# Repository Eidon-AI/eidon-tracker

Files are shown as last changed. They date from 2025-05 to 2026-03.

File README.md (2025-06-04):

# Eidon Tracker

A complete Bluetooth IMU tracking system featuring custom hardware, 3D printed enclosure, and web-based applications. The Eidon Tracker transmits real-time quaternion orientation data over Bluetooth HID, making it perfect for motion capture, gaming, and interactive applications.

<div align="center">
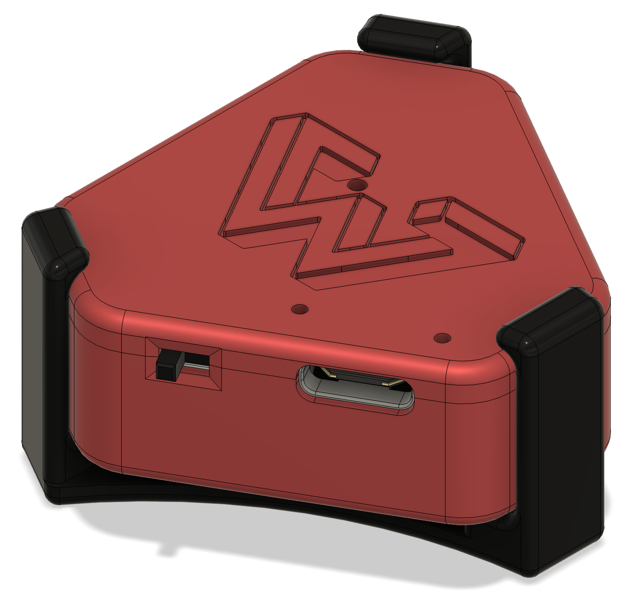
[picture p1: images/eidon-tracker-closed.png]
Eidon Tracker - Closed
  
</div>

## Features

- **High-precision IMU tracking** with BNO085 9-DOF sensor
- **Bluetooth HID device** - appears as standard input device
- **Real-time quaternion data** streaming at 1000Hz
- **Custom 3D printed enclosure** with integrated switches
- **Web-based applications** for visualization and interaction
- **Battery monitoring** with charging status
- **Device color customization** via HID feature reports

## Bill of Materials (BOM)

<div align="center">
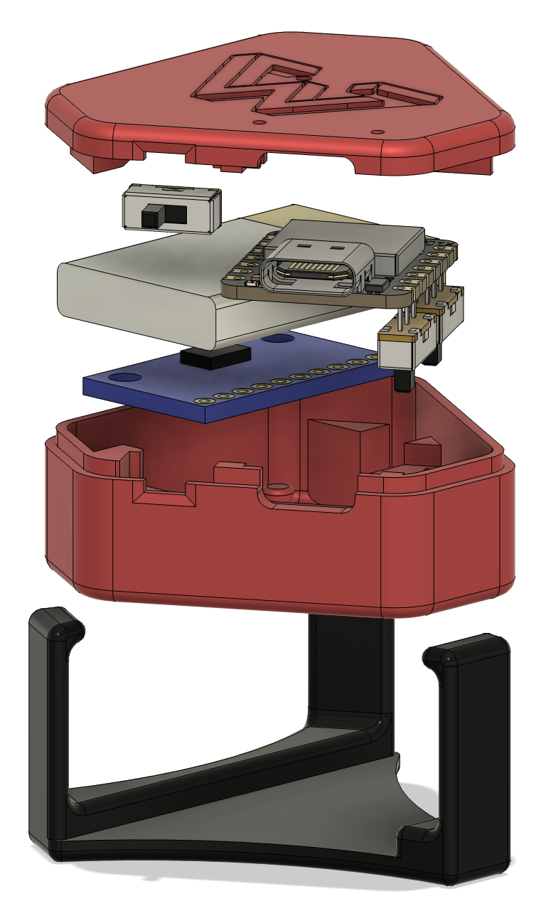
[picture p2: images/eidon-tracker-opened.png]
Eidon Tracker - Open
  
</div>

### Required Components

| Component | Quantity | Description | Purchase Link |
|---|---|---|---|
| [Seeed XIAO nRF52840 Sense](https://www.seeedstudio.com/XIAO-nRF52840-Sense-p-5256.html) | 1 | Main microcontroller with built-in BLE | [Amazon](https://amzn.to/4kR0hSP) |
| BNO085 IMU Breakout | 1 | 9-DOF Absolute Orientation Sensor | [Amazon](https://amzn.to/4mKZSTC) |
| LiPo Battery (3.7V) | 1 | 250mAh recommended | [Amazon](https://amzn.to/4kpmNSK) |
| Toggle Switches (6mm) | 2 | For power and position config | [Amazon](https://amzn.to/3ZfAECM) |
| 30 AWG Wires | 4x ~5cm | Female-to-female, ~20cm | [Amazon](https://amzn.to/4kB8Z7V) |

### 3D Printing Materials

| Material | Quantity | Description |
|---|---|---|
| PLA Filament | ~50g | For enclosure parts |
| Support Material | As needed | If printing with overhangs |

### Tools Required

- 3D Printer
- Soldering iron and solder
- Small screwdriver
- Wire strippers

**Estimated Total Cost**: $80-120 USD

## Hardware Setup

### Wiring Diagram

Connect the BNO085 to the XIAO nRF52840 Sense:

| BNO085 Pin | XIAO Pin | Function |
|---|---|---|
| VIN | 3V3 | Power (3.3V) |
| GND | GND | Ground |
| SDA | D9 | IMU I2C Data |
| SCL | D10 | IMU I2C Clock |
| INT | D8 | IMU Interrupt (optional) |

### Switch Connections

| Switch | Output Pin | Input Pin | Function |
|---|---|---|---|
| Left/Right | D5 | D6 | Horizontal orientation |
| Upper/Lower | D0 | D1 | Vertical orientation |

### 3D Printing

Print the following files from the `cad/` directory:

1. `eidon-tracker-base.stl` - Main enclosure base
2. `eidon-tracker-top.stl` - Enclosure lid  
3. `eidon-tracker-mount.stl` - Optional mounting bracket

**Print Settings:**
- Layer Height: 0.2mm
- Infill: 20%
- Support: Yes (for overhangs)
- Material: PLA

## Software Setup

### PlatformIO Installation

1. Install [Visual Studio Code](https://code.visualstudio.com/)
2. Install the [PlatformIO IDE extension](https://platformio.org/install/ide?install=vscode)

### Building and Uploading Firmware

1. Clone this repository:
   ```bash
   git clone https://github.com/yourusername/eidon-tracker.git
   cd eidon-tracker
   ```

2. Open the project in VSCode with PlatformIO

3. Connect your XIAO nRF52840 Sense via USB

4. Build and upload:
   ```bash
   pio run --target upload
   ```

### Dependencies

The following libraries are automatically managed by PlatformIO:

- **Adafruit BNO08x** (v1.2.3+) - IMU sensor driver
- **Adafruit BluefruitLE nRF52** - Bluetooth functionality  
- **Arduino Framework** - Core functionality

## Web Applications

The `web/` directory contains the main interactive application:

### 3D Orientation Visualizer (`index.html`)

- **Real-time 3D visualization** of tracker orientation and movement
- **Multiple camera angles** and viewing modes
- **Bluetooth HID integration** for seamless device connectivity
- **Calibration status monitoring** and quaternion data display

### Running Web Applications

Simply open `web/index.html` directly in your web browser:

1. Navigate to the `web/` directory in your file explorer
2. Double-click `index.html` to open it in your default browser
3. Or right-click and "Open with" your preferred browser (Chrome/Edge recommended for Web Bluetooth support)
4. Connect to your Eidon Tracker via Bluetooth

## HID Reports

The Eidon Tracker implements a custom HID device with multiple report types for data exchange:

### Input Report (Report ID: 1)
**Size**: 9 bytes total
- **Quaternion Data** (8 bytes): Four 16-bit values representing orientation
  - `w` component (bytes 0-1): Scalar part of quaternion
  - `x` component (bytes 2-3): X-axis rotation
  - `y` component (bytes 4-5): Y-axis rotation  
  - `z` component (bytes 6-7): Z-axis rotation
- **Switch States** (1 byte): Two button states plus padding
  - Bit 0: Left/Right switch state
  - Bit 1: Upper/Lower switch state
  - Bits 2-7: Reserved (padding)

### Output Report (Report ID: 1)
**Size**: 1 byte
- **Vendor Command**: Custom command byte for device control
  - Used for device configuration and special commands
  - Values defined in firmware for various operations

### Feature Report (Report ID: 1)  
**Size**: 3 bytes
- **RGB Color Settings**: Device LED color configuration
  - Byte 0: Red component (0-255)
  - Byte 1: Green component (0-255)
  - Byte 2: Blue component (0-255)
  - Colors are stored in device flash memory
  - Allows customization of device LED color

### HID Usage Pages
- **Primary**: Sensor Page (0x20) - Orientation Usage (0x80)
- **Secondary**: Button Page (0x09) - Button 1-2
- **Vendor**: Custom Page (0xFF00) - Vendor-specific features

## Usage

### Initial Setup

1. **Power on** the device - LED will indicate status
2. **Pair via Bluetooth** - Device appears as "Eidon Tracker XXXX"
3. **Calibrate IMU** - Wave device in figure-8 pattern until calibrated
4. **Open web application** of choice
5. **Connect** to device in web browser

### Calibration Process

The BNO085 sensor requires calibration for optimal performance:

1. **Gyroscope**: Keep device stationary for 2-3 seconds
2. **Accelerometer**: Slowly rotate through all orientations  
3. **Magnetometer**: Move device in figure-8 pattern away from magnetic interference
4. Monitor calibration status in web application or serial output

### LED Status Indicators

| LED State | Meaning |
|---|---|
| Solid Blue | Connected and ready |
| Blinking Blue | Advertising/pairing mode |
| Red | Low battery or error |
| Green | Charging |

## Development

### Project Structure

```
eidon-tracker/
├── firmware/               # PlatformIO firmware project
│   ├── src/main.cpp       # Main firmware source
│   ├── platformio.ini     # PlatformIO configuration
│   └── lib/               # Custom libraries
├── web/                   # Web applications
│   ├── index.html         # 3D orientation visualizer
│   └── script.js          # Shared JavaScript libraries
├── cad/                   # 3D printing files
│   ├── eidon-tracker.f3d  # Fusion 360 source
│   ├── *.stl              # STL files for printing
│   └── *.gcode            # Pre-sliced files
├── images/                # Product photos
└── README.md              # This file
```

### Firmware Development

The firmware is built on the Arduino framework with PlatformIO. Key components:

- **HID Report Descriptor**: Custom HID device with quaternion data
- **Bluetooth Stack**: Adafruit Bluefruit nRF52 library
- **IMU Driver**: Adafruit BNO08x library
- **Battery Management**: Built-in XIAO charging and monitoring

### Adding New Web Applications

1. Create new HTML file in `web/` directory
2. Include `script.js` for Bluetooth connectivity
3. Implement HID report parsing for quaternion data
4. Add visualization or interaction logic

## Troubleshooting

### Connection Issues

- **Device not found**: Ensure Bluetooth is enabled and device is in pairing mode
- **Connection drops**: Check battery level and distance from host device
- **Web Bluetooth not supported**: Use Chrome/Edge on desktop or Android

### Calibration Problems

- **Poor tracking accuracy**: Ensure proper IMU calibration
- **Drift over time**: Recalibrate magnetometer away from metal objects
- **Erratic behavior**: Check wiring connections and power supply

### Build Issues

- **Platform not found**: Ensure Seeed nRF52 platform is properly installed
- **Library conflicts**: Clean build environment with `pio run --target clean`
- **Upload fails**: Double-tap reset button to enter DFU mode

## Contributing

1. Fork the repository
2. Create a feature branch
3. Make your changes
4. Test thoroughly
5. Submit a pull request

## License

This project is open source and available under the MIT License. See LICENSE file for details.

## Acknowledgments

- [Seeed Studio](https://www.seeedstudio.com/) for the excellent XIAO nRF52840 Sense board
- [Adafruit](https://www.adafruit.com/) for comprehensive sensor libraries and breakout boards
- [PlatformIO](https://platformio.org/) for the excellent development environment

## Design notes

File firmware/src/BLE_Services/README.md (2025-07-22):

# BLE Services

This folder contains all BLE-related service definitions, callbacks, and polling systems for the Eidon Tracker.

## Files

### BLE Callbacks
- **BLE_Callbacks.h/cpp** - Callback classes for BLE events
  - `ServerCallbacks` - Connection/disconnection events
  - `QuaternionCharCallbacks` - Quaternion characteristic events
  - `CalibrationCallbacks` - IMU calibration commands (legacy - being replaced by polling)
  - `HubClientCallbacks` - Child device connection events

### BLE Polling Service
- **BLE_Polling_Service.h/cpp** - Centralized polling system for BLE characteristics
  - `BLEPollingManager` - Main polling manager class
  - Handles Role changes, Calibration requests, and Color changes
  - Provides statistics, error handling, and dynamic configuration
  - Supports battery and performance modes

### Role Configuration Service
- **RoleConfig_Service.h/cpp** - Device role configuration service
  - `RoleConfigData` struct for role information
  - Handles device role assignment and management
  - Integrated with polling system for reliable role changes

## Polling System

The BLE Polling Service replaces unreliable callbacks with a robust polling system for critical device functions:

### Supported Polling Targets
1. **Role Changes** - 200ms interval (5Hz)
   - Detects single-byte role values (0x00-0x06)
   - Updates device configuration and LED feedback
   
2. **Calibration Requests** - 100ms interval (10Hz)
   - Detects calibration commands
   - Triggers IMU reset and LED feedback
   
3. **Color Changes** - 150ms interval (~7Hz)
   - Detects 3-byte RGB color values
   - Updates color manager and LED feedback

### Features
- **Dynamic Configuration**: Adjust polling intervals at runtime
- **Battery Mode**: Slower polling to conserve power
- **Performance Mode**: Faster polling for responsiveness
- **Error Handling**: Automatic failure detection and recovery
- **Statistics**: Comprehensive performance monitoring
- **Debug Mode**: Detailed logging for troubleshooting

### Usage
```cpp
#include "BLE_Services/BLE_Polling_Service.h"

// Initialize polling system
pollingManager.begin();

// Add polling targets
pollingManager.addTarget(roleConfigChar, 200, handleRoleChange, "Role");
pollingManager.addTarget(calibrationChar, 100, handleCalibration, "Calibration");
pollingManager.addTarget(colorChar, 150, handleColorChange, "Color");

// In main loop
pollingManager.update();

// Configuration
pollingManager.setDebugMode(true);
pollingManager.setBatteryMode(lowBattery);
pollingManager.printStats();
```

## Usage

All BLE components are included in `main.cpp`:
```cpp
#include "BLE_Services/BLE_Callbacks.h"
#include "BLE_Services/BLE_Polling_Service.h"
#include "BLE_Services/RoleConfig_Service.h"
```

The services provide quaternion data transmission via custom GATT service:
- **GATT**: Custom service for direct quaternion access and device control
- **Role Configuration**: Device role assignment and management
- **Hub Functionality**: Child device connection and data aggregation

The polling system handles critical device interactions reliably, while callbacks handle connection events and quaternion subscriptions.

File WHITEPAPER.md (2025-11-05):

# EIDON TRACKER SYSTEM
## A High-Precision Wearable IMU Platform for Embodied AI Training Data Collection

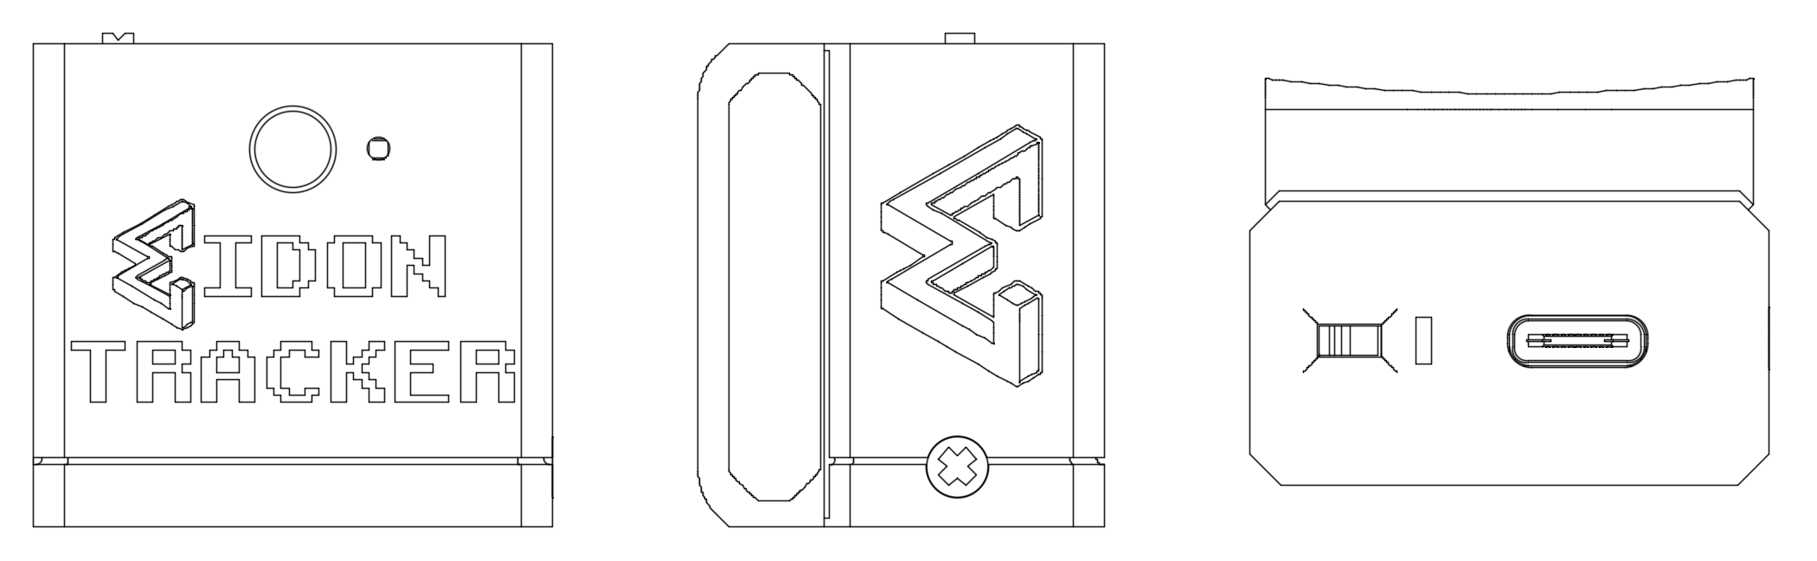
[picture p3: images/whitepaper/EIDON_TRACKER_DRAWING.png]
Eidon Tracker - Technical illustration


**Version 1.0**
**Date: November 2025**

---

## Table of Contents

1. [Executive Summary](#1-executive-summary)
2. [System Overview](#2-system-overview)
3. [Hardware Platform](#3-hardware-platform)
4. [Firmware & Embedded Software](#4-firmware--embedded-software)
5. [Data Collection & Processing Pipeline](#5-data-collection--processing-pipeline)
6. [Mathematical Framework](#6-mathematical-framework)
7. [Integration Ecosystem](#7-integration-ecosystem)
8. [Applications & Use Cases](#8-applications--use-cases)
9. [Technical Specifications](#9-technical-specifications)
10. [Conclusion](#10-conclusion)

---

## 1. Executive Summary

### The Embodied AI Data Challenge

The field of humanoid robotics stands at a critical inflection point. While Large Language Models (LLMs) have revolutionized AI through massive-scale training on web-scraped text data, embodied AI systems lack equivalent datasets. Current approaches to humanoid robot training rely on:

- **Laboratory teleoperation**: Expensive, controlled environments with fixed capture systems
- **Limited mobility**: Robots cannot learn tasks outside specialized facilities
- **Scale limitations**: Data collection is slow, costly, and geographically constrained
- **Missing human context**: Training data lacks the natural variability of real-world human movement

### The Eidon Solution

The **Eidon Tracker System** bridges this data gap by enabling **field-deployable, full-body motion capture** for creating Vision-Language-Action (VLA) training datasets. Our platform allows researchers to collect embodied AI training data anywhere humans perform tasks—from kitchens to construction sites to healthcare facilities.

**Key Value Propositions:**

- **Wearable precision tracking**: 7-device system captures full upper body kinematics with ±1-2° accuracy
- **High-speed data acquisition**: 48Hz IMU sampling with real-time quaternion streaming via BLE
- **Field-deployable design**: Battery-powered, wireless, robust 3D-printed enclosures with integrated mounting
- **Synchronized multimodal capture**: IMU orientation data timestamped with head-mounted camera video
- **Complete vertical integration**: Custom PCB, firmware, enclosure, and data processing pipeline
- **Open architecture**: Integration-ready for third-party VLA training pipelines and robotic platforms

### The "LLM Moment" for Humanoid Robotics

Just as LLMs achieved breakthrough performance through massive-scale diverse training data, humanoid robots require rich datasets of human manipulation tasks paired with visual context. Eidon Tracker makes this data economically feasible to collect at scale, enabling:

- **Diverse task libraries**: Collect thousands of task demonstrations across varied environments
- **Natural variability**: Capture how different humans approach the same task
- **Context-rich training**: Pair skeletal kinematics with egocentric video for multimodal learning
- **Rapid iteration**: Quickly create bespoke datasets for new domains (healthcare, manufacturing, domestic, etc.)

**Target Applications:**
- VLA model training for humanoid manipulation
- Teleoperation interfaces for remote robotics
- Biomechanics research and ergonomic analysis
- Motion capture for animation and VR/AR
- Physical therapy and rehabilitation monitoring

---

## 2. System Overview

### Architecture

The Eidon ecosystem consists of three integrated subsystems:

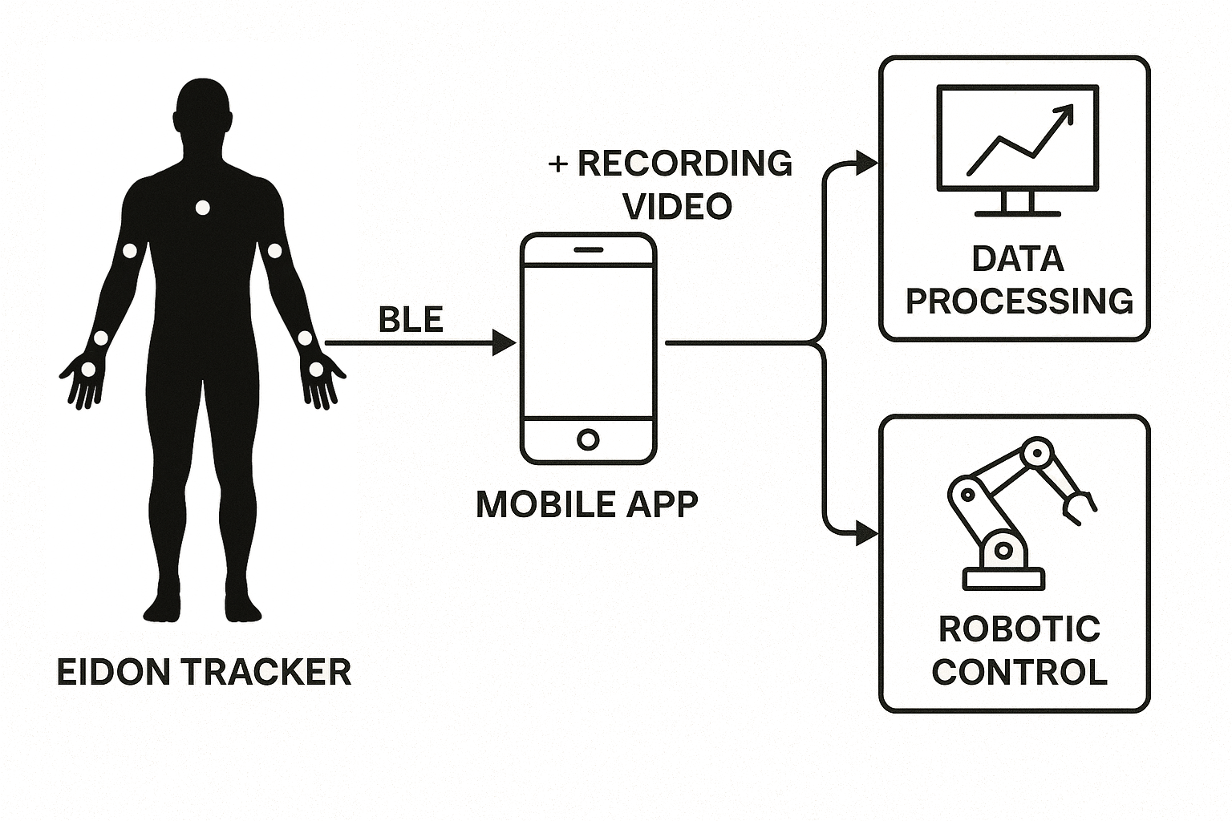
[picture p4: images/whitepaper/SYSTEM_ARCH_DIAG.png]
System Architecture Diagram - Complete ecosystem from capture to training


#### 2.1 Eidon Tracker Hardware

Seven wearable IMU devices providing real-time orientation tracking:

- **3 × Upper extremity pairs**: Left/right hand, forearm, upper arm
- **1 × Torso tracker**: Chest-mounted reference frame

Each device contains:
- Custom 2-layer PCB with ESP32-C6 microcontroller
- BNO085 9-DOF IMU with hardware sensor fusion
- LiPo battery with voltage monitoring
- Status LED indicators
- Injection-moldable 3D-printed enclosure with integrated mounting
- Multi-protocol wireless (BLE + ESP-NOW)

#### 2.2 Mobile Application Hub

Smartphone app serving as central data aggregator:

- **BLE connectivity**: Receives 48Hz quaternion streams from all 7 trackers
- **Video capture**: Records timestamped head-mounted POV video
- **Data synchronization**: Aligns IMU and video timestamps
- **Storage & export**: Packages datasets for offline processing

#### 2.3 Data Processing Pipeline (eidon-sim)

Real-time and post-processing kinematics engine:

- **Quaternion-to-Euler conversion**: Extract anatomical joint angles
- **Forward kinematics**: Build 3D skeletal representation from orientation data
- **Inverse kinematics**: Derive joint angles from chained vectors
- **Filtering & smoothing**: Temporal consistency and noise reduction
- **3D visualization**: Real-time debugging and validation interface

### Data Flow

```
┌─────────────────────────────────────────────────────────────────────┐
│  CAPTURE PHASE (In-Field)                                           │
├─────────────────────────────────────────────────────────────────────┤
│  Human performs task wearing 7 Eidon Trackers + head-mounted phone │
│                                                                      │
│  IMU (48Hz) ──┬──► BLE ──┬──► Mobile App ──► Raw Dataset           │
│               │          │                                          │
│               └─ Quat ──┘                                          │
│                                                                      │
│  Phone Camera ───────────► Timestamped Video ──► Synchronized      │
└─────────────────────────────────────────────────────────────────────┘

┌─────────────────────────────────────────────────────────────────────┐
│  PROCESSING PHASE (Post-Collection)                                 │
├─────────────────────────────────────────────────────────────────────┤
│  Raw Dataset ──► eidon-sim ──┬──► 7-DOF Joint Angles               │
│                               │                                      │
│                               ├──► 3D Skeletal Trajectory           │
│                               │                                      │
│                               └──► Aligned Video Frames             │
└─────────────────────────────────────────────────────────────────────┘

┌─────────────────────────────────────────────────────────────────────┐
│  TRAINING PHASE (VLA Pipeline)                                      │
├─────────────────────────────────────────────────────────────────────┤
│  Processed Dataset ──► VLA Training ──► Humanoid Control Policy    │
└─────────────────────────────────────────────────────────────────────┘
```

### Wearing Configuration

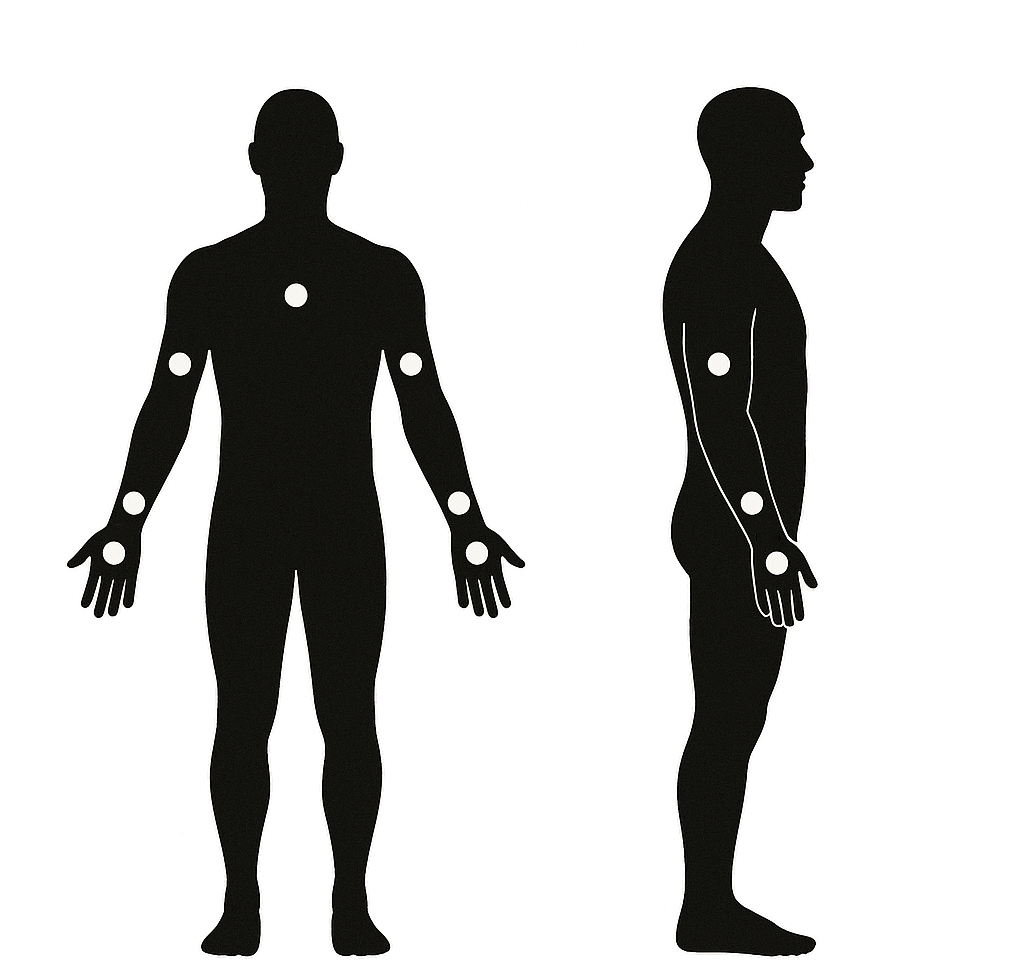
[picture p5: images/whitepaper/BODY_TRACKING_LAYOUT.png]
Body Tracking Layout - Front and side view showing 7 tracker placement positions


**Tracker Placement:**
- **Chest**: Center of sternum (reference frame)
- **Left/Right Upper Arm**: Lateral humerus (upper arm)
- **Left/Right Forearm**: Posterior radius (back of forearm)
- **Left/Right Hand**: Dorsal metacarpals (back of hand)

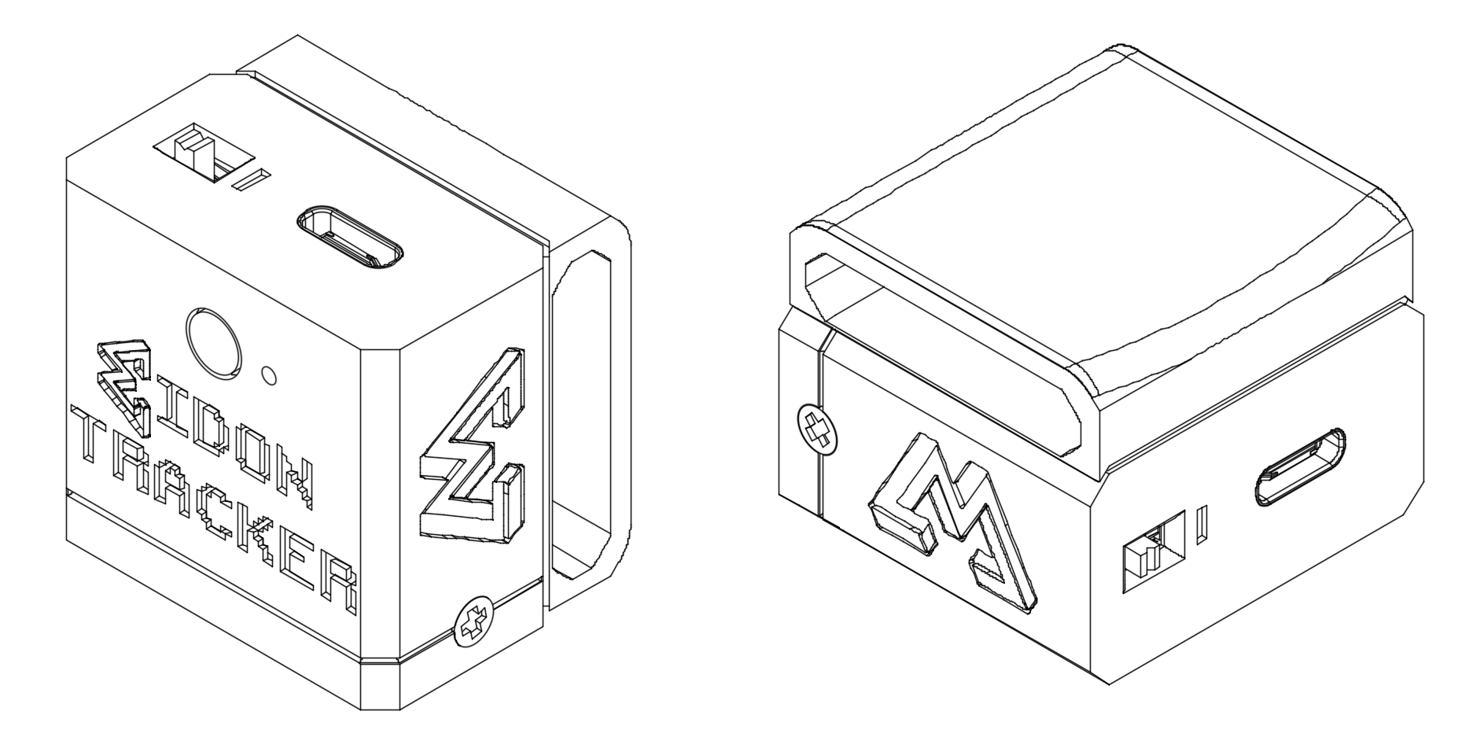
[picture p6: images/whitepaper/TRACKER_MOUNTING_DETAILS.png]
Tracker Mounting Details - Close-up showing strap mounting and attachment mechanism


### Key System Specifications (Summary)

| Specification | Value |
|---|---|
| **Number of tracking points** | 7 (chest, 2× upper arm, 2× forearm, 2× hand) |
| **IMU sampling rate** | 48 Hz |
| **Orientation accuracy** | ±1-2° RMS |
| **Wireless protocol** | BLE 5.0 (to mobile) + ESP-NOW (device-to-device) |
| **Battery life** | 8-12 hours continuous operation |
| **Latency** | <50ms end-to-end (IMU → mobile app) |
| **Form factor** | 45×30×15mm per tracker |
| **Weight** | ~25g per tracker with battery |
| **Cost per device** | $30.84 (current production) |
| **Complete 7-device system** | $278.87 (including harness and charging hub) |

---

## 3. Hardware Platform

The Eidon Tracker hardware represents a complete custom solution optimized for wearable motion capture. Each of the seven devices is identical, with role assignment configured via software.

### 3.1 Custom PCB Design

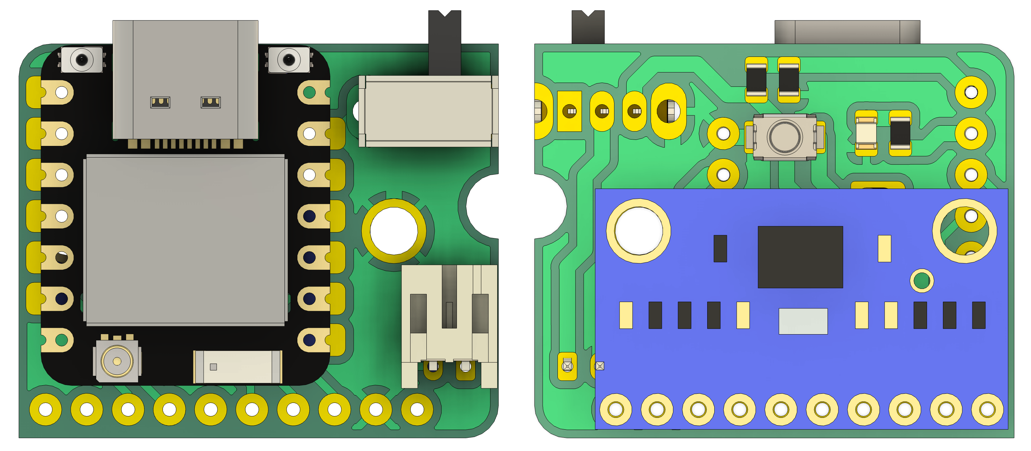
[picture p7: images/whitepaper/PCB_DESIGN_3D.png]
PCB Design - Custom circuit board layout and schematic


#### PCB Specifications

- **Board dimensions**: 25×20mm
- **Layer count**: 2-layer FR4
- **Thickness**: 1.6mm
- **Copper weight**: 1 oz (35µm)
- **Finish**: ENIG (Electroless Nickel Immersion Gold) for reliable soldering
- **Assembly**: PCBA-ready with pick-and-place files

#### Key Components

| Component | Part Number | Function | Key Specs |
|---|---|---|---|
| **Microcontroller** | Seeed XIAO ESP32-C6 | Dual-mode wireless + processing | RISC-V 160MHz, 512KB SRAM, BLE 5.0, WiFi 6 |
| **IMU** | Bosch BNO085 | 9-DOF sensor fusion | ±2000°/s gyro, ±16g accel, hardware quaternion |
| **LED** | Kingbright APT2012YC | Status indicator | Yellow 0805 SMD, 20mcd @ 20mA |
| **Resistors** | Yageo RC0805 | Voltage divider + LED limiting | 220kΩ (×2), 1kΩ (×1), ±1% tolerance |
| **Button** | Alps SKRKAEE020 | User input | Tactile, 50mA rating, 160gf actuation |

#### Power Subsystem

**Battery Monitoring Circuit:**
- **Voltage divider**: 2× 220kΩ resistors create 2:1 ratio
- **ADC input**: ESP32-C6 GPIO0 (12-bit resolution)
- **Measurement range**: 0-8.4V (accommodates 2S LiPo configurations)
- **Accuracy**: ±50mV across battery discharge curve
- **Update rate**: 5-second intervals to conserve power

**Battery specification:**
- **Chemistry**: LiPo (Lithium Polymer)
- **Nominal voltage**: 3.7V
- **Capacity**: 150-300mAh (depending on size constraints)
- **Protection**: Built-in overcharge/discharge/short circuit protection
- **Connector**: JST PH 2.0mm

#### Communication Interfaces

**I2C Bus (IMU Interface):**
- **Speed**: 400 kHz (Fast Mode)
- **Pins**: GPIO19 (SCL), GPIO20 (SDA)
- **Pull-ups**: Internal ESP32 pull-ups enabled
- **Address**: 0x4B (configurable via GPIO18)

**Status Outputs:**
- **Main LED**: GPIO15 (connection state)
- **Aux LED**: GPIO1/A1 (activity indicator)
- **Drive current**: ~2mA per LED (optimized for visibility + battery life)

### 3.2 Mechanical Design

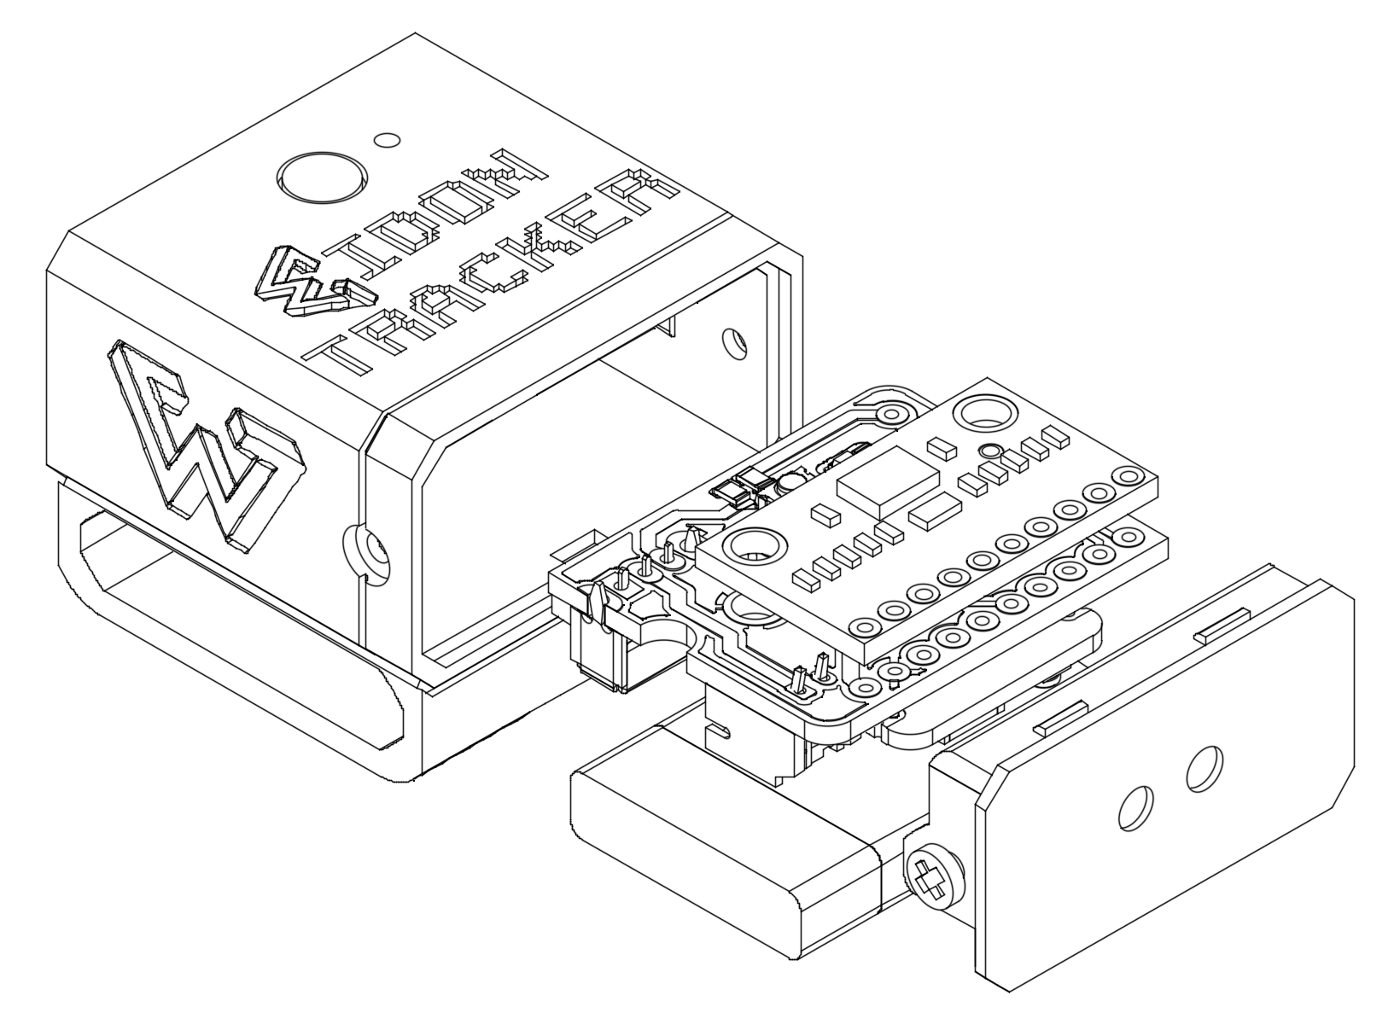
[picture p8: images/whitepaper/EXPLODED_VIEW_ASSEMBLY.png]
Exploded View Assembly - CAD rendering showing all components separated


**Component Stack (top to bottom):**
- Top lid with button access hole
- Main enclosure body with PCB mounting posts
- PCB with battery underneath
- Integrated mounting strap channels
- Bottom face with logo/ventilation

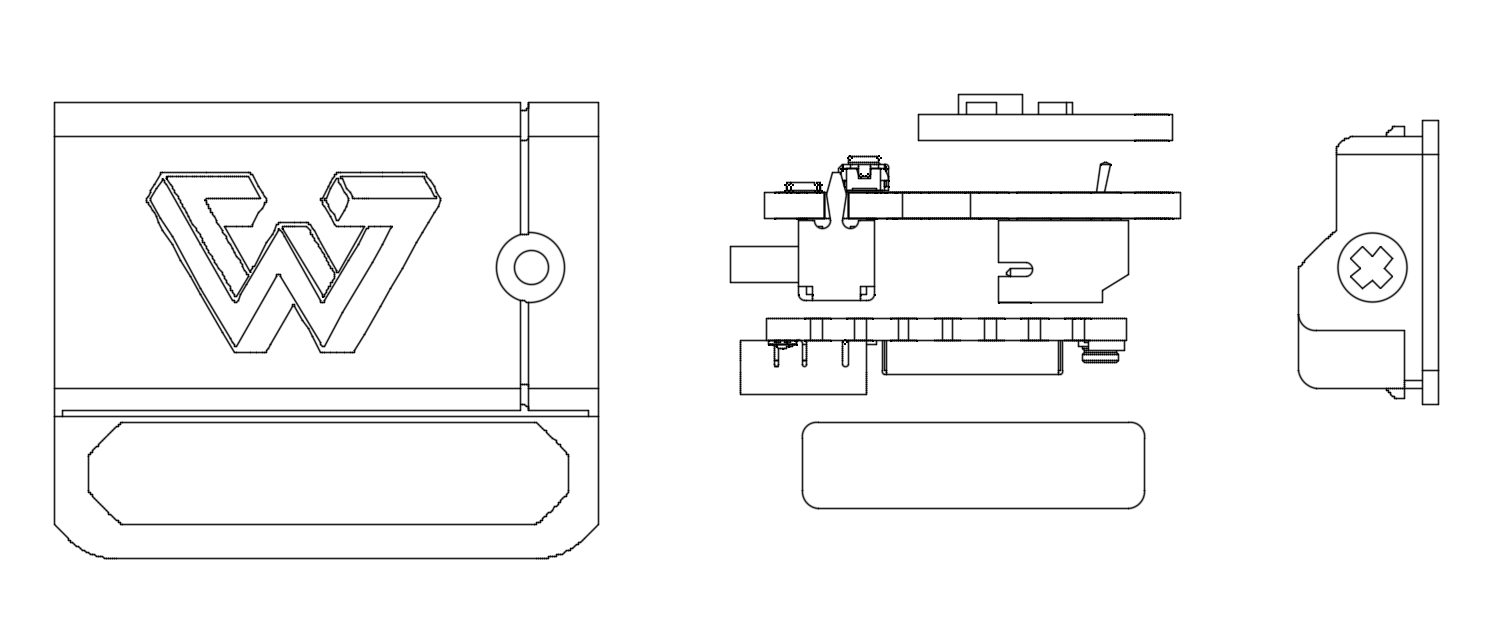
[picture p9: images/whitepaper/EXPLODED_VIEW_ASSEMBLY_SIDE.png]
Exploded View Assembly - Side perspective showing internal layout


#### Enclosure Specifications

**Current Design**: Version 3b (eidon-tracker-v3b)

- **Overall dimensions**: 45mm (L) × 30mm (W) × 15mm (H)
- **Volume**: ~20 cm³
- **Material**: PLA or ABS (3D printed), injection-mold-ready geometry
- **Wall thickness**: 2.0mm (structural sections), 1.5mm (flexible clips)
- **Mounting**: Integrated strap channels for 20mm elastic bands
- **Sealing**: Friction-fit lid with overlapping lip (IP42 equivalent)

**Design Features:**
- **PCB mounting posts**: Four 2mm diameter posts with press-fit or screw retention
- **Battery cavity**: Optimized for 40×20×10mm LiPo cells
- **LED light pipes**: Translucent channels guide status LED to external face
- **Button actuator**: Sliding plunger transfers force to PCB-mounted switch
- **Cable routing**: Strain relief channel for charging cable (if applicable)
- **Labeling surfaces**: Recessed areas for role identification stickers

#### Mounting System

<div class="side-by-side">
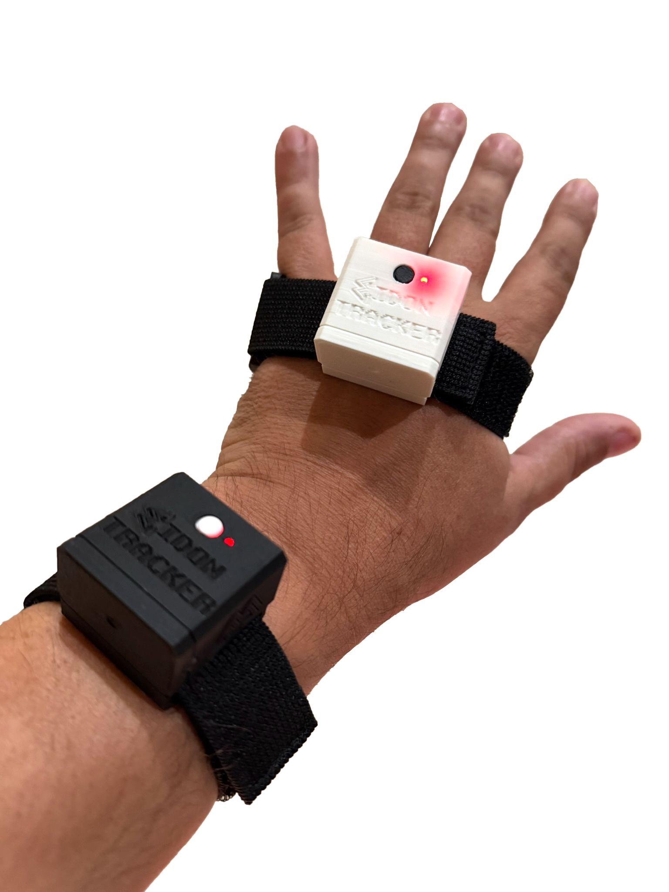
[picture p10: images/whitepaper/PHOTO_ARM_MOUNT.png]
Arm Mount - Elastic strap mounting on forearm

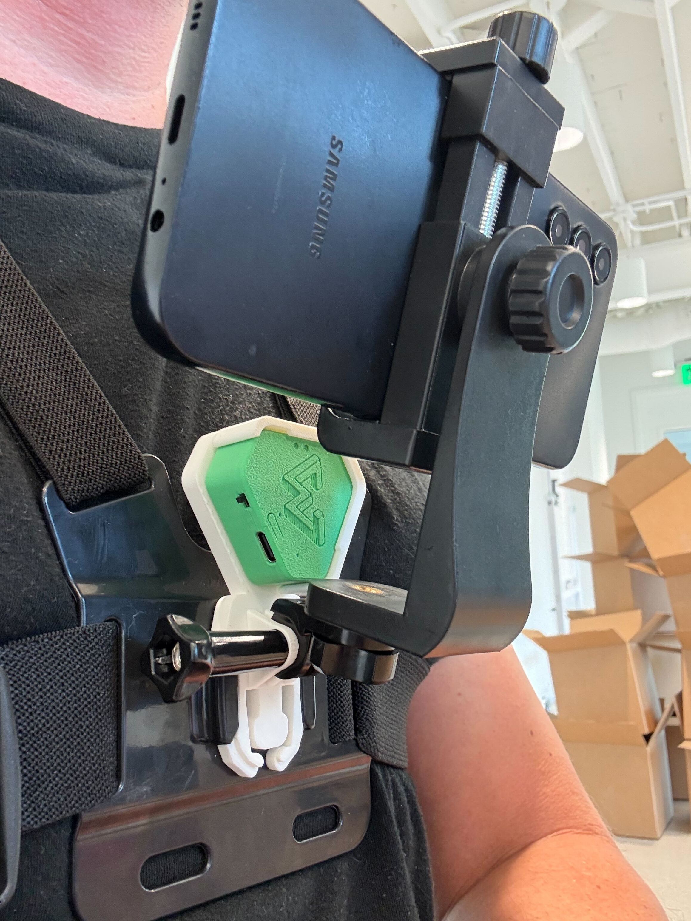
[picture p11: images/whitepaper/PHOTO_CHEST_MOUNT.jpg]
Chest Mount - Harness system for torso tracking

</div>

**Integrated Mounting System:**
- Strap channels are built directly into the enclosure body (no separate bracket required)
- 20mm elastic webbing threads through molded slots on sides of enclosure
- Allows for quick attachment/removal while maintaining secure fit
- Earlier design iterations used separate STL mounting brackets (deprecated in v3b)

**Strap specifications:**
- **Material**: Elastic webbing or neoprene
- **Width**: 20mm (standard) or 25mm (chest)
- **Closure**: Hook-and-loop (Velcro) or buckle
- **Tension**: Adjustable to accommodate varied body sizes

#### Manufacturing Considerations

**3D Printing Parameters:**
- **Layer height**: 0.2mm (standard quality)
- **Infill**: 20% gyroid or honeycomb
- **Supports**: Required for button plunger and undercuts
- **Print time**: ~1 hour per enclosure body, 20min per lid
- **Post-processing**: Minimal; light sanding on mating surfaces

**Injection Molding Readiness:**
- Draft angles: 2° on all vertical walls
- No undercuts (except designed-in snap features)
- Uniform wall thickness for even cooling
- Ejector pin locations planned in non-cosmetic areas

### 3.3 Bill of Materials (Complete Device)

| Category | Item | Quantity | Unit Cost | Notes |
|---|---|---|---|---|
| **MCU** | Seeed XIAO ESP32-C6 | 1 | $5.20 | Includes castellated module |
| **IMU** | BNO085 breakout | 1 | $17.51 | Pre-calibrated module |
| **Battery** | LiPo (200-300mAh) | 1 | $4.59 | With protection circuit |
| **Power Switch** | Slide/toggle switch | 1 | $0.08 | SPDT switch |
| **Enclosure** | 3D-printed body + lid + button | 1 | $0.46 | PLA filament (amortized) |
| **Mounting** | Elastic strap with Velcro | 1 | $3.00 | 20mm elastic webbing |
| **Cable** | USB-C charging cable | 1 | $1.13 | Data + charging |
| **TOTAL** | | | **$30.84** | Per device |
| **7-device system** | | | **$215.88** | Trackers only |

**Complete 7-Device Kit (Ready to Use):**

| Item | Quantity | Unit Cost | Total |
|---|---|---|---|
| Eidon Tracker devices | 7 | $30.84 | $215.88 |
| Chest harness | 1 | $24.00 | $24.00 |
| USB charging hub | 1 | $35.99 | $35.99 |
| Extra straps (chest mount) | 1 | $3.00 | $3.00 |
| **TOTAL SYSTEM COST** | | | **$278.87** |

**Cost reduction at scale:**
- 100-unit production: ~$24/device ($168 for 7-device system)
- 1000-unit production: ~$18/device ($126 for 7-device system, IMU bulk pricing)

---

## 4. Firmware & Embedded Software

The Eidon Tracker firmware is a sophisticated real-time system managing sensor fusion, wireless communication, power optimization, and multi-device coordination.

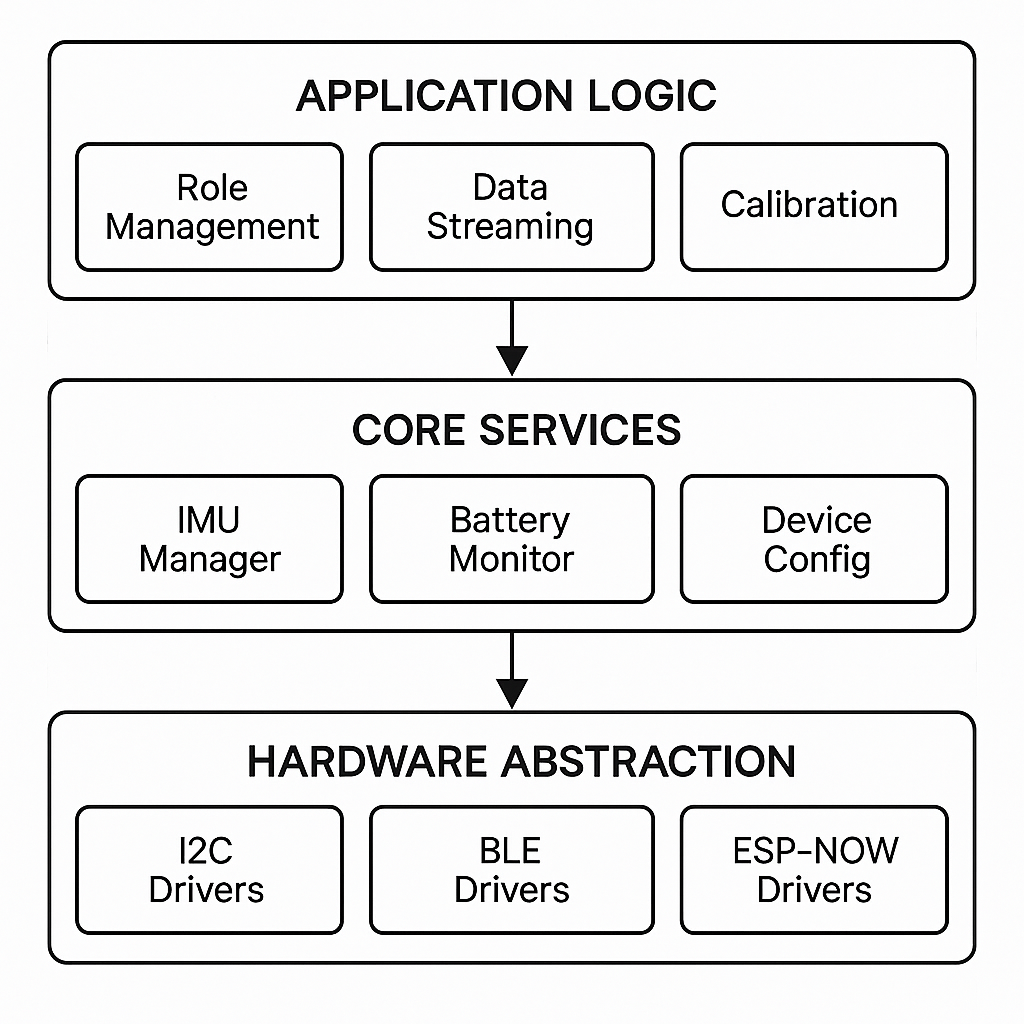
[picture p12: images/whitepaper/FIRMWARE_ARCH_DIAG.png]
Firmware Architecture Diagram - Layered software architecture and data flow


### 4.1 Development Environment

- **Framework**: Arduino (C/C++)
- **Build system**: PlatformIO
- **Target**: Espressif ESP32-C6 (RISC-V architecture)
- **Toolchain**: GCC 11.2+ for RISC-V
- **Flash size**: 4MB
- **OTA updates**: Supported via BLE (future feature)

**Key dependencies:**
- `Adafruit_BNO08x` v1.2.3+: IMU driver with quaternion output
- `NimBLE-Arduino` v2.3.1+: Lightweight BLE stack
- `ResponsiveAnalogRead` v1.2.1: Debounced ADC sampling

### 4.2 Core Firmware Capabilities

#### A. IMU Sensor Integration

**Sensor configuration** (from `firmware/lib/BNO085/BNO085.cpp`):

```cpp
// Initialize I2C communication at 400kHz
Wire.setPins(SDA_PIN, SCL_PIN);  // GPIO20, GPIO19
Wire.begin();
Wire.setClock(400000);

// Configure BNO085 for game rotation vector mode
bno08x.enableReport(SH2_GAME_ROTATION_VECTOR, 20833);  // 48Hz (20.83ms)
```

**Data acquisition loop** (48Hz):

```cpp
if (bno08x.getSensorEvent(&sensorValue)) {
  if (sensorValue.sensorId == SH2_GAME_ROTATION_VECTOR) {
    // Extract quaternion components
    float qw = sensorValue.un.gameRotationVector.real;
    float qx = sensorValue.un.gameRotationVector.i;
    float qy = sensorValue.un.gameRotationVector.j;
    float qz = sensorValue.un.gameRotationVector.k;

    // Apply 180° Z-axis rotation correction for mounting orientation
    currentQuaternion.w = qw;
    currentQuaternion.x = -qx;
    currentQuaternion.y = -qy;
    currentQuaternion.z = qz;
  }
}
```

**Why game rotation vector?**
- Fuses gyroscope + accelerometer (no magnetometer)
- Immune to magnetic interference (ferrous materials, electronics)
- Lower latency than full sensor fusion
- Ideal for relative tracking where absolute north is irrelevant

**Calibration mechanism:**
- **Trigger**: BLE command (0x01) or double-tap gesture detected by IMU
- **Action**: Send `MODE_SLEEP` → `MODE_ON` sequence to restart sensor fusion
- **LED feedback**: 300ms solid indicator during reset
- **Multi-device**: Hub role can broadcast calibration command to children via ESP-NOW

#### B. Dual-Radio Wireless Architecture

The firmware implements a unique **BLE + ESP-NOW** dual-protocol system for efficient multi-device coordination.

**BLE (Bluetooth Low Energy) - Primary Interface:**

Custom GATT service: `E1D00001-8B5A-3E5B-9E23-4F9B5C91BBDE`

| Characteristic UUID | Type | Function | Data Format |
|---|---|---|---|
| `E1D00002` | Read/Notify | Quaternion stream | 16 bytes: 4× float32 (w,x,y,z) |
| `E1D00003` | Read/Write | Calibration command | 1 byte: 0x01 = reset |
| `E1D00005` | Read | Device info | 14 bytes: ID, FW ver, battery%, role, MAC |
| `E1D00007` | Read/Write | Role configuration | 7 bytes: role (1) + hub MAC (6) |
| `E1D00008` | Read/Notify | Hand quaternion (hub aggregator) | 16 bytes |
| `E1D00009` | Read/Notify | Forearm quaternion (hub aggregator) | 16 bytes |

**BLE notification rate**: 24Hz (42ms intervals) to balance throughput and power

**Connection parameters:**
- Advertising interval: 100-200ms (discoverable mode)
- Connection interval: 7.5-20ms (low latency)
- Slave latency: 0 (no skipped events)
- Supervision timeout: 4000ms

**ESP-NOW - Child-to-Hub Communication:**

**When used:**
- Devices assigned forearm or hand roles
- Hub device (upper arm) aggregates data from hand + forearm
- Eliminates need for mobile app to manage 3× BLE connections per arm

**Protocol details:**
```cpp
// ESP-NOW packet structure (20 bytes)
struct ESPNowQuaternionPacket {
  uint8_t messageType;   // 0x01 = quaternion data, 0x02 = command
  uint8_t senderRole;    // ROLE_LEFT_HAND, ROLE_RIGHT_FOREARM, etc.
  uint8_t reserved[2];
  float qw, qx, qy, qz;  // 16 bytes
} __attribute__((packed));
```

**Transmission rate**: 48Hz (matches IMU sampling)
**Channel**: WiFi Channel 1 (2412 MHz)
**Range**: 20-50m line-of-sight
**Latency**: <5ms typical

**Power optimization:**
- Children enter "ESP-NOW only" mode after 60s of BLE inactivity
- Hub remains BLE-connected to mobile app
- Reduces overall system power consumption by ~40%

#### C. Device Role System

**Seven role types** (configured via BLE characteristic `E1D00007`):

```cpp
enum DeviceRole {
  ROLE_LEFT_HAND      = 0,
  ROLE_RIGHT_HAND     = 1,
  ROLE_LEFT_FOREARM   = 2,
  ROLE_RIGHT_FOREARM  = 3,
  ROLE_LEFT_HUB       = 4,  // Left upper arm (aggregator)
  ROLE_RIGHT_HUB      = 5,  // Right upper arm (aggregator)
  ROLE_CHEST          = 6,
  ROLE_UNKNOWN        = 255
};
```

**Role assignment workflow:**
1. Devices boot in `ROLE_UNKNOWN` (read from persistent NVS storage)
2. Mobile app scans for nearby trackers
3. User assigns roles via app UI (e.g., "This is my left hand")
4. App writes role + hub MAC address to characteristic `E1D00007`
5. Device saves to NVS, reboots with new configuration
6. Future power-ons remember role assignment

**Hub role behavior:**
- Advertises BLE service with hand/forearm characteristics (`E1D00008`, `E1D00009`)
- Listens for ESP-NOW packets from configured children
- Aggregates: Hub's own IMU (upper arm) + hand + forearm quaternions
- Notifies mobile app with all three data streams at 24Hz
- Forwards calibration commands to children

**Child role behavior:**
- Connects to hub's ESP-NOW address (stored during role assignment)
- Sends local IMU quaternions via ESP-NOW at 48Hz
- Timeouts BLE after 60s to save power
- Re-enables BLE if ESP-NOW connection lost (failsafe)

#### D. Power Management

**Battery monitoring** (`firmware/src/main.cpp`):

```cpp
#define BAT_PIN GPIO0
#define BAT_R1 220000  // Upper resistor (Ω)
#define BAT_R2 220000  // Lower resistor (Ω)
#define BAT_MAX_V 4.2  // Fully charged LiPo
#define BAT_MIN_V 3.0  // Safe discharge limit

float readBatteryVoltage() {
  int adcValue = analogRead(BAT_PIN);  // 12-bit: 0-4095
  float voltage = (adcValue / 4095.0) * 3.3 * 2.0;  // Voltage divider correction
  return voltage;
}

uint8_t calculateBatteryPercent(float voltage) {
  if (voltage >= BAT_MAX_V) return 100;
  if (voltage <= BAT_MIN_V) return 0;
  return (uint8_t)((voltage - BAT_MIN_V) / (BAT_MAX_V - BAT_MIN_V) * 100);
}
```

**Update interval**: Every 5 seconds (balances accuracy and ADC power consumption)

**Current consumption estimates** (from `docs/HARDWARE_OVERVIEW.md`):
- **Active mode** (BLE connected + IMU sampling): ~15mA average
- **ESP-NOW only mode** (BLE off, hub children): ~10mA average
- **Deep sleep** (future): <10µA

**Battery life calculation** (200mAh cell):
- Active mode: 200mAh / 15mA = **13.3 hours**
- ESP-NOW mode: 200mAh / 10mA = **20 hours**
- Mixed usage (40% active, 60% ESP-NOW): **~16 hours**

#### E. LED Status Indicators

**Main LED (GPIO15)** - Connection state:
- **Blinking (500ms on/off)**: Advertising, not connected
- **Rapid toggle (100ms)**: Connected to mobile app
- **Solid 300ms**: IMU calibration in progress
- **Off**: Deep sleep or error

**Auxiliary LED (GPIO1)** - Secondary indicator:
- **Blinking**: Advertising
- **Solid**: Connected

### 4.3 Firmware Performance Metrics

| Metric | Value | Notes |
|---|---|---|
| **IMU sampling rate** | 48 Hz | Hardware sensor fusion output |
| **BLE notification rate** | 24 Hz | Sufficient for smooth visualization |
| **ESP-NOW transmission** | 48 Hz | Child → hub, raw IMU rate |
| **End-to-end latency** | <50ms | IMU event → mobile app receipt |
| **Packet loss** | <0.1% | BLE in good signal conditions |
| **CPU utilization** | ~40% | Room for additional features |
| **RAM usage** | ~80KB / 256KB | 31% utilization |
| **Flash usage** | ~452KB / 4MB | 11% utilization |

### 4.4 Firmware File Structure

```
firmware/
├── src/
│   ├── main.cpp                    # Entry point, core loop (1,191 lines)
│   ├── DeviceConfig.h/cpp          # Persistent NVS storage for role
│   ├── BLE_Services/
│   │   ├── BLE_Callbacks.h/cpp    # Connection/disconnection handlers
│   │   └── BLE_Polling_Service.h/cpp  # Periodic characteristic reads
│   └── Role_Services/
│       ├── HubClient_Service.h/cpp    # ESP-NOW receiver (hub role)
│       ├── RoleConfig_Service.h/cpp   # Role assignment handler
│       └── Hub_Structures.h           # Shared data structures
├── lib/
│   ├── BNO085/                     # IMU driver wrapper
│   └── ColorManager/               # LED color control utilities
├── platformio.ini                  # Build configuration
└── ext_nimble_config.h             # NimBLE stack customization
```

**Key code locations:**
- Quaternion correction: `firmware/src/main.cpp:428-432`
- Battery monitoring: `firmware/src/main.cpp:156-178`
- Role configuration: `firmware/src/Role_Services/RoleConfig_Service.cpp`
- Hub aggregation: `firmware/src/Role_Services/HubClient_Service.cpp`

---

## 5. Data Collection & Processing Pipeline

The Eidon system transforms raw IMU quaternions into actionable skeletal kinematics through a sophisticated processing pipeline implemented in the **eidon-sim** repository.

<!-- **IMAGE PLACEHOLDER: Data Pipeline Flowchart**
*Description: Flowchart showing:*
1. *Raw quaternions (7 devices, 48Hz) → Mobile app aggregation*
2. *Timestamped video frames (30-60fps) → Mobile app storage*
3. *Synchronized dataset → eidon-sim processing*
4. *Output: 7-DOF joint angles, 3D skeletal trajectory, aligned video* -->

### 5.1 Mobile Application Hub

**Platform**: iOS/Android (Flutter framework)

**Core functions:**
1. **Multi-device BLE management**
   - Scans for Eidon Tracker devices
   - Connects to 3-5 devices simultaneously (chest + left/right hubs + optional extras)
   - Subscribes to quaternion notification characteristics
   - Handles reconnection logic for dropped connections

2. **Data aggregation**
   - Receives quaternion streams from 7 total IMUs (via direct connection or hub aggregation)
   - Timestamps each quaternion packet with system monotonic clock
   - Buffers data in memory (circular buffer, 10-second capacity)

3. **Video capture**
   - Records egocentric video at 30-60fps (device-dependent)
   - Embeds timestamps in video metadata track
   - Optional: Audio recording for task annotation

4. **Synchronization**
   - Aligns IMU timestamps with video frame timestamps
   - Accounts for BLE latency variability (~5-50ms jitter)
   - Uses device clock synchronization protocol

5. **Dataset export**
   - Packages IMU data (binary or JSON), video file, metadata into single archive
   - Optional cloud upload (future feature)

Mobile App Screenshot - Data collection interface with device status and recording controls

### 5.2 Quaternion Data Format

**Raw quaternion packet** (from BLE characteristic):

```
Byte offset | Field      | Type      | Description
------------|------------|-----------|----------------------------
0-3         | qw         | float32   | Quaternion scalar (real) component
4-7         | qx         | float32   | Quaternion i (x) vector component
8-11        | qy         | float32   | Quaternion j (y) vector component
12-15       | qz         | float32   | Quaternion k (z) vector component
```

**Quaternion properties:**
- Normalized: w² + x² + y² + z² = 1.0 (enforced by BNO085 firmware)
- Right-handed coordinate system
- Mounting correction pre-applied (180° Z-rotation)
- Represents rotation from sensor local frame → global reference frame

**Device info packet** (characteristic `E1D00005`):

```
Byte offset | Field         | Type    | Description
------------|---------------|---------|----------------------------
0           | device_id     | uint8   | Unique ID (0-255)
1           | fw_major      | uint8   | Firmware version major (currently 1)
2           | fw_minor      | uint8   | Firmware version minor (currently 2)
3           | battery_pct   | uint8   | Battery percentage (0-100)
4           | device_role   | uint8   | DeviceRole enum value
5-10        | mac_address   | uint8×6 | Bluetooth MAC address
```

### 5.3 eidon-sim Processing Engine

**Repository**: `~/eidon/eidon-sim`
**Framework**: TypeScript + Three.js
**Execution**: Web application (browser-based) or Node.js CLI

<!-- **IMAGE PLACEHOLDER: eidon-sim Screenshot**
*Description: Screenshot showing:*
- *3D viewport with skeletal avatar performing task*
- *Left sidebar: Device connection status*
- *Right sidebar: Real-time joint angle readouts (7-DOF per arm)*
- *Bottom: Timeline scrubber with video playback* -->

#### Core Processing Modules

**A. Quaternion Decoder** (`src/core/reportParsers.ts`)

Converts raw binary quaternion data to usable format:

```typescript
function decodeQuaternion(buffer: ArrayBuffer, offset: number): quat {
  const dv = new DataView(buffer);
  const qw = dv.getFloat32(offset + 0, true);  // Little-endian
  const qx = dv.getFloat32(offset + 4, true);
  const qy = dv.getFloat32(offset + 8, true);
  const qz = dv.getFloat32(offset + 12, true);
  return [qx, qy, qz, qw];  // gl-matrix format: [x, y, z, w]
}
```

**Coordinate frame transformation** (sensor → Three.js world):

```typescript
// Sensor coordinate frame: X=forward, Y=right, Z=up
// Three.js world frame: X=right, Y=up, Z=backward
const upZ = vec3.transformQuat(vec3.create(), [0, 0, 1], quaternion);
const up = [upZ[0], upZ[2], -upZ[1]];  // Swap Y↔Z, negate new Y

const fwdZ = vec3.transformQuat(vec3.create(), [0, 1, 0], quaternion);
const fwd = [fwdZ[0], fwdZ[2], -fwdZ[1]];
```

**B. Seven-Degree-of-Freedom Arm Solver** (`src/core/ArmSolver.ts`)

The ArmSolver class is the heart of the kinematics pipeline. It takes 3 quaternions (upper arm, forearm, hand) and outputs 7 anatomical joint angles:

**Shoulder joint (3-DOF):**
1. **Yaw** (internal/external rotation)
2. **Pitch** (flexion/extension)
3. **Roll** (abduction/adduction)

**Elbow joint (1-DOF):**
4. **Flex** (flexion/extension angle)

**Forearm (1-DOF):**
5. **Roll** (pronation/supination)

**Wrist joint (2-DOF):**
6. **Yaw** (ulnar/radial deviation)
7. **Pitch** (flexion/extension)

**Algorithmic approach** (detailed in Section 6: Mathematical Framework)

**C. 3D Skeletal Visualization** (`src/ui/scene/`)

**Two rendering modes:**

1. **Vector Arm Mode** (`vectorArm.ts`):
   - Represents limbs as directional arrows
   - Useful for debugging quaternion orientation
   - Shows forward/up vectors for each segment

2. **Skeletal Rig Mode** (`skeletalRig.ts`):
   - Applies quaternions/angles to GLTF humanoid model
   - Realistic avatar for validation
   - Exports animation data (future: GLTF/FBX export)

<!-- **IMAGE PLACEHOLDER: Side-by-Side Rendering Modes**
*Description: Split image showing:*
- *Left: Vector arm mode (colored arrows showing humerus, radius, hand segments)*
- *Right: Skeletal rig mode (textured humanoid model with same pose)* -->

**D. Temporal Filtering**

To reduce high-frequency noise from IMU drift and vibration:

**Angle unwrapping** (prevents discontinuities at ±180°):
```typescript
function unwrapAngle(current: number, previous: number): number {
  const diff = current - previous;
  if (diff > 180) return current - 360;
  if (diff < -180) return current + 360;
  return current;
}
```

**Exponential moving average** (EMA smoothing):
```typescript
const ALPHA = 0.15;  // Smoothing factor (0=none, 1=no smoothing)
const filtered = previous + ALPHA * (current - previous);
```

**Configurable parameters:**
- `ALPHA`: Adjustable via UI slider (0.05 for slow motion, 0.3 for fast motion)
- Can disable smoothing for raw data export

### 5.4 Output Data Products

The eidon-sim pipeline generates multiple output formats:

**1. Joint Angle Time Series (CSV)**

```csv
timestamp_ms, shoulder_yaw_L, shoulder_pitch_L, shoulder_roll_L, elbow_flex_L, forearm_roll_L, wrist_yaw_L, wrist_pitch_L, [right arm angles...], chest_yaw, chest_pitch, chest_roll
0, 12.4, -23.1, 5.7, 87.3, -15.2, 8.9, -12.1, ...
21, 12.6, -23.5, 5.9, 88.1, -14.8, 9.2, -11.9, ...
...
```

**2. 3D Skeletal Positions (JSON)**

```json
{
  "timestamp_ms": 0,
  "left_arm": {
    "shoulder": [0.3, 1.4, 0.0],
    "elbow": [0.45, 1.15, 0.12],
    "wrist": [0.52, 0.91, 0.08],
    "fingertip": [0.58, 0.82, 0.05]
  },
  "right_arm": { ... },
  "chest": [0.0, 1.3, 0.0]
}
```

**3. Video with Overlay (MP4)**

Synchronized video with:
- On-screen joint angle readouts
- Skeleton overlay (optional)
- Timestamp and session metadata

**4. VLA Training Format**

**Proposed structure** (compatible with common VLA frameworks):

```json
{
  "task": "pick_and_place_cup",
  "episode_id": "ep_00123",
  "frames": [
    {
      "timestamp": 0.000,
      "observation": {
        "image": "frame_0000.jpg",
        "proprio": {
          "left_arm_7dof": [12.4, -23.1, 5.7, 87.3, -15.2, 8.9, -12.1],
          "right_arm_7dof": [...]
        }
      },
      "action": {
        "left_arm_delta": [0.1, 0.0, -0.2, 1.5, 0.0, 0.0, 0.0],
        "right_arm_delta": [...]
      }
    },
    ...
  ]
}
```

**Action labeling:**
- Manual annotation via UI timeline
- Future: GPT-4V automatic segmentation from video

---

## 6. Mathematical Framework

This section details the mathematical transformations that convert raw IMU quaternions into anatomically meaningful joint angles.

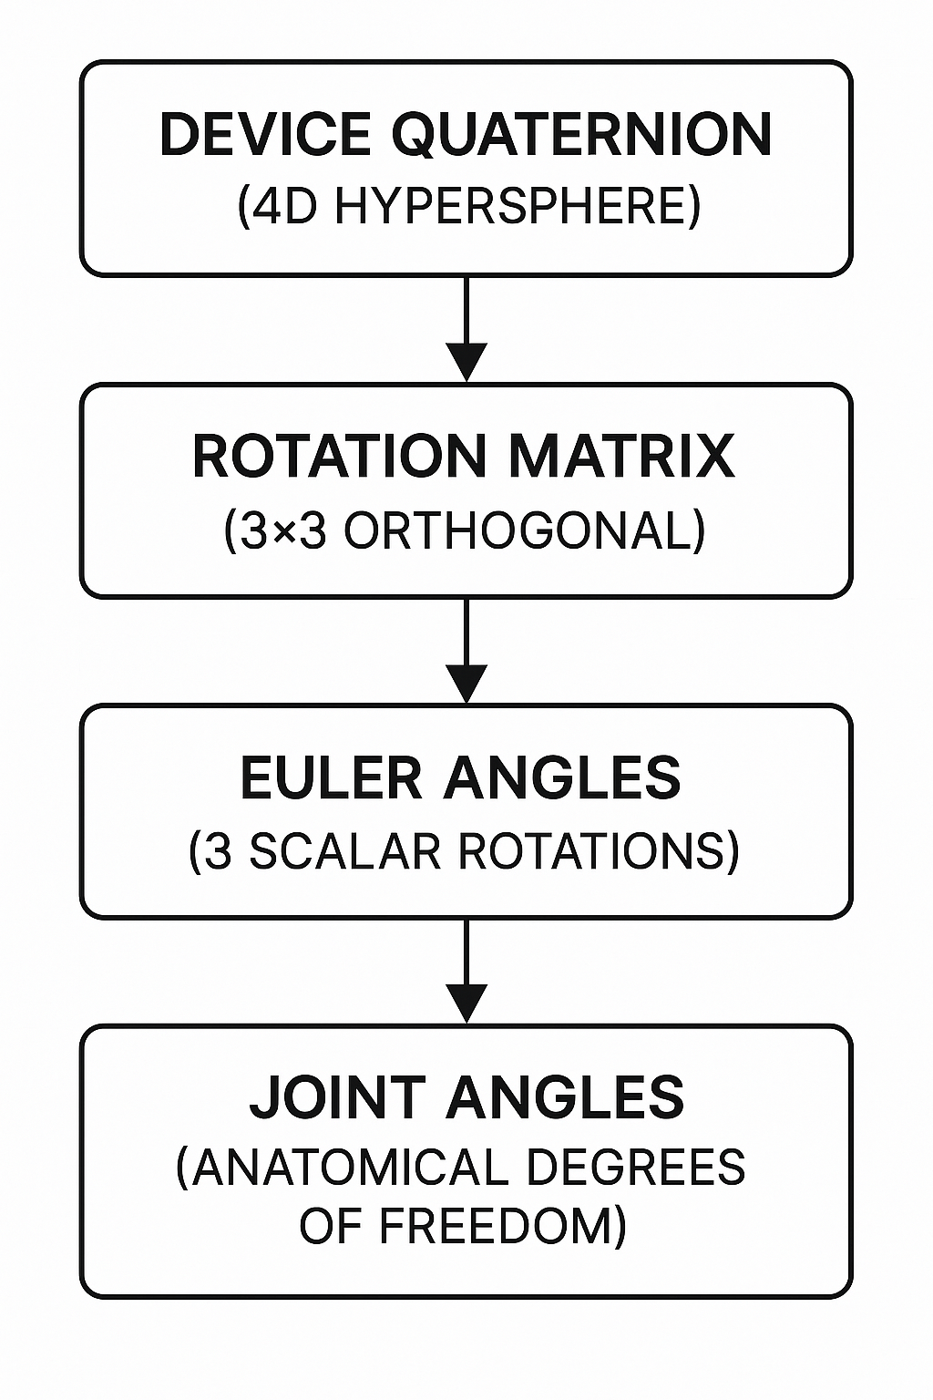
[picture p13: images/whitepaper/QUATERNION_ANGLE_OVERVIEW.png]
Quaternion to Angles Overview - Mathematical transformation pipeline


### 6.1 Quaternion Fundamentals

**Definition:**

A quaternion **q** is a 4-dimensional number representing 3D rotation:

```
q = w + xi + yj + zk
```

where `i² = j² = k² = ijk = -1`

**Vector form**: `q = [x, y, z, w]` (or `[qx, qy, qz, qw]`)

**Properties:**
- **Unit quaternion**: ‖q‖ = √(w² + x² + y² + z²) = 1
- **Identity rotation**: q = [0, 0, 0, 1] (no rotation)
- **Inverse**: q⁻¹ = [−x, −y, −z, w] / ‖q‖² (for unit quaternions: q⁻¹ = q*)
- **Composition**: Rotate by q₁ then q₂: q_combined = q₂ ⊗ q₁ (note: non-commutative)

**Quaternion multiplication** (Hamilton product):

```
q₁ ⊗ q₂ = [
  w₁w₂ − x₁x₂ − y₁y₂ − z₁z₂,
  w₁x₂ + x₁w₂ + y₁z₂ − z₁y₂,
  w₁y₂ − x₁z₂ + y₁w₂ + z₁x₂,
  w₁z₂ + x₁y₂ − y₁x₂ + z₁w₂
]
```

**Rotating a vector** v by quaternion q:

```
v' = q ⊗ [0, v] ⊗ q⁻¹
```

Implemented efficiently as:
```typescript
vec3.transformQuat(out, v, q)
```

### 6.2 Quaternion to Rotation Matrix

The quaternion `q = [x, y, z, w]` converts to a 3×3 rotation matrix:

```
     ⎡ 1−2(y²+z²)   2(xy−wz)     2(xz+wy)   ⎤
R =  ⎢ 2(xy+wz)     1−2(x²+z²)   2(yz−wx)   ⎥
     ⎣ 2(xz−wy)     2(yz+wx)     1−2(x²+y²) ⎦
```

**Code implementation** (`src/core/mathUtils.ts`):

```typescript
export function quatToMat3(q: quat): mat3 {
  const m = mat3.create();
  mat3.fromQuat(m, q);
  return m;
}
```

**Why convert to matrix?**
- Euler angle extraction requires matrix elements
- Some angle calculations (gimbal-lock analysis) easier in matrix form
- Compatibility with other graphics libraries

### 6.3 Euler Angle Extraction

Euler angles represent 3D rotation as three sequential rotations about fixed axes. The **order matters** due to non-commutativity.

<!-- **IMAGE PLACEHOLDER: Euler Angle Convention Diagram**
*Description: 3D coordinate system showing Z-Y-X rotation sequence:*
1. *First rotate α about Z-axis (yaw)*
2. *Then rotate β about new Y-axis (pitch)*
3. *Finally rotate γ about new X-axis (roll)*
*Show intermediate frames after each rotation* -->

#### A. Z-Y-X Euler Angles (Shoulder)

Used for shoulder joint angles (ISB biomechanics convention).

**Mathematical derivation:**

Given rotation matrix R from quaternion, extract angles:

```
R = Rz(α) · Ry(β) · Rx(γ)

     ⎡ cos(α)cos(β)   cos(α)sin(β)sin(γ)−sin(α)cos(γ)   cos(α)sin(β)cos(γ)+sin(α)sin(γ) ⎤
  =  ⎢ sin(α)cos(β)   sin(α)sin(β)sin(γ)+cos(α)cos(γ)   sin(α)sin(β)cos(γ)−cos(α)sin(γ) ⎥
     ⎣ −sin(β)        cos(β)sin(γ)                       cos(β)cos(γ)                     ⎦
```

**Solving for Euler angles:**

```
α (yaw)   = atan2(−R[1][0], R[0][0])
β (pitch) = asin(R[2][0])
γ (roll)  = atan2(−R[2][1], R[2][2])
```

**Code implementation** (`src/core/mathUtils.ts:9-23`):

```typescript
export function eulerZYX(q: quat): [number, number, number] {
  const m = mat3.fromQuat(mat3.create(), q);

  // Extract matrix elements (column-major indexing)
  const m00 = m[0], m10 = m[1], m20 = m[2];
  const m21 = m[5], m22 = m[8];

  const yaw   = Math.atan2(-m10, m00);   // Z rotation
  const pitch = Math.asin(m20);           // Y rotation
  const roll  = Math.atan2(-m21, m22);   // X rotation

  return [yaw, pitch, roll];  // Radians
}
```

**Singularity handling:**
When pitch ≈ ±90°, yaw and roll become coupled (gimbal lock). Solution:
- Clamp `asin` input to [-1, 1] to prevent NaN
- Accept reduced accuracy near singularity (rare in human arm motion)

#### B. X-Y-Z Euler Angles (Wrist)

Alternative convention for wrist joint (avoids gimbal lock in different configuration).

**Direct quaternion formula** (avoids matrix conversion):

```typescript
export function eulerXYZ(q: quat): [number, number, number] {
  const [x, y, z, w] = q;

  const yaw = Math.atan2(2.0 * (w * z + x * y),
                        1.0 - 2.0 * (y * y + z * z));

  const pitch = Math.asin(Math.max(-1, Math.min(1, 2.0 * (w * y - z * x))));

  const roll = Math.atan2(2.0 * (w * x + y * z),
                         1.0 - 2.0 * (x * x + y * y));

  return [yaw, roll, pitch];  // Note: pitch/roll swapped to match convention
}
```

### 6.4 Vector-Based Angle Calculations

For single-axis joints (elbow flexion), vector dot product is simpler and more robust than Euler angles.

#### Elbow Flexion Angle

<!-- **IMAGE PLACEHOLDER: Elbow Angle Diagram**
*Description: Side view of arm showing:*
- *Upper arm forward vector (blue arrow from shoulder)*
- *Forearm forward vector (red arrow from elbow)*
- *Angle θ between vectors*
- *Labels: 0° = straight, 180° = fully bent* -->

**Mathematical formula:**

Given unit vectors **u** (upper arm forward) and **l** (forearm forward):

```
θ = arccos(u · l)
```

where `u · l = ux·lx + uy·ly + uz·lz` (dot product)

**Code implementation** (`src/core/mathUtils.ts:74-79`):

```typescript
export function elbowFlexDeg(fwdUpper: vec3, fwdLower: vec3): number {
  const u = vec3.normalize(vec3.create(), fwdUpper);
  const l = vec3.normalize(vec3.create(), fwdLower);
  const cosAngle = vec3.dot(u, l);

  // Clamp to [-1, 1] to prevent numerical errors in acos
  const clampedCos = Math.max(-1, Math.min(1, cosAngle));

  return Math.acos(clampedCos) * 180 / Math.PI;
}
```

**Why this works:**
- Independent of shoulder orientation (only measures elbow bend)
- No gimbal lock (single axis)
- Output range: [0°, 180°] (0° = straight arm, 180° = maximally bent)

**Anatomical interpretation:**
- 0° = Full extension (arm straight)
- 90° = Right angle
- 145° = Typical maximum flexion

### 6.5 Forearm Roll (Pronation/Supination)

**Challenge:**
Measuring twist of forearm about its long axis while elbow bends.

**Naive approach fails:**
Simply comparing quaternions gives coupled elbow+roll motion.

**Robust solution:**
Project "up" vectors onto plane perpendicular to forearm forward direction.

<!-- **IMAGE PLACEHOLDER: Forearm Roll Geometry**
*Description: 3D diagram showing:*
- *Forearm cylinder with forward axis (green)*
- *Upper arm "up" vector (blue) and its projection (dashed blue) onto perpendicular plane*
- *Forearm "up" vector (red) and its projection (dashed red) onto same plane*
- *Angle θ between projections* -->

**Mathematical steps:**

1. **Extract up/forward vectors** from upper arm and forearm quaternions
2. **Project upper arm up vector** onto plane perpendicular to forearm forward:
   ```
   up_upper_proj = up_upper − (up_upper · fwd_forearm) · fwd_forearm
   ```
3. **Project forearm up vector** onto same plane:
   ```
   up_forearm_proj = up_forearm − (up_forearm · fwd_forearm) · fwd_forearm
   ```
4. **Calculate angle** between projections:
   ```
   θ = arccos(up_upper_proj · up_forearm_proj / (‖up_upper_proj‖ · ‖up_forearm_proj‖))
   ```
5. **Determine sign** using cross product:
   ```
   sign = (up_upper_proj × up_forearm_proj) · fwd_forearm ≥ 0 ? −1 : 1
   ```

**Code implementation** (`src/core/ArmSolver.ts:114-158`):

```typescript
// Get up vectors from quaternions
const upperUp = vec3.transformQuat(vec3.create(), [0, 0, 1], Q_UpperArm);
const lowerUp = vec3.transformQuat(vec3.create(), [0, 0, 1], Q_Forearm);
const lowerFwd = vec3.transformQuat(vec3.create(), [0, 1, 0], Q_Forearm);

// Project onto plane perpendicular to forearm forward
const upperDot = vec3.dot(upperUp, lowerFwd);
const lowerDot = vec3.dot(lowerUp, lowerFwd);

const upperUpProj = vec3.create();
const lowerUpProj = vec3.create();
vec3.scaleAndAdd(upperUpProj, upperUp, lowerFwd, -upperDot);
vec3.scaleAndAdd(lowerUpProj, lowerUp, lowerFwd, -lowerDot);

vec3.normalize(upperUpProj, upperUpProj);
vec3.normalize(lowerUpProj, lowerUpProj);

// Calculate angle
const cosAngle = vec3.dot(upperUpProj, lowerUpProj);
const angle = Math.acos(Math.max(-1, Math.min(1, cosAngle)));

// Determine sign
const cross = vec3.cross(vec3.create(), upperUpProj, lowerUpProj);
const sign = vec3.dot(cross, lowerFwd) >= 0 ? -1 : 1;

const forearmRollDeg = sign * angle * 180 / Math.PI;
```

**Anatomical interpretation:**
- **Negative angles**: Pronation (palm down)
- **Positive angles**: Supination (palm up)
- **Range**: Approximately −90° to +90°

### 6.6 Relative Quaternion Method (Wrist Angles)

Wrist angles should be measured **relative to forearm**, not absolute. This cancels accumulated drift from shoulder/elbow.

**Mathematical approach:**

Given forearm quaternion **q_forearm** and hand quaternion **q_hand**:

1. **Calculate relative rotation:**
   ```
   q_wrist = q_forearm⁻¹ ⊗ q_hand
   ```

2. **Extract Euler angles** from `q_wrist` using Z-Y-X convention

**Code implementation** (`src/core/ArmSolver.ts:162-184`):

```typescript
// Calculate relative quaternion: hand in forearm's reference frame
const Q_Wrist = quat.multiply(
  quat.create(),
  quat.invert(quat.create(), Q_Forearm),
  Q_Hand
);
quat.normalize(Q_Wrist, Q_Wrist);

// Extract wrist Euler angles
const [wristYaw, wristRoll, wristPitch] = eulerZYX(Q_Wrist);

// Convert radians to degrees
const wristYawDeg = wristYaw * 180 / Math.PI;
const wristPitchDeg = wristPitch * 180 / Math.PI;
```

**Why relative quaternions?**
- **Drift cancellation**: Any IMU drift common to forearm and hand cancels out
- **Anatomical correctness**: Wrist motion is inherently relative to forearm orientation
- **Gimbal lock avoidance**: Wrist rarely reaches singularity in forearm-relative frame

### 6.7 Complete Seven-Angle Solver

**Summary of derivation pipeline for one arm:**

```
Inputs: Q_UpperArm, Q_Forearm, Q_Hand (3 quaternions)

1. Shoulder angles (3-DOF):
   [yaw, pitch, roll] = eulerZYX(Q_UpperArm) * 180/π

2. Elbow flex (1-DOF):
   fwd_upper = rotate([0,1,0], Q_UpperArm)
   fwd_forearm = rotate([0,1,0], Q_Forearm)
   flex = elbowFlexDeg(fwd_upper, fwd_forearm)

3. Forearm roll (1-DOF):
   up_upper = rotate([0,0,1], Q_UpperArm)
   up_forearm = rotate([0,0,1], Q_Forearm)
   roll = forearmRollProjectionMethod(up_upper, up_forearm, fwd_forearm)

4. Wrist angles (2-DOF):
   Q_wrist = Q_Forearm⁻¹ ⊗ Q_Hand
   [yaw, pitch] = eulerZYX(Q_wrist)[0,2] * 180/π

Outputs: [sh_yaw, sh_pitch, sh_roll, el_flex, fr_roll, wr_yaw, wr_pitch]
```

<!-- **IMAGE PLACEHOLDER: 7-DOF Arm Diagram**
*Description: Annotated arm illustration showing all 7 angles with arrows:*
- *Shoulder: 3 curved arrows for yaw/pitch/roll*
- *Elbow: 1 curved arrow for flexion*
- *Forearm: 1 straight arrow for roll axis*
- *Wrist: 2 curved arrows for yaw/pitch* -->

### 6.8 Forward Kinematics (Vector Chaining)

Once joint angles are known, we can reconstruct 3D joint positions using **forward kinematics**.

**Chain structure:**

```
Shoulder (fixed) → [Upper Arm] → Elbow → [Forearm] → Wrist → [Hand] → Fingertips
```

**Position calculation:**

```
P_shoulder = [±0.3, 1.4, 0.0]  (left/right offset from chest)

P_elbow = P_shoulder + L_humerus · fwd_upper

P_wrist = P_elbow + L_radius · fwd_forearm

P_fingertips = P_wrist + L_hand · fwd_hand
```

**Segment lengths** (configurable via UI):
- `L_humerus` = 0.30m (default)
- `L_radius` = 0.26m (default)
- `L_hand` = 0.10m (default)

**Code implementation** (`src/ui/scene/vectorArm.ts:144-154`):

```typescript
const shoulder: vec3 = this.side === 'left' ? [-0.3, 1.4, 0] : [0.3, 1.4, 0];

const elbowPos = vec3.scaleAndAdd(
  vec3.create(),
  shoulder,
  upperArmForward,
  HUM_LEN()
);

const wristPos = vec3.scaleAndAdd(
  vec3.create(),
  elbowPos,
  forearmForward,
  RAD_LEN()
);

const fingertipPos = vec3.scaleAndAdd(
  vec3.create(),
  wristPos,
  handForward,
  HAND_LEN()
);
```

**Visualization:**
- Render cylinders/lines between joint positions
- Color-code segments (blue = upper arm, green = forearm, yellow = hand)

---

## 7. Integration Ecosystem

The Eidon Tracker is designed as an **open platform** for embodied AI research. This section describes integration points with external systems.

<!-- **IMAGE PLACEHOLDER: Integration Ecosystem Diagram**
*Description: Hub-and-spoke diagram showing Eidon system (center) connecting to:*
- *VLA training frameworks (OpenVLA, Octo, RT-1)*
- *Robotic platforms (unitree, figure, 1x)*
- *Simulation environments (Isaac Sim, MuJoCo)*
- *Data annotation tools (CVAT, Label Studio)*
- *Cloud storage (S3, GCS)* -->

### 7.1 VLA Training Pipeline Integration

**Common VLA frameworks:**
- **OpenVLA**: Open-source vision-language-action model
- **Octo**: General-purpose robot policy trained on diverse datasets
- **RT-1/RT-2**: Google's Robotics Transformer models
- **Diffusion Policy**: Behavior cloning via diffusion models

**Integration approach:**

1. **Dataset format compatibility**
   - Convert Eidon output to framework-specific format (e.g., RLDS for RT-1)
   - Maintain original data as well for maximum flexibility

2. **Action space mapping**
   - 7-DOF arm angles → robot joint targets
   - Requires robot-specific kinematic mapping

3. **Temporal alignment**
   - Synchronize IMU data (48Hz) with video frames (30-60fps)
   - Interpolate or subsample to common rate (typically 30Hz)

**Example: OpenVLA integration pseudocode**

```python
from eidon import EidonDataset
from openvla import VLATrainer

# Load Eidon dataset
dataset = EidonDataset("path/to/collected_data/")

# Convert to OpenVLA format
vla_episodes = []
for episode in dataset:
    frames = []
    for t in episode.timestamps:
        frame = {
            "observation": {
                "image": episode.get_video_frame(t),
                "proprio": episode.get_joint_angles(t),  # 7-DOF per arm
            },
            "action": compute_action_label(episode, t),  # Delta angles
            "timestamp": t,
        }
        frames.append(frame)
    vla_episodes.append({"task": episode.task_label, "frames": frames})

# Train VLA model
trainer = VLATrainer(config)
trainer.train(vla_episodes)
```

### 7.2 Robotic Platform Retargeting

**Challenge:**
Human arm kinematics ≠ robot arm kinematics

**Solutions:**

**A. Direct Joint Mapping (for humanoid robots)**

If robot has similar kinematic structure (7-DOF arms):

```python
# Map human angles directly to robot joints
robot_left_arm = [
    human_left_arm.sh_yaw,
    human_left_arm.sh_pitch,
    human_left_arm.sh_roll,
    human_left_arm.el_flex,
    human_left_arm.fr_roll,
    human_left_arm.wr_yaw,
    human_left_arm.wr_pitch,
]
robot.set_joint_targets(robot_left_arm)
```

**Limitations:**
- Requires joint limit adjustments (humans have different ROM than robots)
- May need scaling factors for elbow/wrist ranges

**B. Cartesian Task Space Mapping**

For robots with different DOF (e.g., 6-DOF industrial arms):

```python
# Use forward kinematics to get end-effector position
wrist_position_3d = eidon.get_wrist_position(episode, t)
wrist_orientation_quat = eidon.get_hand_quaternion(episode, t)

# Solve inverse kinematics for robot
robot_joint_angles = robot.ik_solver(
    target_pos=wrist_position_3d,
    target_ori=wrist_orientation_quat,
)
robot.set_joint_targets(robot_joint_angles)
```

**C. Reinforcement Learning Refinement**

Use human demonstrations as **initialization** for RL policy:

1. Train imitation learning policy on Eidon data
2. Fine-tune in simulation with RL reward signal
3. Deploy to physical robot with sim-to-real transfer

### 7.3 Simulation Environment Integration

**Use cases:**
- Validate data quality before deploying to physical robot
- Generate synthetic training data with domain randomization
- Test policy generalization

**Supported simulators:**
- **NVIDIA Isaac Sim**: High-fidelity physics + rendering
- **MuJoCo**: Fast physics for RL training
- **PyBullet**: Open-source, widely used in research

**Example: Isaac Sim replay**

```python
from omni.isaac.kit import SimulationApp
from eidon import EidonDataset

# Load dataset
dataset = EidonDataset("data/task_demonstrations/")

# Spawn humanoid asset in Isaac Sim
humanoid = spawn_humanoid("eidon_humanoid.usd")

# Replay motion
for t in dataset.episode(0).timestamps:
    angles = dataset.get_joint_angles(t)
    humanoid.set_joint_targets(angles)
    step_simulation()
```

**Benefits:**
- **Visual validation**: Ensure captured motion looks anatomically correct
- **Physics checking**: Detect impossible movements (e.g., arm passing through torso)
- **Data augmentation**: Add camera viewpoint variations, lighting changes

### 7.4 Real-Time Teleoperation

<!-- **IMAGE PLACEHOLDER: Teleoperation System Diagram**
*Description: Human wearing Eidon trackers on left, robot arm on right, with wireless communication arrows showing:*
- *Eidon → Mobile App (BLE)*
- *Mobile App → Robot Controller (WiFi)*
- *Robot Controller → Arm Motors (CAN/Ethernet)* -->

**Architecture:**

```
Human + Eidon Trackers → Mobile App → WebSocket Server → Robot Controller → Actuators
                         (BLE)        (WiFi/LTE)          (ROS2/MQTT)
```

**Latency breakdown:**
- IMU → BLE: <20ms
- BLE → Mobile App: ~10-30ms
- Mobile App → Server: 20-100ms (network dependent)
- Server → Robot: 10-50ms
- **Total**: 60-200ms end-to-end

**Optimization strategies:**
1. **Predictive filtering**: Extrapolate motion to compensate latency
2. **Direct robot connection**: Skip cloud server (mobile app → robot WiFi direct)
3. **Differential control**: Send velocity commands instead of position targets

**Safety considerations:**
- **Deadman switch**: Stop robot if BLE connection lost
- **Joint limit enforcement**: Clamp commanded angles to safe ranges
- **Emergency stop**: Physical button on robot + app UI

### 7.5 Data Annotation & Labeling

Collected datasets require task-level annotations for VLA training.

**Annotation workflow:**

1. **Video review**: Watch egocentric video of task
2. **Segment identification**: Mark start/end of task phases (e.g., "reach for cup", "grasp", "lift")
3. **Action labeling**: Assign semantic labels to segments
4. **Quality control**: Flag corrupted data (e.g., lost tracker connection)

**Recommended tools:**
- **CVAT (Computer Vision Annotation Tool)**: Video annotation with timeline
- **Label Studio**: Multi-modal annotation (video + time series data)
- **Custom Eidon annotation UI**: Integrated with eidon-sim visualization

<!-- **IMAGE PLACEHOLDER: Annotation UI Mockup**
*Description: Screenshot showing:*
- *Top: Video playback with skeleton overlay*
- *Middle: Timeline with segment blocks (color-coded by task phase)*
- *Bottom: Joint angle graphs with annotation markers*
- *Right sidebar: Label selection dropdown and notes field* -->

### 7.6 API Specification

**For developers integrating Eidon data:**

**Dataset loader (Python)**

```python
from eidon import EidonDataset

# Load dataset from directory
dataset = EidonDataset("path/to/dataset/")

# Iterate over episodes
for episode in dataset:
    print(f"Task: {episode.task_label}")
    print(f"Duration: {episode.duration_seconds}s")
    print(f"Number of frames: {len(episode)}")

    # Access frame data
    for frame in episode:
        # Get synchronized data at timestamp t
        img = frame.image  # numpy array (H, W, 3)
        angles = frame.joint_angles  # dict: {"left_arm": [7 floats], "right_arm": [7 floats]}
        quat = frame.quaternions  # dict: {"chest": [4 floats], "left_hand": [4 floats], ...}
        positions = frame.joint_positions_3d  # dict: {"left_elbow": [x,y,z], ...}
```

**BLE connection (TypeScript/JavaScript)**

```typescript
import { EidonBLEDevice } from '@eidon/ble-sdk';

// Scan for devices
const devices = await EidonBLEDevice.scan();

// Connect to specific device
const tracker = await EidonBLEDevice.connect(devices[0]);

// Subscribe to quaternion stream
tracker.onQuaternion((quat) => {
  console.log(`Quaternion: w=${quat.w}, x=${quat.x}, y=${quat.y}, z=${quat.z}`);
});

// Trigger calibration
await tracker.calibrate();

// Read battery level
const battery = await tracker.getBatteryPercent();
console.log(`Battery: ${battery}%`);
```

---

## 8. Applications & Use Cases

The Eidon Tracker platform enables a wide range of applications beyond VLA training.

### 8.1 Embodied AI Training Data Collection

**Primary use case**: Create large-scale datasets of human task demonstrations for robot learning.

**Target tasks:**
- **Kitchen manipulation**: Cooking, dishwashing, food preparation
- **Manufacturing assembly**: Component insertion, tool use, quality inspection
- **Healthcare**: Patient transfer, medication administration, assistive tasks
- **Domestic chores**: Laundry folding, cleaning, organization
- **Agriculture**: Harvesting, pruning, sorting

**Advantages over lab teleoperation:**
- **Diverse environments**: Collect data in real kitchens, factories, hospitals
- **Natural variability**: Multiple demonstrators with different techniques
- **Scale**: Deploy 100+ trackers to different sites simultaneously
- **Cost**: ~$200/system vs. $10k+ for lab motion capture

**Dataset metrics** (projected):
- **1 hour of recording** = ~172,800 samples (48Hz × 3600s)
- **100 demonstrators** × 8 hours = 138M samples
- **Approaching LLM-scale data**: Billions of samples across diverse tasks

### 8.2 Teleoperation for Remote Robotics

**Scenario**: Control humanoid robot from remote location

**Use cases:**
- **Hazardous environments**: Nuclear decommissioning, disaster response
- **Space exploration**: Mars rovers with human-like manipulators
- **Underwater operations**: Subsea maintenance with ROVs
- **Telemedicine**: Remote surgery or physical therapy

<!-- **IMAGE PLACEHOLDER: Teleoperation Scenario**
*Description: Split image showing:*
- *Left: Operator wearing Eidon trackers + VR headset in control room*
- *Right: Humanoid robot in hazardous environment (e.g., nuclear plant) mimicking operator's movements* -->

### 8.3 Biomechanics Research

**Applications:**
- **Ergonomic analysis**: Assess workplace strain and injury risk
- **Sports biomechanics**: Golf swing, baseball pitch analysis
- **Clinical gait analysis**: Movement disorders (Parkinson's, stroke)
- **Prosthetics research**: Evaluate artificial limb performance

**Advantages:**
- **Field-deployable**: Measure real work environments, not just lab
- **Long-duration monitoring**: 8+ hour battery life
- **Quantitative**: ±1-2° accuracy comparable to research-grade systems
- **Cost**: ~$200 vs. $50k+ for Vicon/OptiTrack systems

### 8.4 Animation & Virtual Production

**Use cases:**
- **Real-time mocap for VR/AR**: Avatar control in metaverse applications
- **Video game animation**: Capture combat moves, dance sequences
- **Film pre-visualization**: Block scenes with digital actors

**Integration with animation tools:**
- Export joint angles or GLTF animation tracks
- Compatible with Blender, Maya, Unreal Engine

### 8.5 Physical Therapy & Rehabilitation

**Applications:**
- **ROM (range of motion) tracking**: Measure progress during PT
- **Home exercise monitoring**: Ensure correct form during unsupervised exercises
- **Compliance tracking**: Verify patient performed prescribed exercises

**Clinical workflow:**
1. Patient performs exercise wearing trackers
2. System records joint angles throughout session
3. Automated analysis flags improper form or reduced ROM
4. Report sent to physical therapist for review

<!-- **IMAGE PLACEHOLDER: PT Use Case**
*Description: Patient performing shoulder abduction exercise with tracker on upper arm, mobile app showing real-time angle readout and target zone visualization* -->

---

## 9. Technical Specifications

### 9.1 Hardware Specifications

#### Eidon Tracker Device

| Specification | Value |
|---|---|
| **Dimensions** | 45mm × 30mm × 15mm |
| **Weight** | 25g (with battery) |
| **Enclosure material** | 3D-printed PLA/ABS (injection-mold-ready) |
| **Water resistance** | IP42 (splash-resistant) |
| **Operating temperature** | -20°C to +70°C |

#### Microcontroller (ESP32-C6)

| Specification | Value |
|---|---|
| **CPU** | RISC-V single-core @ 160MHz |
| **RAM** | 512KB SRAM |
| **Flash** | 4MB |
| **Wireless** | BLE 5.0, WiFi 6 (802.11ax), ESP-NOW |
| **GPIO** | 22 programmable pins |
| **ADC** | 12-bit, 6 channels |
| **Power consumption** | ~15mA active, <10µA deep sleep |

#### IMU (BNO085)

| Specification | Value |
|---|---|
| **Sensor type** | 9-DOF (gyro + accel + mag) |
| **Gyroscope range** | ±2000°/s |
| **Accelerometer range** | ±16g |
| **Magnetometer range** | ±2500µT |
| **Output rate** | 48Hz (quaternion) |
| **Accuracy** | ±2° RMS dynamic, ±1° RMS static |
| **Calibration** | Automatic sensor fusion |
| **Interface** | I2C (400kHz) |

#### Power System

| Specification | Value |
|---|---|
| **Battery type** | LiPo (Lithium Polymer) |
| **Capacity** | 150-300mAh (depending on size) |
| **Voltage** | 3.7V nominal (3.0-4.2V range) |
| **Battery life** | 8-12 hours continuous operation |
| **Charging** | USB-C (5V, 500mA) |
| **Battery monitoring** | 12-bit ADC via voltage divider |

#### Communication

| Specification | Value |
|---|---|
| **BLE range** | 10-20m indoors, 50m+ line-of-sight |
| **ESP-NOW range** | 20-50m typical |
| **BLE data rate** | 24Hz quaternion notifications |
| **ESP-NOW data rate** | 48Hz (child → hub) |
| **Latency** | <50ms end-to-end (IMU → mobile app) |
| **Packet loss** | <0.1% (BLE in good conditions) |

### 9.2 Firmware Specifications

| Specification | Value |
|---|---|
| **Framework** | Arduino (C/C++) |
| **Build system** | PlatformIO |
| **Firmware version** | 1.2 (current) |
| **OTA updates** | Planned (future feature) |
| **Flash usage** | ~452KB / 4MB (11%) |
| **RAM usage** | ~80KB / 512KB (16%) |
| **CPU utilization** | ~40% average |

### 9.3 Data Format Specifications

#### Quaternion Data

| Field | Type | Size | Range |
|---|---|---|---|
| qw | float32 | 4 bytes | [-1.0, 1.0] |
| qx | float32 | 4 bytes | [-1.0, 1.0] |
| qy | float32 | 4 bytes | [-1.0, 1.0] |
| qz | float32 | 4 bytes | [-1.0, 1.0] |
| **Total** | | **16 bytes** | Unit quaternion (‖q‖=1) |

#### Joint Angles (per arm)

| Angle | Range | Units |
|---|---|---|
| Shoulder yaw | -90° to +90° | degrees |
| Shoulder pitch | -180° to +60° | degrees |
| Shoulder roll | -45° to +180° | degrees |
| Elbow flex | 0° to 145° | degrees |
| Forearm roll | -90° to +90° | degrees |
| Wrist yaw | -30° to +30° | degrees |
| Wrist pitch | -70° to +70° | degrees |

### 9.4 System Requirements

#### Mobile Application

| Platform | Requirements |
|---|---|
| **iOS** | iOS 14+ (BLE 5.0 support) |
| **Android** | Android 10+ (API level 29+) |
| **RAM** | 4GB+ recommended |
| **Storage** | 500MB+ free (for app + temporary data) |
| **Camera** | 1080p @ 30fps minimum |

#### eidon-sim Processing

| Platform | Requirements |
|---|---|
| **OS** | Windows 10+, macOS 12+, Linux (Ubuntu 20.04+) |
| **Browser** | Chrome 90+, Edge 90+, Firefox 88+ (WebGL 2.0 support) |
| **RAM** | 8GB+ |
| **GPU** | Integrated graphics sufficient (dedicated GPU for faster rendering) |

### 9.5 Manufacturing Specifications

#### PCB

| Specification | Value |
|---|---|
| **Size** | 25mm × 20mm |
| **Layers** | 2 (top + bottom) |
| **Thickness** | 1.6mm |
| **Material** | FR4 |
| **Copper weight** | 1 oz (35µm) |
| **Finish** | ENIG (Electroless Nickel Immersion Gold) |
| **Min trace/space** | 0.15mm / 0.15mm |
| **Min drill** | 0.3mm |
| **Assembly** | SMT (surface mount) + hand soldering (modules) |

#### 3D Printed Enclosure

| Specification | Value |
|---|---|
| **Print technology** | FDM (Fused Deposition Modeling) |
| **Layer height** | 0.2mm |
| **Infill** | 20% gyroid |
| **Material** | PLA or ABS |
| **Print time** | ~60 min (body), ~20 min (lid) |
| **Post-processing** | Light sanding on mating surfaces |
| **Cost per unit** | ~$1.50 (material + amortized printer cost) |

---

## 10. Conclusion

The Eidon Tracker system represents a **paradigm shift** in embodied AI training data collection. By combining custom hardware, sophisticated firmware, and advanced kinematics processing, we enable researchers to collect human demonstration data at a scale previously unattainable.

### Key Innovations

1. **Complete vertical integration**: Custom PCB → firmware → enclosure → data pipeline
2. **Field-deployable design**: Wearable, battery-powered, robust construction
3. **Dual-radio architecture**: Efficient BLE + ESP-NOW for multi-device coordination
4. **Seven-degree-of-freedom kinematics**: Anatomically accurate joint angle derivation
5. **Open platform**: Integration-ready for VLA frameworks and robotic systems

### The Path Forward

**Immediate applications:**
- VLA training dataset collection for kitchen manipulation tasks
- Teleoperation interface for humanoid robots (unitree H1, Figure 01)
- Biomechanics research (ergonomics, sports science)

**Future development roadmap:**
- **Expanded tracking**: Lower body tracking (hips, knees, ankles) for full-body capture
- **Sensor fusion**: Integrate camera-based tracking for absolute position (indoor SLAM)
- **Cloud platform**: Centralized dataset repository with annotation tools
- **Pre-trained models**: Release VLA models trained on Eidon datasets
- **Enterprise SDK**: Commercial licensing for robotics companies

### Closing Statement

The "LLM moment" for humanoid robotics requires data infrastructure that **democratizes** embodied AI research. Eidon Tracker provides that infrastructure—enabling researchers, startups, and enterprises to collect human demonstration data at scale, anywhere tasks are performed.

**We're not just building motion capture hardware. We're building the foundation for a new generation of embodied intelligence.**

---

## Appendix A: Bill of Materials (Detailed)

### Per-Device BOM (Current Production Costs)

| Component | Part/Model | Manufacturer | Qty | Unit Price | Ext. Price | Notes |
|---|---|---|-----|---|---|---|
| Microcontroller | XIAO ESP32-C6 | Seeed Studio | 1 | $5.20 | $5.20 | BLE 5.0 + WiFi 6 |
| IMU Sensor | BNO085 | Adafruit (Bosch) | 1 | $17.51 | $17.51 | Pre-calibrated 9-DOF |
| LiPo Battery | 200-300mAh 3.7V | Generic | 1 | $4.59 | $4.59 | JST connector, protection circuit |
| Power Switch | SPDT slide switch | Generic | 1 | $0.08 | $0.08 | PCB mount |
| 3D Printed Parts | Body + lid + button | PLA filament | 1 set | $0.46 | $0.46 | ~15g material per device |
| Elastic Strap | 20mm Velcro elastic | Generic | 1 | $3.00 | $3.00 | ~300mm length |
| USB Cable | USB-C charge cable | Generic | 1 | $1.13 | $1.13 | 1m length |
| | | | | **Total** | **$30.84** | **Per device** |

**Note:** Current costs are based on small-batch production (10-20 units). PCB fabrication and passive components (resistors, LEDs) are included in the XIAO module cost.

### Complete 7-Device System BOM

| Item | Qty | Unit Price | Ext. Price | Notes |
|---|-----|---|---|---|
| Eidon Tracker devices | 7 | $30.84 | $215.88 | 2× hand, 2× forearm, 2× upper arm, 1× chest |
| Velcro elastic straps | 6 | $3.00 | $18.00 | Included in tracker cost above |
| Chest harness | 1 | $24.00 | $24.00 | Adjustable chest mount system |
| USB charging hub | 1 | $35.99 | $35.99 | 7+ port USB hub for simultaneous charging |
| USB cables | 7 | $1.13 | $7.91 | Included in tracker cost above |
| | | | **$278.87** | **Total system cost** |

**Effective cost breakdown:**
- **Trackers only:** $215.88 (7 devices)
- **Accessories:** $62.99 (harness + hub)
- **Total ready-to-use kit:** $278.87

### Volume Pricing Estimates

**100-unit production (700 trackers):**
- IMU: $15.00 ea (10% bulk discount)
- ESP32-C6: $4.50 ea
- Battery: $3.50 ea
- 3D printing: $0.30 ea (batch production)
- **Estimated cost:** ~$24/device ($168 for 7-device system)

**1000-unit production (7000 trackers):**
- IMU: $12.00 ea (30% bulk discount)
- ESP32-C6: $4.00 ea
- Battery: $2.50 ea
- Enclosure: $0.50 ea (injection molding tooling amortized)
- **Estimated cost:** ~$18/device ($126 for 7-device system)

---

## Appendix B: File Locations Reference

### eidon-tracker Repository

```
/Users/robert/eidon/eidon-tracker/
├── firmware/
│   ├── src/main.cpp (core firmware logic)
│   ├── lib/BNO085/ (IMU driver)
│   └── platformio.ini (build config)
├── pcb/eidon-tracker/
│   ├── eidon-tracker.kicad_sch (schematic)
│   ├── eidon-tracker.kicad_pcb (layout)
│   └── gerbers/*.zip (manufacturing files)
├── cad/
│   ├── eidon-tracker-v3b.f3d (Fusion 360 source)
│   ├── eidon-tracker.step (universal CAD)
│   └── *.stl (3D print files)
├── web/
│   ├── index.html (visualizer UI)
│   └── script.js (BLE + Three.js logic)
└── docs/
    ├── FIRMWARE_ARCHITECTURE.md
    ├── GATT_SERVICE_REFERENCE.md
    └── HARDWARE_OVERVIEW.md
```

### eidon-sim Repository

```
/Users/robert/eidon/eidon-sim/
├── src/
│   ├── core/
│   │   ├── reportParsers.ts (quaternion decoding)
│   │   ├── mathUtils.ts (Euler, vector math)
│   │   └── ArmSolver.ts (7-DOF angle solver)
│   └── ui/scene/
│       ├── vectorArm.ts (forward kinematics visualization)
│       └── skeletalRig.ts (GLTF model animation)
└── docs/
    └── kinematics.md (mathematical documentation)
```

---

## Appendix C: UUID Reference

### BLE Service UUIDs

| Service/Characteristic | UUID | Type | Description |
|---|---|---|---|
| **Primary Service** | `E1D00001-8B5A-3E5B-9E23-4F9B5C91BBDE` | Service | Main Eidon Tracker service |
| Quaternion | `E1D00002-8B5A-3E5B-9E23-4F9B5C91BBDE` | Char (RN) | Quaternion data (w,x,y,z) |
| Calibration | `E1D00003-8B5A-3E5B-9E23-4F9B5C91BBDE` | Char (RW) | Calibration command (0x01) |
| Device Info | `E1D00005-8B5A-3E5B-9E23-4F9B5C91BBDE` | Char (R) | Device ID, FW ver, battery, role |
| Hand Quaternion | `E1D00008-8B5A-3E5B-9E23-4F9B5C91BBDE` | Char (RN) | Aggregated hand quat (hub only) |
| Forearm Quaternion | `E1D00009-8B5A-3E5B-9E23-4F9B5C91BBDE` | Char (RN) | Aggregated forearm quat (hub only) |
| **Role Config Service** | `E1D00006-8B5A-3E5B-9E23-4F9B5C91BBDE` | Service | Role assignment service |
| Role Assignment | `E1D00007-8B5A-3E5B-9E23-4F9B5C91BBDE` | Char (RW) | Device role + hub MAC address |

**Legend:**
- R = Read
- W = Write
- N = Notify
- RN = Read + Notify
- RW = Read + Write

---

## Appendix D: Glossary

**BLE (Bluetooth Low Energy)**: Wireless protocol optimized for low-power device communication. Used for Eidon Tracker → mobile app data streaming.

**BNO085**: Bosch 9-DOF IMU with hardware sensor fusion. Outputs quaternions at 48Hz.

**DOF (Degrees of Freedom)**: Number of independent parameters defining a joint's movement. Shoulder = 3-DOF, elbow = 1-DOF, wrist = 2-DOF.

**Embodied AI**: AI systems that interact with the physical world through robotic bodies.

**ESP-NOW**: Espressif's proprietary low-latency wireless protocol. Used for child device → hub communication.

**Euler Angles**: Representation of 3D rotation as three sequential axis rotations (e.g., yaw-pitch-roll).

**GATT (Generic Attribute Profile)**: BLE protocol layer defining service/characteristic structure.

**Gimbal Lock**: Singularity in Euler angle representation where two axes align, losing a degree of freedom.

**IMU (Inertial Measurement Unit)**: Sensor combining gyroscope, accelerometer, and magnetometer. Measures orientation and acceleration.

**NimBLE**: Lightweight Bluetooth stack for ESP32 (alternative to Bluedroid).

**Pronation/Supination**: Forearm rotation (pronation = palm down, supination = palm up).

**Quaternion**: 4D number (w, x, y, z) representing 3D rotation. Avoids gimbal lock, efficient for interpolation.

**RISC-V**: Open-source instruction set architecture. Used in ESP32-C6 microcontroller.

**ROM (Range of Motion)**: Maximum angular extent a joint can move.

**Sensor Fusion**: Combining data from multiple sensors (gyro, accel, mag) to compute accurate orientation.

**VLA (Vision-Language-Action)**: Multimodal AI model mapping visual observations + language instructions → robot actions.

---

## Appendix E: Contact & Licensing

**Company**: Eidon
**Website**: [www.eidon.ai](https://www.eidon.ai)
**Technical Support**: robert@eidon.ai
**GitHub**: [github.com/eidon/eidon-tracker](https://github.com/eidon/eidon-tracker)

**Licensing:**
- Hardware designs (PCB, enclosure): **Open-source** (CERN-OHL-P v2 or similar)
- Firmware: **Open-source** (MIT License or similar)
- Software (eidon-sim): **Open-source** (MIT License)
- Documentation: **Creative Commons CC-BY-4.0**

**Commercial licensing available for:**
- White-label OEM integration
- Custom firmware development
- Enterprise support contracts

---

## Appendix F: Hardware Schematics

### KiCad Schematic Diagram

Complete electrical schematic showing circuit design, component interconnections, and signal routing.

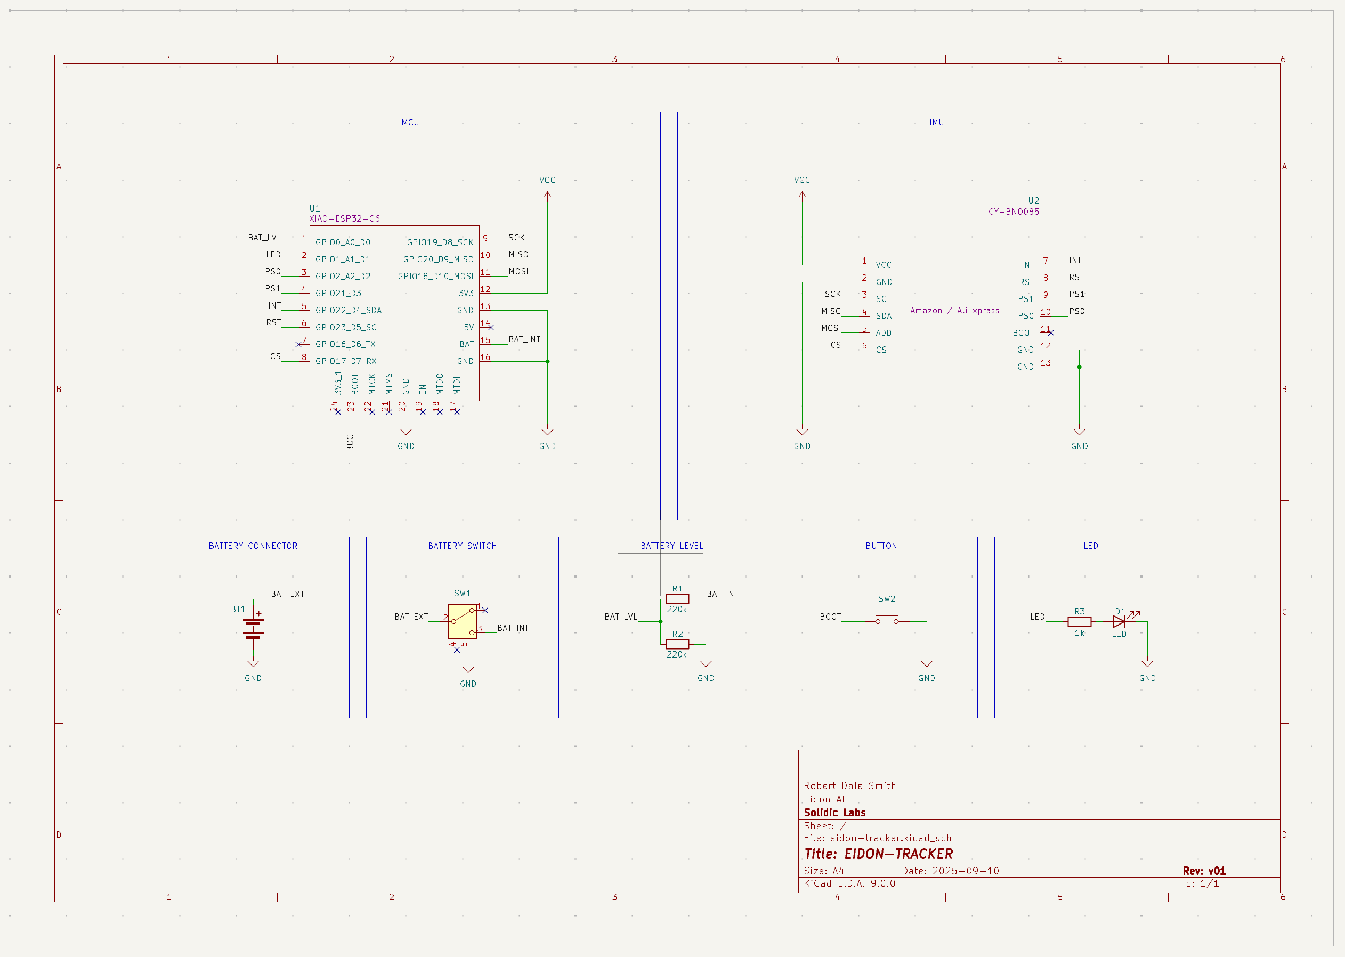
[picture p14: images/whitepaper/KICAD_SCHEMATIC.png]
KiCad Schematic - Complete electrical circuit design


**Key functional blocks:**
- **Power Management**: LiPo battery input, voltage monitoring circuit (220kΩ voltage divider)
- **Microcontroller**: Seeed XIAO ESP32-C6 with pin assignments for I2C, GPIO, ADC
- **IMU Interface**: BNO085 I2C connection (400kHz), interrupt pin, address configuration
- **Status Indicators**: LED with current-limiting resistor, user button interface

For full resolution schematic and PCB layout files, see: `pcb/eidon-tracker/eidon-tracker.kicad_sch`

---

**Document prepared by**: Eidon Engineering Team
**Last updated**: November 2025
**Document version**: 1.0

---

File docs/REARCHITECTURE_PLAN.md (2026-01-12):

# Hub/Child Communication Rearchitecture Plan

## Overview

This document outlines the rearchitecture of the hub/child communication system. The key change is moving from side-based hubs (left/right shoulders) to right-side hubs that receive data from left-side children.

### Architecture Summary

**Current Architecture:**
- Hubs: `ROLE_LEFT_HUB`, `ROLE_RIGHT_HUB`, `ROLE_CHEST`
- Children: `ROLE_LEFT_HAND`, `ROLE_RIGHT_HAND`, `ROLE_LEFT_FOREARM`, `ROLE_RIGHT_FOREARM`
- Children send to their side's hub (left→left, right→right)

**New Architecture:**
- Hubs: `ROLE_RIGHT_HAND`, `ROLE_RIGHT_FOREARM`, `ROLE_RIGHT_SHOULDER`, `ROLE_CHEST`
- Children: `ROLE_LEFT_HAND`, `ROLE_LEFT_FOREARM`, `ROLE_LEFT_SHOULDER`
- Left children send to corresponding right hubs (left→right)
- Right hubs aggregate their own data + left child data
- Chest sends directly to phone (no children)

---

## Stage 1: Role System Changes

### Objectives
- Rename `ROLE_LEFT_HUB` → `ROLE_LEFT_SHOULDER`
- Rename `ROLE_RIGHT_HUB` → `ROLE_RIGHT_SHOULDER`
- Update role detection methods (`isHubMode()`, `isNodeMode()`)
- Update role name strings

### Files to Modify
1. `firmware/src/DeviceConfig.h` - Role enum definitions
2. `firmware/src/DeviceConfig.cpp` - Role logic implementation

### Changes Required
- Update `DeviceRole` enum with new role names
- Update `getRoleName()` to return new role names
- Update `isHubMode()` to return true for: `ROLE_RIGHT_HAND`, `ROLE_RIGHT_FOREARM`, `ROLE_RIGHT_SHOULDER`, `ROLE_CHEST`
- Update `isNodeMode()` to return true for: `ROLE_LEFT_HAND`, `ROLE_LEFT_FOREARM`, `ROLE_LEFT_SHOULDER`
- Update `isValidRole()` to include new role values

### Status
- [x] ✅ Completed

---

## Stage 2: ESP-NOW Communication Changes
**Status:** ✅ Completed

### Objectives
- Update child devices to send ESP-NOW data to right-side hubs
- Update hub devices to receive data from left-side children
- Support three child types: hand, forearm, shoulder

### Files Modified
1. `firmware/src/Role_Services/HubClient_Service.h` - Service interface updates
2. `firmware/src/Role_Services/HubClient_Service.cpp` - Hub ESP-NOW receiver logic
3. `firmware/src/main.cpp` - Child count updates

### Changes Completed
- [x] Updated `MAX_CHILDREN` from 2 to 1 (each hub has exactly one child: right hand <- left hand, right forearm <- left forearm, right shoulder <- left shoulder)
- [x] Added `shoulderMissedPolls` tracking for shoulder disconnection detection
- [x] Updated `processQuaternionPacket()` to handle `ROLE_LEFT_SHOULDER`
- [x] Updated `checkChildDisconnections()` to track shoulder disconnections
- [x] Updated `syncConnectionStatus()` to handle shoulder role (data structure update pending in Stage 6)
- [x] Added validation to ensure hubs only accept data from left children (hand, forearm, shoulder)
- [x] Updated hardcoded child count in `main.cpp` to use `MAX_CHILDREN`
- [x] Updated periodic logging to use `MAX_CHILDREN` instead of hardcoded value
- [x] Child ESP-NOW sender logic already supports all left children (verified from Stage 1)

### Notes
- Child ESP-NOW sending was already working from Stage 1 (role checks include `ROLE_LEFT_SHOULDER`)
- Each hub has exactly one child: right hand hub receives from left hand, right forearm hub receives from left forearm, right shoulder hub receives from left shoulder
- Shoulder data aggregation structure will be added in Stage 6 when we update `AggregatedQuaternionData`
- Validation ensures hubs only process packets from left children for security
- Disconnection tracking uses separate counters for each child type, but each hub only uses one counter (the one matching its child type)

### Next Steps
- Proceed to Stage 3: BLE Characteristic Updates

---

## Stage 3: BLE Characteristic Updates
**Status:** ✅ Completed

### Objectives
- Add shoulder quaternion and raw data characteristics
- Update UUID selection logic for right hubs
- Ensure right hubs expose characteristics for hub data + left children data
- Ensure chest only sends its own data

### Files Modified
1. `firmware/src/main.cpp` - Characteristic setup and data transmission

### Changes Completed
- [x] Added shoulder quaternion and raw data UUID definitions (both left and right)
- [x] Added `shoulderQuaternionChar` and `shoulderRawDataChar` characteristic pointers
- [x] Updated UUID selection logic to include shoulder characteristics for right hubs and chest
- [x] Added shoulder characteristic creation in setup (quaternion and raw data)
- [x] Updated raw data notification logic to include shoulder data
- [x] Added placeholder for shoulder quaternion notification (will be enabled in Stage 6 when structure is updated)
- [x] Verified chest behavior: chest is a hub but has no children, so child characteristics won't send data (only hub's own data)

### Notes
- Shoulder quaternion notification is prepared but will be fully enabled in Stage 6 when `AggregatedQuaternionData` structure is updated
- Chest hub correctly only sends its own data (no children to aggregate)
- Right hubs (hand, forearm, shoulder) expose characteristics for their own data + their corresponding left child data
- UUID selection correctly differentiates between right hubs and chest

### Next Steps
- Proceed to Stage 4: Calibration Command Updates

---

## Stage 4: Calibration Command Updates
**Status:** ✅ Completed

### Objectives
- Update calibration commands to work with new hub/child relationships
- Ensure right hubs can send calibration to their left children
- Ensure chest can calibrate itself (no children to send to)

### Files Modified
1. `firmware/src/Role_Services/HubClient_Service.cpp` - Calibration command sending
2. `firmware/src/BLE_Services/BLE_Polling_Service.cpp` - Calibration handling
3. `firmware/src/main.cpp` - Calibration polling setup and child command reception

### Changes Completed
- [x] Updated `sendCalibrationCommand()` with clarifying comments about right hubs and chest behavior
- [x] Added check for zero children (chest has no children, so calibration command won't be sent)
- [x] Updated calibration handling to clarify that hub resets its own IMU first, then sends to children
- [x] Verified calibration polling is enabled for all hubs (right hand, right forearm, right shoulder, chest)
- [x] Updated child command reception comments to clarify left children receive from right hubs
- [x] Added clarifying comments throughout calibration code

### Notes
- Calibration system already worked correctly with new architecture
- Right hubs: Reset own IMU, then send calibration to their left child via ESP-NOW
- Chest: Resets own IMU only (no children to send commands to)
- Left children: Receive calibration commands from their right hub via ESP-NOW and reset their IMU
- Each right hub has exactly one left child, so calibration is sent to that one child

### Next Steps
- Proceed to Stage 5: Role Change Handling

---

## Stage 5: Role Change Handling
**Status:** ✅ Completed

### Objectives
- Update role change handling to support new role names
- Update ESP-NOW initialization for left children
- Update hub initialization for right devices

### Files Modified
1. `firmware/src/BLE_Services/BLE_Polling_Service.cpp` - Role change handling
2. `firmware/src/main.cpp` - Setup initialization comments

### Changes Completed
- [x] Updated `handleRoleChange()` comments to clarify left children and right hubs
- [x] Added hub initialization logic when device changes to hub role (right hand, right forearm, right shoulder, chest)
- [x] Updated ESP-NOW initialization logic comments for left children (hand, forearm, shoulder)
- [x] Added `setupHubClientService()` call when role changes to hub role at runtime
- [x] Updated role validation comments to list all valid roles
- [x] Updated setup initialization comments to clarify left child behavior
- [x] Verified phone can assign all new roles correctly (role validation already supports all roles)

### Notes
- Role change handling already supported all new roles from Stage 1
- Added runtime hub initialization when device changes to hub role
- Left children initialize ESP-NOW sender when role is assigned
- Right hubs and chest initialize hub client service when role is assigned
- All role assignments work correctly via BLE

### Next Steps
- Proceed to Stage 6: Data Aggregation Logic

---

## Stage 6: Data Aggregation Logic
**Status:** ✅ Completed

### Objectives
- Update aggregation to include shoulder data
- Ensure right hubs aggregate hub data + left children data
- Ensure chest only sends its own data

### Files Modified
1. `firmware/src/Role_Services/Hub_Structures.h` - Data structures
2. `firmware/src/Role_Services/HubClient_Service.cpp` - Aggregation logic
3. `firmware/src/main.cpp` - Data transmission

### Changes Completed
- [x] Modified `AggregatedQuaternionData` to include `shoulderData` and `shoulderConnected`
- [x] Modified `AggregatedRawData` to include `shoulderData` and `shoulderConnected`
- [x] Updated `syncConnectionStatus()` to aggregate data from all three child types (hand, forearm, shoulder)
- [x] Updated constructor to initialize `shoulderConnected = false`
- [x] Updated `begin()` to initialize `shoulderConnected = false`
- [x] Updated `sendQuaternionReport()` to send shoulder quaternion data via LEFT characteristic
- [x] Raw data notification already works correctly (sends whatever child data is available)
- [x] Added clarifying comments about each hub having exactly one left child

### Notes
- Each right hub aggregates its own data (hubData) + its left child's data (handData, forearmData, or shoulderData)
- Right hand hub aggregates: hubData + handData (from left hand)
- Right forearm hub aggregates: hubData + forearmData (from left forearm)
- Right shoulder hub aggregates: hubData + shoulderData (from left shoulder)
- Chest hub aggregates: hubData only (no children)
- MAIN characteristics send hub's own data
- LEFT characteristics send left child's data
- All aggregation logic now supports all three child types

### Next Steps
- ✅ **All stages complete!** The rearchitecture is finished.

---

## Summary

All 6 stages of the rearchitecture have been completed successfully:

1. ✅ **Stage 1: Role System Changes** - Renamed roles, updated role detection
2. ✅ **Stage 2: ESP-NOW Communication Changes** - Updated to left→right communication
3. ✅ **Stage 3: BLE Characteristic Updates** - Simplified to MAIN and LEFT characteristics
4. ✅ **Stage 4: Calibration Command Updates** - Verified calibration works for all hub types
5. ✅ **Stage 5: Role Change Handling** - Added runtime hub initialization
6. ✅ **Stage 6: Data Aggregation Logic** - Added shoulder data support

### Final Architecture

**Hubs (send to phone via BLE):**
- Right Hand Hub ← Left Hand (via ESP-NOW)
- Right Forearm Hub ← Left Forearm (via ESP-NOW)
- Right Shoulder Hub ← Left Shoulder (via ESP-NOW)
- Chest Hub (no children, sends own data only)

**Children (send to hub via ESP-NOW):**
- Left Hand → Right Hand Hub
- Left Forearm → Right Forearm Hub
- Left Shoulder → Right Shoulder Hub

**Characteristics:**
- MAIN Quaternion: Device's own quaternion data (all devices)
- MAIN Raw Data: Device's own raw data (all devices)
- LEFT Quaternion: Left child quaternion data (right hubs only)
- LEFT Raw Data: Left child raw data (right hubs only)

---

## Implementation Progress

### Stage 1: Role System Changes
**Status:** ✅ Completed

**Completed:**
- [x] Role enum renamed (`ROLE_LEFT_HUB` → `ROLE_LEFT_SHOULDER`, `ROLE_RIGHT_HUB` → `ROLE_RIGHT_SHOULDER`)
- [x] Role name strings updated in `getRoleName()`
- [x] `isHubMode()` updated to return true for: `ROLE_RIGHT_HAND`, `ROLE_RIGHT_FOREARM`, `ROLE_RIGHT_SHOULDER`, `ROLE_CHEST`
- [x] `isNodeMode()` updated to return true for: `ROLE_LEFT_HAND`, `ROLE_LEFT_FOREARM`, `ROLE_LEFT_SHOULDER`
- [x] `isValidRole()` updated to include new role values
- [x] Updated all role checks in `main.cpp` (ESP-NOW initialization, data sending, child data notification, periodic logging)
- [x] Updated UUID selection logic in `main.cpp` for right hubs
- [x] Updated role checks in `BLE_Polling_Service.cpp` for role change handling
- [x] Updated role checks in `HubClient_Service.cpp` (child tracking, disconnection, aggregation)

**Files Modified:**
- `firmware/src/DeviceConfig.h` - Role enum definitions
- `firmware/src/DeviceConfig.cpp` - Role logic implementation
- `firmware/src/main.cpp` - Role checks and UUID selection
- `firmware/src/BLE_Services/BLE_Polling_Service.cpp` - Role change handling
- `firmware/src/Role_Services/HubClient_Service.cpp` - Child role checks

**Next Steps:**
- Proceed to Stage 2: ESP-NOW Communication Changes
- Test role assignment via BLE (to be done in Stage 5)

---

## Testing Checklist

### Stage 1 Testing
- [ ] Verify all roles can be assigned via BLE
- [ ] Verify `isHubMode()` returns correct values
- [ ] Verify `isNodeMode()` returns correct values
- [ ] Verify role names display correctly

### Stage 2 Testing
- [ ] Left hand sends ESP-NOW to right hand hub
- [ ] Left forearm sends ESP-NOW to right forearm hub
- [ ] Left shoulder sends ESP-NOW to right shoulder hub
- [ ] Right hubs receive and process ESP-NOW data

### Stage 3 Testing
- [ ] Right hubs expose all child characteristics
- [ ] Chest only sends own data
- [ ] BLE notifications work for all characteristics

### Stage 4 Testing
- [ ] Right hubs send calibration to left children
- [ ] Calibration polling works on all hubs
- [ ] Chest calibration works

### Stage 5 Testing
- [ ] Role changes work for all new roles
- [ ] ESP-NOW initializes correctly after role change
- [ ] Hub MAC addresses are correctly assigned

### Stage 6 Testing
- [ ] Data aggregation includes all child types
- [ ] Right hubs send aggregated data correctly
- [ ] Chest sends only own data

---

## Notes

- No backward compatibility needed - all devices will be force updated
- MAX_CHILDREN may need to be increased from 2 to 3
- UUID management for right hubs may need distinct UUIDs for child characteristics
- Data structure size increases with shoulder data - verify BLE MTU limits

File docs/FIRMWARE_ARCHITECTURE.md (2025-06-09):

# Firmware Architecture

## Overview

The Eidon Tracker firmware is built using the Arduino framework for the nRF52840 platform, leveraging the Adafruit nRF52 BSP and Bluefruit libraries for BLE functionality.

## Build System

### PlatformIO Configuration
- **Platform**: Seeed nRF52 boards
- **Board**: `seeed-xiao-afruitnrf52-nrf52840`
- **Framework**: Arduino
- **Key Dependencies**:
  - Adafruit BNO08x (v1.2.3+)
  - Adafruit Bluefruit nRF52 Libraries
  - Adafruit SPIFlash

### Build Process
```bash
# Build firmware
cd firmware
pio run

# Upload firmware
pio run --target upload

# Monitor serial output
pio device monitor
```

## Code Structure

### Main Components

1. **BLE Stack**
   - Dual-mode operation: HID + Custom GATT
   - Service advertisement and connection management
   - Optimized for low latency (7.5-15ms connection interval)

2. **IMU Interface**
   - BNO085 driver with I2C communication
   - Interrupt-driven data acquisition
   - Quaternion output with 180° Z-axis correction

3. **Data Flow**
   ```
   BNO085 IMU → Interrupt → Read Quaternion → Apply Correction → 
   → Send via HID Report → Send via GATT Notification
   ```

4. **Persistent Storage**
   - QSPI Flash for configuration storage
   - Color settings persistence
   - Wear leveling considerations

## Key Functions

### Initialization
- `setup()`: Hardware initialization, BLE service configuration
- `initIMU()`: BNO085 sensor initialization
- `initBatteryMonitoring()`: ADC configuration for battery monitoring

### Main Loop
- `loop()`: Continuous sensor reading and data transmission
- `updateOrientation()`: Process IMU data
- `sendQuaternionReport()`: Dual-protocol data transmission

### BLE Callbacks
- `handleCommand()`: HID output report handler
- `gattCalibrationCallback()`: GATT calibration commands
- `gattColorCallback()`: GATT color configuration
- `handleColorFeature()`: HID feature report handler

## Memory Management

### RAM Usage
- BLE stack: ~50KB
- Application: ~20KB
- Buffers: ~10KB
- Total: ~80KB of 256KB available

### Flash Usage
- Bootloader: 152KB
- Application: ~300KB
- Total: ~452KB of 1MB available

## Power Management

### Active Mode
- Continuous BLE transmission
- IMU sampling at 200Hz (post-calibration)
- LED status indication

### Power Optimization
- Battery monitoring every 5 minutes
- Efficient BLE connection parameters
- Hardware interrupt for IMU data ready

## Error Handling

### Startup Errors
- IMU initialization failure: Rapid LED flashing
- Flash initialization failure: Continue without persistence

### Runtime Errors
- BLE transmission failures: Logged but non-blocking
- Invalid commands: Ignored with serial logging

## Debugging

### Serial Output
- Baud rate: 115200
- Debug messages for all major operations
- Quaternion data can be enabled for debugging

### DFU Mode
- Triggered by sending 'D' over serial during startup
- Allows OTA firmware updates

## Performance Metrics

### Latency
- IMU to BLE transmission: <5ms typical
- Total system latency: <20ms

### Throughput
- Quaternion updates: 200Hz
- BLE notifications: Up to 200Hz
- HID reports: Up to 200Hz

## Future Considerations

### Planned Improvements
1. Dynamic IMU sampling rate adjustment
2. Advanced power management modes
3. Over-the-air configuration updates
4. Extended telemetry data

### Scalability
- Support for multiple IMU configurations
- Extensible GATT service design
- Modular architecture for feature additions

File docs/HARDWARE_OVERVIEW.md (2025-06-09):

# Hardware Overview

## Device Specifications

### Main Board: XIAO nRF52840 Sense
- **MCU**: Nordic nRF52840
- **CPU**: ARM Cortex-M4F @ 64MHz
- **Memory**: 256KB RAM, 1MB Flash
- **Bluetooth**: BLE 5.0
- **Power**: 3.3V operating voltage
- **Size**: 21 x 17.5mm

### IMU: BNO085
- **Type**: 9-axis IMU with sensor fusion
- **Interface**: I2C
- **Output**: Quaternion, Euler angles, Linear acceleration
- **Sample Rate**: Up to 1000Hz
- **Accuracy**: ±2° RMS (dynamic), ±1° RMS (static)

### Additional Components
- **Flash Storage**: 2MB QSPI Flash (P25Q16H)
- **Battery Monitoring**: Built-in ADC with voltage divider
- **LEDs**: RGB LED for status indication
- **Switches**: 2 position detection switches

## Pin Configuration

### I2C Bus (BNO085)
- **SDA**: Pin D9
- **SCL**: Pin D10
- **INT**: Pin D8 (Interrupt for data ready)
- **Address**: 0x4B

### Switch Inputs
- **Left/Right Switch**:
  - Output: D5
  - Input: D6
- **Upper/Lower Switch**:
  - Output: D0
  - Input: D1

### Power Management
- **VBAT**: Pin D32 (Battery voltage monitoring)
- **VBAT_ENABLE**: Pin D14 (LOW to enable reading)
- **HICHG**: Pin D22 (Charge current: LOW=100mA, HIGH=50mA)
- **CHG**: Pin D23 (Charge indicator: LOW=charging, HIGH=not charging)

### Status LEDs
- **Main LED**: PIN_LED (Built-in)
- **Green LED**: LED_GREEN (RGB LED, active low)

## Power Specifications

### Battery
- **Type**: LiPo single cell
- **Voltage Range**: 3.3V - 4.2V
- **Monitoring**: 12-bit ADC with 2.961:1 voltage divider
- **Charging**: Built-in charging circuit

### Power Consumption
- **Active BLE**: ~15mA typical
- **Sleep Mode**: <10µA
- **Peak**: ~30mA during BLE transmission

## Mechanical Design

### Enclosure Requirements
- Waterproof rating: IP67 recommended
- IMU mounting: Rigid mounting required for accurate readings
- Orientation: Device switches indicate position (left/right, upper/lower)

### Mounting Considerations
- IMU pre-calibrated for 180° Z-axis rotation
- Double-tap detection enabled for calibration trigger
- Switches must be accessible for position detection

## Communication Interfaces

### Bluetooth Low Energy
- **Profile**: Dual mode (HID + Custom GATT)
- **Connection Interval**: 7.5-15ms
- **TX Power**: Adjustable, default 0dBm
- **Range**: ~30m line of sight

### USB
- **Type**: USB-C
- **Purpose**: Charging, firmware updates, serial debug
- **DFU Mode**: Accessible via serial command 'D'

## Environmental Specifications

### Operating Conditions
- **Temperature**: -20°C to +70°C
- **Humidity**: 10% to 90% non-condensing
- **Vibration**: Suitable for wearable applications

### Storage Conditions
- **Temperature**: -40°C to +85°C
- **Humidity**: 5% to 95% non-condensing

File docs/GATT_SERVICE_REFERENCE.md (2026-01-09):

EIDON TRACKER - BLE GATT SERVICE REFERENCE
==========================================

FIRMWARE VERSION: 1.0.0
DEVICE: Seeed XIAO ESP32-C6 with BNO085 IMU

SERVICE AND CHARACTERISTIC UUIDS
================================

Service UUID:
E1D00001-8B5A-3E5B-9E23-4F9B5C91BBDE

Characteristic UUIDs:
- Quaternion Data:  E1D00002-8B5A-3E5B-9E23-4F9B5C91BBDE  (Notify/Read)
- Calibration:      E1D00003-8B5A-3E5B-9E23-4F9B5C91BBDE  (Write/Read)
- Color:            E1D00004-8B5A-3E5B-9E23-4F9B5C91BBDE  (Write/Read)
- Device Info:      E1D00005-8B5A-3E5B-9E23-4F9B5C91BBDE  (Read)

DEVICE DISCOVERY
================

Device Name Format: "Eidon Tracker-XXXX" (where XXXX is unique per device)
Service Filter: E1D00001-8B5A-3E5B-9E23-4F9B5C91BBDE

DATA FORMATS
============

1. QUATERNION DATA (20 bytes total)
-----------------------------------
Bytes 0-3:   float w (little-endian)
Bytes 4-7:   float x (little-endian)
Bytes 8-11:  float y (little-endian)
Bytes 12-15: float z (little-endian)
Byte 16:     switches (bit 0: isLeft, bit 1: isUpper)
Bytes 17-19: reserved (padding)

2. CALIBRATION COMMANDS (1 byte)
--------------------------------
0x01: Trigger IMU calibration/reset
0x02: Request device info update

3. COLOR DATA (3 bytes)
-----------------------
Byte 0: Red (0-255)
Byte 1: Green (0-255)
Byte 2: Blue (0-255)

4. DEVICE INFO (14 bytes)
-------------------------
Bytes 0-1:   Device ID (uint16, little-endian)
Byte 2:      Firmware version major (uint8)
Byte 3:      Firmware version minor (uint8)
Byte 4:      Firmware version patch (uint8)
Byte 5:      Battery level (0-100%)
Byte 6:      Device role (DeviceRole enum value)
Bytes 7-12:  MAC address (6 bytes, WiFi MAC address)

FLUTTER/DART CODE EXAMPLES
==========================

// Service and Characteristic UUIDs
const String EIDON_SERVICE_UUID = "E1D00001-8B5A-3E5B-9E23-4F9B5C91BBDE";
const String QUATERNION_CHAR_UUID = "E1D00002-8B5A-3E5B-9E23-4F9B5C91BBDE";
const String CALIBRATION_CHAR_UUID = "E1D00003-8B5A-3E5B-9E23-4F9B5C91BBDE";
const String COLOR_CHAR_UUID = "E1D00004-8B5A-3E5B-9E23-4F9B5C91BBDE";
const String DEVICE_INFO_CHAR_UUID = "E1D00005-8B5A-3E5B-9E23-4F9B5C91BBDE";

// Quaternion Data Parser
class QuaternionData {
  double w, x, y, z;
  bool isLeft;
  bool isUpper;
  
  QuaternionData.fromBytes(Uint8List bytes) {
    // Parse 4 floats (little-endian)
    var buffer = bytes.buffer;
    var data = ByteData.view(buffer);
    
    w = data.getFloat32(0, Endian.little);
    x = data.getFloat32(4, Endian.little);
    y = data.getFloat32(8, Endian.little);
    z = data.getFloat32(12, Endian.little);
    
    // Parse switch states
    int switches = bytes[16];
    isLeft = (switches & 0x01) != 0;
    isUpper = (switches & 0x02) != 0;
  }
}

// Device Info Parser
class DeviceInfo {
  int deviceId;
  String firmwareVersion;
  int batteryLevel;
  int deviceRole;
  List<int> macAddress;
  
  DeviceInfo.fromBytes(Uint8List bytes) {
    if (bytes.length < 14) {
      throw Exception('Device info must be 14 bytes, got ${bytes.length}');
    }
    
    var data = ByteData.view(bytes.buffer);
    
    deviceId = data.getUint16(0, Endian.little);
    int major = bytes[2];
    int minor = bytes[3];
    int patch = bytes[4];
    firmwareVersion = "$major.$minor.$patch";
    batteryLevel = bytes[5];
    deviceRole = bytes[6];
    macAddress = bytes.sublist(7, 13);
  }
}

// Example: Connect and Subscribe to Quaternion Data
Future<void> connectToDevice(BluetoothDevice device) async {
  await device.connect();
  
  List<BluetoothService> services = await device.discoverServices();
  
  for (BluetoothService service in services) {
    if (service.uuid.toString().toUpperCase() == EIDON_SERVICE_UUID) {
      for (BluetoothCharacteristic char in service.characteristics) {
        switch (char.uuid.toString().toUpperCase()) {
          case QUATERNION_CHAR_UUID:
            // Enable notifications
            await char.setNotifyValue(true);
            
            // Listen to quaternion updates
            char.value.listen((value) {
              if (value.length >= 20) {
                var quaternion = QuaternionData.fromBytes(value);
                // Process quaternion data
                print('W: ${quaternion.w}, X: ${quaternion.x}, Y: ${quaternion.y}, Z: ${quaternion.z}');
                print('Left: ${quaternion.isLeft}, Upper: ${quaternion.isUpper}');
              }
            });
            break;
            
          case CALIBRATION_CHAR_UUID:
            // Store for later use
            calibrationChar = char;
            break;
            
          case COLOR_CHAR_UUID:
            // Store for later use
            colorChar = char;
            break;
            
          case DEVICE_INFO_CHAR_UUID:
            // Read device info
            var infoBytes = await char.read();
            var deviceInfo = DeviceInfo.fromBytes(infoBytes);
            print('Device ID: ${deviceInfo.deviceId}');
            print('Firmware: ${deviceInfo.firmwareVersion}');
            print('Battery: ${deviceInfo.batteryLevel}%');
            print('Role: ${deviceInfo.deviceRole}');
            print('MAC: ${deviceInfo.macAddress.map((b) => b.toRadixString(16).padLeft(2, '0')).join(':')}');
            break;
        }
      }
    }
  }
}

// Example: Trigger Calibration
Future<void> calibrateIMU() async {
  if (calibrationChar != null) {
    await calibrationChar.write([0x01]);
  }
}

// Example: Set Color
Future<void> setDeviceColor(int r, int g, int b) async {
  if (colorChar != null) {
    await colorChar.write([r, g, b]);
  }
}

CONNECTION PARAMETERS
=====================

Recommended for optimal performance:
- Connection Interval: 7.5-15ms
- Enable notifications immediately after connection
- The device streams quaternion data continuously when notifications are enabled

MULTIPLE DEVICE SUPPORT
=======================

- Each device has a unique suffix in its name (last 4 hex digits of BLE address)
- Devices can be differentiated by their switch states (isLeft/isUpper)
- iOS supports up to 6 simultaneous BLE connections
- Android typically supports 7-10 simultaneous connections

IMPORTANT NOTES
===============

1. The firmware supports both BLE HID and custom GATT services
2. iOS apps should use the custom GATT service (HID is restricted on iOS)
3. Android/Windows/macOS can use either HID or GATT
4. Quaternion data is pre-corrected for IMU mounting (180° Z-axis rotation applied)
5. Battery level updates every 5 minutes to minimize power consumption
6. Color settings are persisted in flash memory
7. Double-tap on device triggers calibration (hardware feature)

CALIBRATION PROCESS
===================

When calibration is triggered (via GATT command 0x01 or double-tap):
1. Blue LED turns on
2. IMU streaming stops momentarily
3. IMU is reset and recalibrated
4. Streaming resumes at 200Hz
5. Blue LED turns off after 2 seconds
6. Acknowledgment byte (0x01) is written to calibration characteristic

ERROR HANDLING
==============

- If IMU initialization fails, device LED flashes rapidly
- Failed HID reports are logged but don't affect GATT notifications
- Color values outside RGB range are clamped to 0-255
- Invalid calibration commands are ignored

PERFORMANCE SPECIFICATIONS
==========================

- IMU sampling rate: Up to 1000Hz (currently set to 200Hz after calibration)
- BLE connection interval: 7.5-15ms
- Quaternion precision: 32-bit float
- Battery monitoring: 12-bit ADC resolution
- Flash storage: 2MB QSPI flash for persistent settings

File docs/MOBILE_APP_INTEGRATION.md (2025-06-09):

# Mobile App Integration Guide

## Overview

This guide provides step-by-step instructions for integrating Eidon Tracker devices with mobile applications using Flutter and native iOS/Android development.

## Prerequisites

### Flutter Development
- Flutter SDK 3.0+
- Dart 2.17+
- flutter_blue_plus package (or similar BLE library)

### iOS Development
- iOS 13.0+
- Info.plist permissions:
  ```xml
  <key>NSBluetoothAlwaysUsageDescription</key>
  <string>This app needs Bluetooth to connect to Eidon Trackers</string>
  <key>NSBluetoothPeripheralUsageDescription</key>
  <string>This app needs Bluetooth to receive motion data</string>
  ```
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

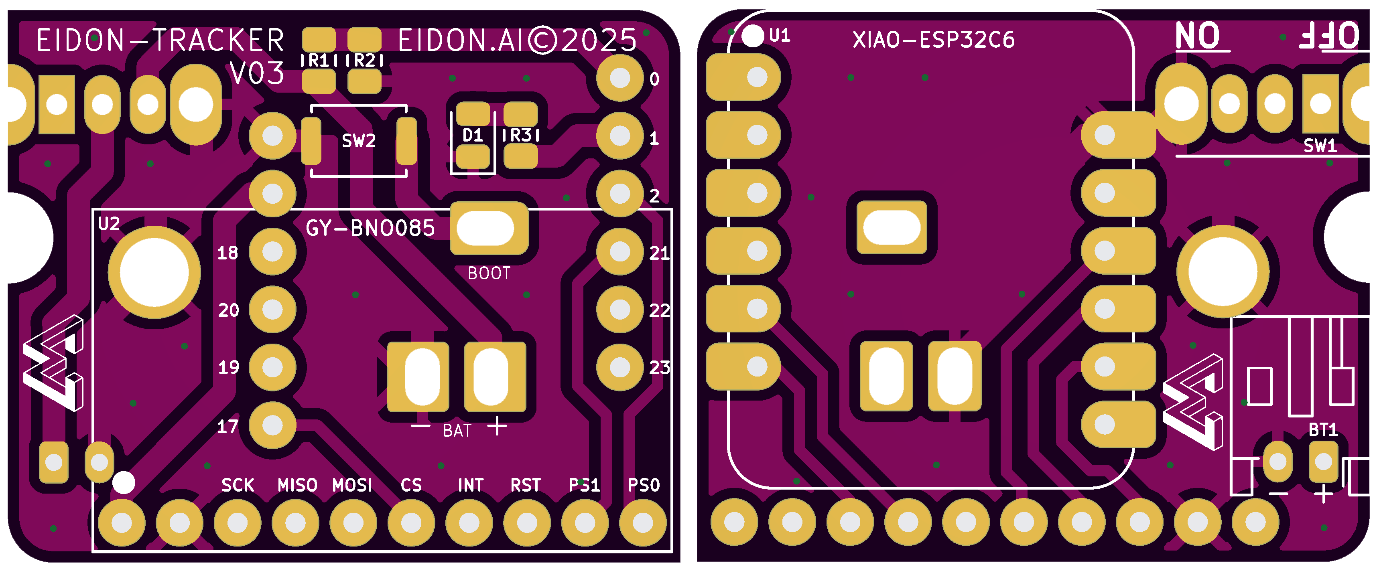
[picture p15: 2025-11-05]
images/whitepaper/PCB_DESIGN.png

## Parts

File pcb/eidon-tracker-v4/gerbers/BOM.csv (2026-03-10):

Reference | Qty | Value | Exclude from BOM | Footprint | Manufacturer Part Number (MPN) | Supplier & Ref
BT1 | 1 | Battery |  | Connector_JST:JST_PH_S2B-PH-K_1x02_P2.00mm_Horizontal_Inversed | JST S2B-PH-K-S(LF)(SN) | Digi-Key 455-S2B-PH-K
C1,C2 | 2 | 22pF |  | Capacitor_SMD:C_0603_1608Metric | SAMSUNG CL10C220JB8NNNC | LCSC C1653
C3,C4,C5 | 3 | 100nF |  | Capacitor_SMD:C_0603_1608Metric | YAGEO CC0603KRX7R9BB104 | LCSC C14663
R1,R2 | 2 | 220kΩ |  | Resistor_SMD:R_0805_2012Metric | Yageo RC0805FR-07220KL | LCSC C25811
R3,R4 | 2 | 2.2kΩ |  | Resistor_SMD:R_0805_2012Metric | YAGEO RC0805FR‑072K2L | LCSC C114561
R5,R6,R7 | 3 | 10kΩ |  | Resistor_SMD:R_0805_2012Metric | YAGEO RC0805FR-0710KL | LCSC C84376
SW1 | 1 | SW_SPDT |  | Button_Switch_THT:SW_Slide_SPDT_Angled_CK_OS102011MA1Q | CK OS102011MA1QN1 | LCSC C226259
U1 | 1 | XIAO-ESP32-C6 |  | eidon-tracker:XIAO-ESP32C6-SMD | Seeed 113991114 | Seeed / Digi-Key
U2 | 1 | BNO085 |  | eidon-tracker:BNO085
X1 | 1 | 32.768KHz |  | Crystal:Crystal_SMD_3215-2Pin_3.2x1.5mm | TKD SF32K32768D31T-12.5 | LCSC C271654

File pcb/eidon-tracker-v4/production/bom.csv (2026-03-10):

Designator | Footprint | Quantity | Value | LCSC Part #
BT1 | JST_PH_S2B-PH-K_1x02_P2.00mm_Horizontal_Inversed | 1 | Battery
C1, C2 | 0603 | 2 | 22pF
C3, C4, C5 | 0603 | 3 | 100nF
R1, R2 | 0805 | 2 | 220K
R3, R4 | 0805 | 2 | 2.2K
R5, R6, R7 | 0805 | 3 | 10K
SW1 | SW_Slide_SPDT_Angled_CK_OS102011MA1Q | 1 | SW_SPDT
U1 | XIAO-ESP32C6-SMD | 1 | XIAO-ESP32-C6
U2 | BNO085 | 1 | BNO085
X1 | Crystal_SMD_3215-2Pin_3.2x1.5mm | 1 | 32.768KHz

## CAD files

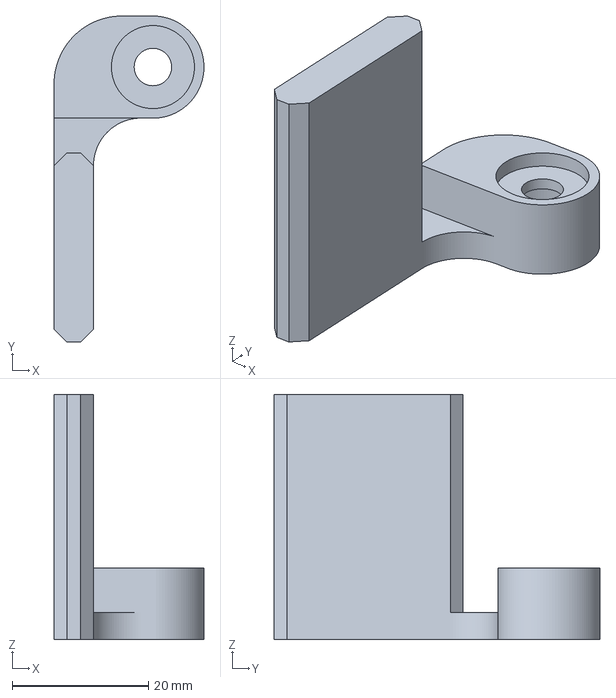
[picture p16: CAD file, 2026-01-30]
cad/EIDON_TRACKER_CHEST_MOUNT.3mf
22.0 x 47.9 x 36.0 mm

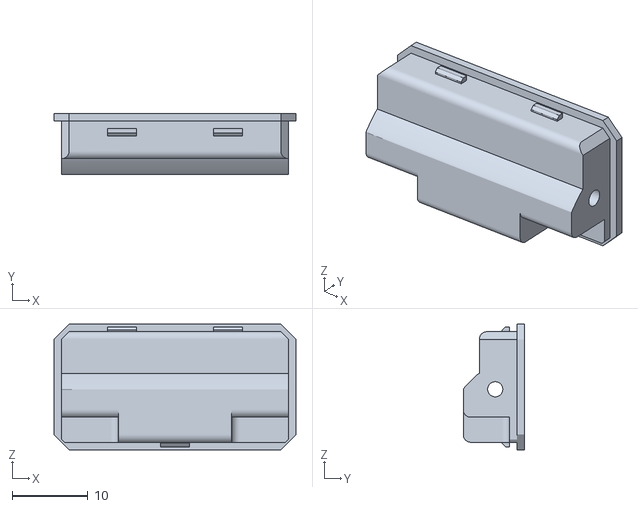
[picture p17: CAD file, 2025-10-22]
cad/eidon-tracker-v3b-lid-0.stl
32.0 x 8.12 x 16.6

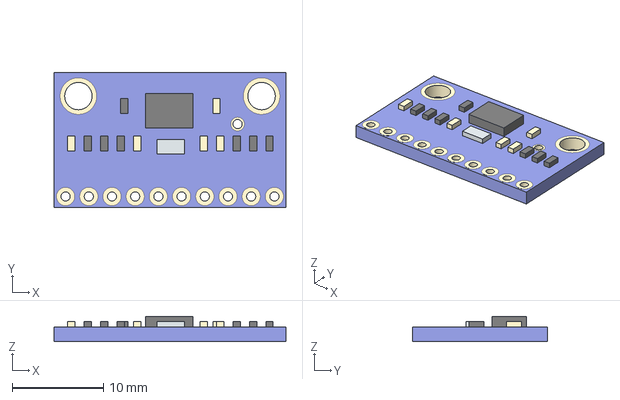
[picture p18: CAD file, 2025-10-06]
pcb/eidon-tracker-v4/models/GY_BNO085.step
25.4 x 14.8 x 2.75 mm

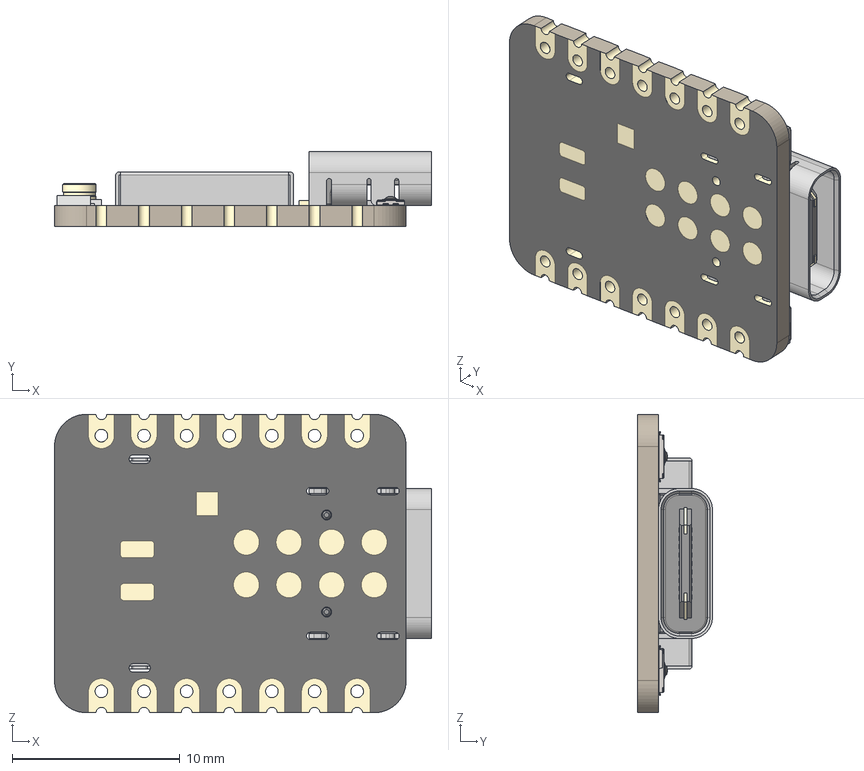
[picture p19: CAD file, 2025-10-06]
pcb/eidon-tracker-v4/models/XIAO_ESP32C6.step
22.5 x 4.46 x 17.8 mm
BOSS-EXTRUDE14_8_
BOSS-EXTRUDE7_4_
BOSS-EXTRUDE7_3_
BOSS-EXTRUDE14_4_
BOSS-EXTRUDE14_2_
BOSS-EXTRUDE14_11_
BOSS-EXTRUDE7_7_
BOSS-EXTRUDE14_9_
BOSS-EXTRUDE14_3_
BOSS-EXTRUDE14_7_
MIRROR2
BOSS-EXTRUDE14_5_
BOSS-EXTRUDE14_12_
BOSS-EXTRUDE7_8_
BOSS-EXTRUDE7_1_
BOSS-EXTRUDE14_10_
BOSS-EXTRUDE7_9_
BOSS-EXTRUDE14_6_
BOSS-EXTRUDE14_1_
BOSS-EXTRUDE7_6_
BOSS-EXTRUDE7_2_
CUT-EXTRUDE5
BOSS-EXTRUDE7_5_
U.FL Connector v1
Shield
SKTAAAE010 x 2
KH5220-A36 (Ceramic Antenna) v2

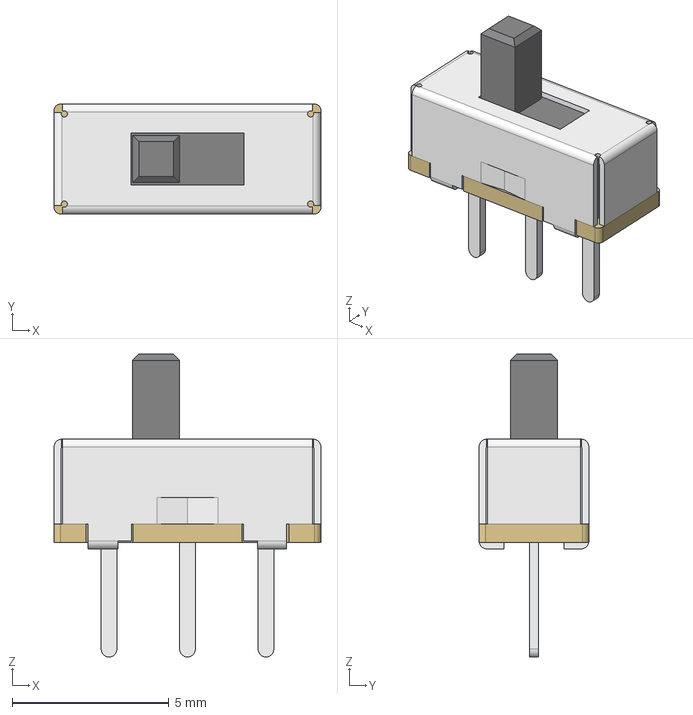
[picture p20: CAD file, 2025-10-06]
pcb/eidon-tracker-v4/models/SS12D00.step
8.50 x 3.50 x 9.66 mm

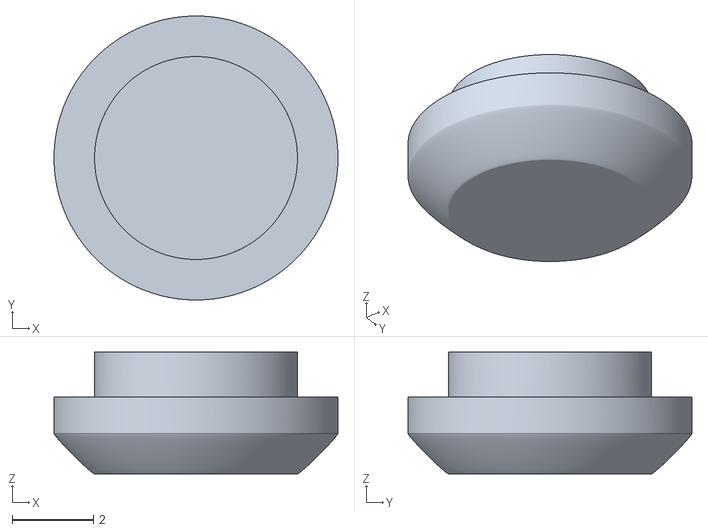
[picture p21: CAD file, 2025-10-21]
cad/eidon-tracker-v3b-btn.stl
7.00 x 7.00 x 3.00

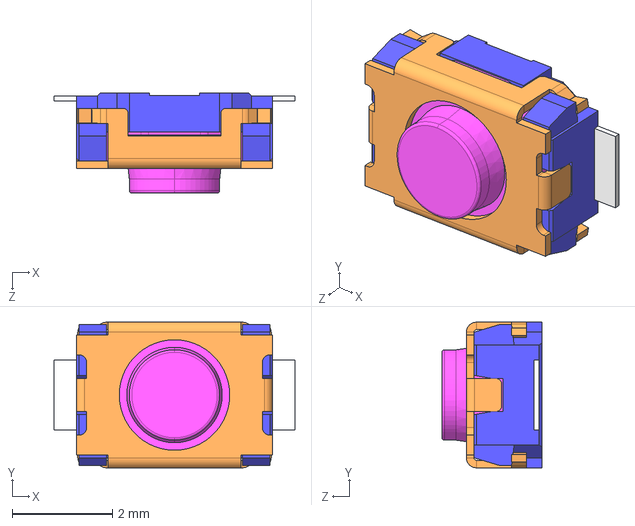
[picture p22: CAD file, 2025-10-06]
pcb/eidon-tracker-v4/models/SKRKAH.step
4.80 x 2.90 x 2.00 mm

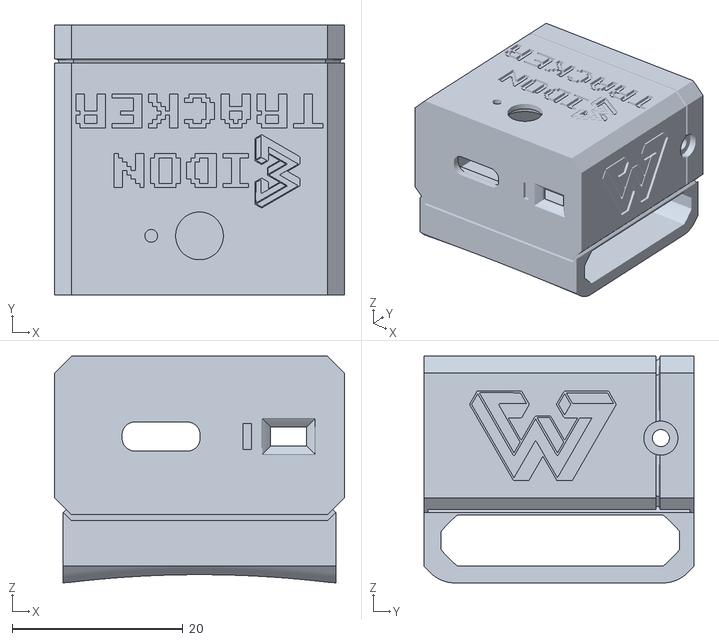
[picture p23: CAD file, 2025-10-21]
cad/eidon-tracker-v3b-body.stl
34.0 x 31.7 x 26.6

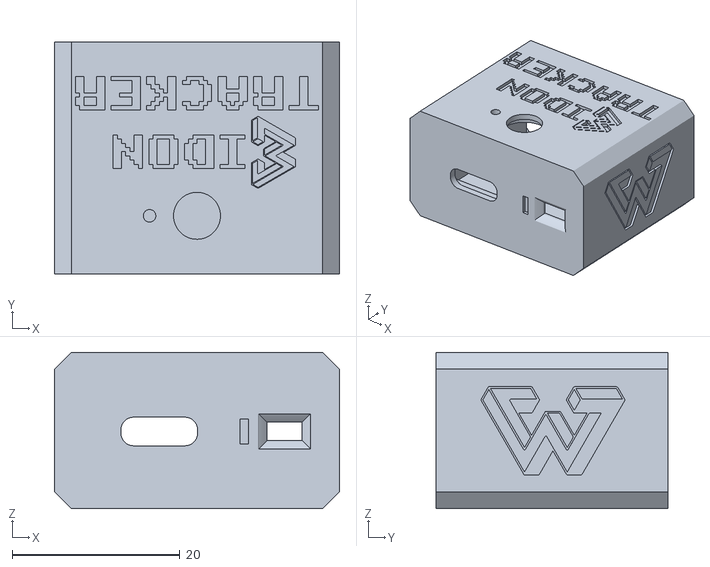
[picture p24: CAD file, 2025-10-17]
cad/eidon-tracker-v3a-body.stl
34.0 x 27.7 x 18.6

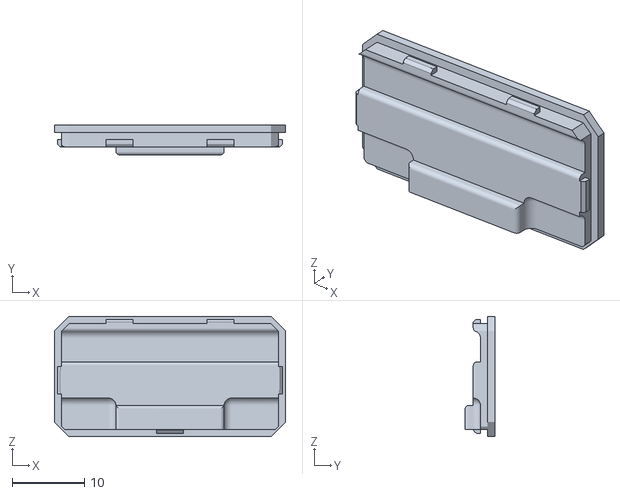
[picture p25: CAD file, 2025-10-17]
cad/eidon-tracker-v3a-lid.stl
32.0 x 4.12 x 16.6

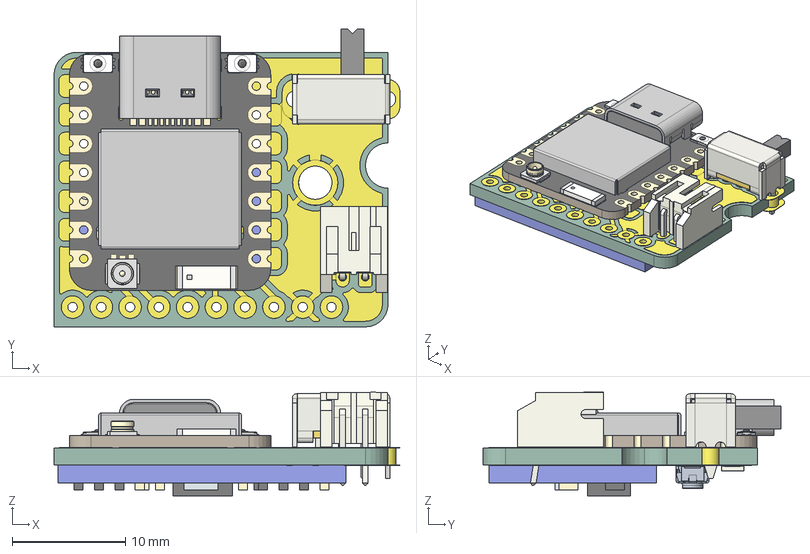
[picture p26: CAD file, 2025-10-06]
cad/eidon-tracker.step
30.6 x 26.3 x 9.18 mm
BOSS-EXTRUDE14_8_
BOSS-EXTRUDE7_4_
BOSS-EXTRUDE7_3_
BOSS-EXTRUDE14_4_
BOSS-EXTRUDE14_2_
BOSS-EXTRUDE14_11_
BOSS-EXTRUDE7_7_
BOSS-EXTRUDE14_9_
BOSS-EXTRUDE14_3_
BOSS-EXTRUDE14_7_
MIRROR2
BOSS-EXTRUDE14_5_
BOSS-EXTRUDE14_12_
BOSS-EXTRUDE7_8_
BOSS-EXTRUDE7_1_
BOSS-EXTRUDE14_10_
BOSS-EXTRUDE7_9_
BOSS-EXTRUDE14_6_
BOSS-EXTRUDE14_1_
BOSS-EXTRUDE7_6_
BOSS-EXTRUDE7_2_
CUT-EXTRUDE5
BOSS-EXTRUDE7_5_
U.FL Connector v1
Shield
SKTAAAE010 v1 x 2
KH5220-A36 (Ceramic Antenna) v2
JST_PH_S2B-PH-K_1x02_P2.00mm_Horizontal
SW_Slide_SPDT_Angled_CK_OS102011MA1Q
LED_0805_2012Metric
GY-BNO08X
R_0805_2012Metric x 3
eidon-tracker 1.9
eidon-tracker_copper
eidon-tracker_PCB

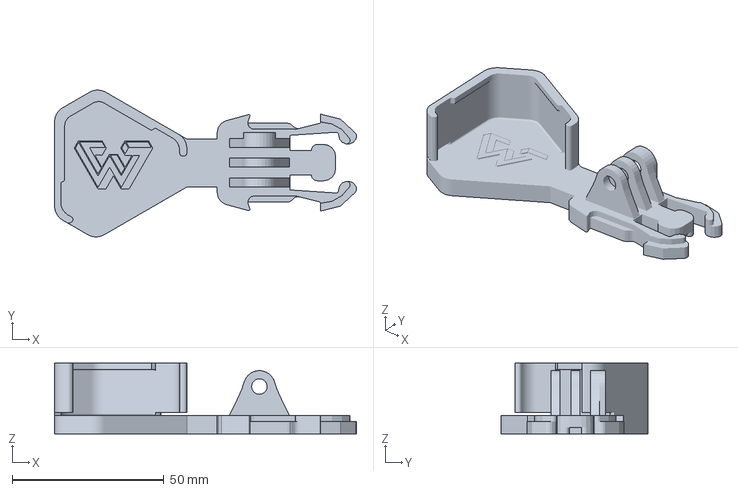
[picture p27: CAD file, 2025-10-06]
cad/eidon-tracker-mount-chest-B.3mf
99.5 x 48.3 x 23.2 mm

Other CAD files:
cad/eidon-tracker-v3b-lid-2.stl
cad/eidon-tracker-v3b-lid-1.stl
cad/eidon-tracker-v3a-lid-1.stl
cad/eidon-tracker-v3a-lid-2.stl
cad/eidon-tracker-v3a-btn.stl
cad/EIDON_TRACKER_CHEST_MOUNT.stl
cad/eidon-tracker-base.stl
cad/eidon-tracker-batch-arms.3mf
cad/eidon-tracker-batch-chest.3mf
cad/eidon-tracker-batch-mount.3mf
cad/eidon-tracker-mount-arm.3mf
cad/eidon-tracker-mount-arm.stl
cad/eidon-tracker-mount-chest-B.stl
cad/eidon-tracker-mount-chest.3mf
cad/eidon-tracker-mount-chest.stl
cad/eidon-tracker-top-1.stl
cad/eidon-tracker-top-2.stl
cad/eidon-tracker-top.stl
cad/eidon-tracker-v3.f3d
cad/eidon-tracker-v3a.f3d
cad/eidon-tracker-v3b.f3d
cad/eidon-tracker.f3z
cad/eidon-tracker.gcode.3mf

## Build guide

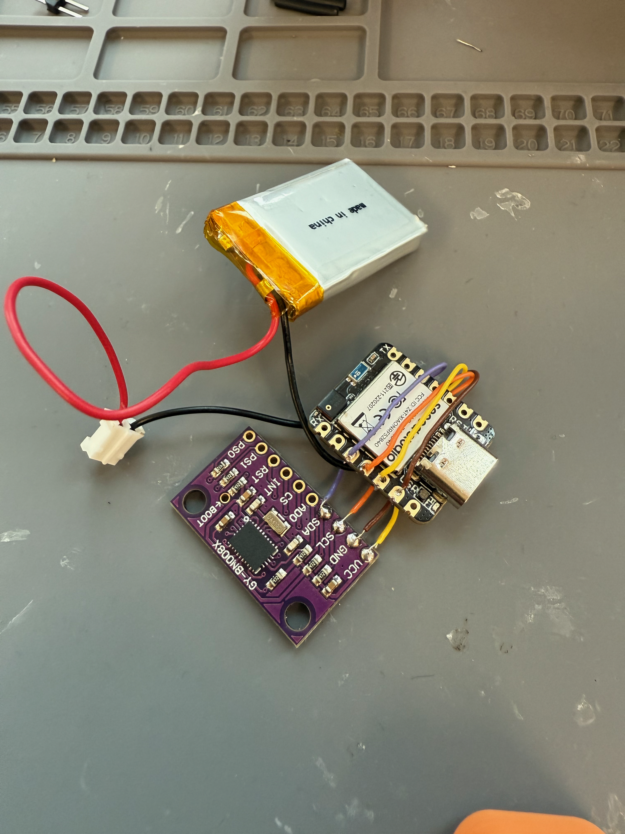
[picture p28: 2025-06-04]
images/assemble-2-solder-imu.png

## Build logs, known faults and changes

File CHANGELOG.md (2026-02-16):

# Changelog

All notable changes to this project will be documented in this file.

This project follows [Semantic Versioning](https://semver.org/).

## [2.1.0] – 2026-10-13
### Added
- Battery reporting for the left side devices

### Changed

### Fixed

### Removed
- 

## [2.0.1] – 2026-10-13
### Added

### Changed

### Fixed
- Fixed low child transmition rate errors

### Removed
- 

## [2.0.0] – 2026-01-10
### Notes
Not backwards compatible. Requires App version 2.0.0+

### Added

### Changed
- Major reworking of hub <> child architectue
- Right sides are now hubs, all left sides connect to right side

### Fixed
- This fixes Android BLE limitations

### Removed
- 

## [1.0.1] – 2026-01-10
### Added

### Changed

### Fixed
- Calibration Error
- Reset all services to fully reset the state

### Removed
- Battery debug

## [1.0.0] – 2026-01-08
### Added
- Raw data support (required by app)
- Central versioning
- Battery monitoring for battery-aware devices (Batch 2+)

### Changed
- App compilation size to accomodate a larger firmware

### Fixed
- 

### Removed
- Battery debug

---

## [0.1.0] – 2025-10-01
### Added
- Initial firmware scaffolding
- BLE services and characteristics
- Basic device configuration and streaming
- Batch one device participation

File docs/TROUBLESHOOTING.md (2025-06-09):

# Troubleshooting Guide

## Firmware Issues

### Device Won't Start / LED Flashing Rapidly

**Symptoms:**
- LED flashes rapidly on startup
- Device doesn't appear in Bluetooth scan

**Causes:**
- IMU initialization failure
- I2C communication error

**Solutions:**
1. Check IMU connections (SDA/SCL pins)
2. Verify IMU is powered (3.3V)
3. Re-flash firmware
4. Check for physical damage to IMU

### Device Not Advertising

**Symptoms:**
- Device powered on but not visible in BLE scan
- No "Eidon Tracker-XXXX" in device list

**Solutions:**
1. Reset device by power cycling
2. Check battery level (may be too low)
3. Verify firmware upload was successful
4. Use nRF Connect app to scan for any BLE devices
5. Check if device is already connected to another host

### Firmware Upload Fails

**Error Messages:**
- "No DFU capable USB device available"
- "Upload error: Failed to upload"

**Solutions:**
1. Enter DFU mode manually:
   ```
   - Connect via USB
   - Open serial monitor (115200 baud)
   - Send 'D' character
   - Device should enter DFU mode
   ```
2. Try different USB cable (data capable)
3. Install/update USB drivers
4. Use PlatformIO instead of Arduino IDE

## Bluetooth Connectivity Issues

### iOS: Device Connects but No Data

**Symptoms:**
- Device connects successfully
- No quaternion data received
- Characteristics appear empty

**Solutions:**
1. Ensure using GATT service (not HID)
2. Enable notifications on quaternion characteristic
3. Check for proper UUID formatting (uppercase)
4. Verify iOS app has Bluetooth permissions

### Android: Location Permission Required

**Symptoms:**
- Bluetooth scan finds no devices
- Permission errors in logs

**Solutions:**
1. Enable location permissions for app
2. Ensure location services are on
3. Add all required permissions to manifest:
   ```xml
   <uses-permission android:name="android.permission.ACCESS_FINE_LOCATION"/>
   <uses-permission android:name="android.permission.BLUETOOTH_SCAN"/>
   <uses-permission android:name="android.permission.BLUETOOTH_CONNECT"/>
   ```

### Connection Drops Frequently

**Symptoms:**
- Device disconnects after few seconds/minutes
- Intermittent data loss

**Solutions:**
1. Reduce distance between device and phone
2. Check for interference (2.4GHz WiFi, microwaves)
3. Update connection parameters:
   ```dart
   await device.requestConnectionPriority(ConnectionPriority.high);
   ```
4. Implement reconnection logic in app
5. Check battery level (low battery affects stability)

## Data Quality Issues

### Quaternion Values Seem Wrong

**Symptoms:**
- Rotation doesn't match physical movement
- Values jumping erratically
- Drift over time

**Solutions:**
1. Calibrate IMU:
   - Send calibration command (0x01)
   - Or double-tap device
   - Wait for blue LED sequence
2. Ensure device is mounted rigidly
3. Check for magnetic interference
4. Verify quaternion parsing (little-endian floats)

### Missing Data Frames

**Symptoms:**
- Gaps in recorded data
- Lower than expected frame rate

**Solutions:**
1. Check BLE connection interval settings
2. Process data in separate thread/isolate
3. Implement buffering in mobile app
4. Monitor for BLE congestion (too many devices)

### Switch States Incorrect

**Symptoms:**
- isLeft/isUpper values wrong
- Switch states not updating

**Solutions:**
1. Check physical switch connections
2. Verify switch pin assignments in firmware
3. Test switches with multimeter
4. Check for short circuits

## Battery and Power Issues

### Battery Drains Too Quickly

**Expected Battery Life:**
- Active use: 8-12 hours
- Standby: 24-48 hours

**Solutions:**
1. Check for firmware bugs causing high CPU usage
2. Reduce IMU sampling rate if possible
3. Optimize BLE connection interval
4. Ensure device enters sleep mode when disconnected

### Device Won't Charge

**Symptoms:**
- No charging LED indication
- Battery level doesn't increase

**Solutions:**
1. Try different USB-C cable
2. Check charging pins for debris
3. Verify charger provides adequate current (>100mA)
4. Check CHG pin state (should be LOW when charging)

### Incorrect Battery Level Reading

**Symptoms:**
- Battery percentage jumps around
- Shows 0% or 100% incorrectly

**Solutions:**
1. Calibrate battery monitoring:
   - Fully discharge device
   - Fully charge device
   - Battery readings should stabilize
2. Check voltage divider components
3. Verify ADC configuration in firmware

## Mobile App Issues

### Flutter: Multiple Device Connection Fails

**Symptoms:**
- Can connect to one device but not multiple
- Second device connection times out

**Solutions:**
1. Ensure each device has unique connection handling
2. Don't share characteristics between devices
3. iOS limit: Maximum 6 simultaneous connections
4. Android: Check manufacturer limits (usually 7-10)

### Data Recording Gaps

**Symptoms:**
- Recorded sessions have missing segments
- Video doesn't sync with motion data

**Solutions:**
1. Implement proper timestamping:
   ```dart
   final timestamp = DateTime.now().toUtc();
   ```
2. Buffer data before writing to storage
3. Use high-priority background task
4. Monitor app lifecycle events

### Upload Failures

**Symptoms:**
- Session data fails to upload
- Timeout errors

**Solutions:**
1. Implement retry logic with exponential backoff
2. Chunk large uploads
3. Compress data before upload
4. Check network connectivity before upload
5. Use background upload tasks

## Hardware Issues

### Physical Damage

**Prevention:**
- Use protective enclosure (IP67 rated)
- Strain relief on cables
- Secure mounting to prevent impacts

**Common Failures:**
- Broken I2C traces: Re-solder connections
- Damaged USB port: Replace or use wireless charging
- Water damage: Dry thoroughly, may need replacement

### EMI/RFI Interference

**Symptoms:**
- Data corruption
- Connection instability near certain equipment

**Solutions:**
1. Add shielding to enclosure
2. Use shorter I2C cables
3. Add ferrite beads to power lines
4. Keep away from strong magnetic fields

## Debug Tools and Techniques

### Serial Monitor Debugging
```bash
# PlatformIO
pio device monitor -b 115200

# Arduino CLI
arduino-cli monitor -p /dev/ttyACM0 -b 115200
```

### BLE Debugging Tools
1. **nRF Connect** (Mobile): 
   - Scan for devices
   - Inspect services/characteristics
   - Send test commands

2. **Wireshark** (Desktop):
   - Capture BLE packets
   - Analyze protocol issues

3. **Web Bluetooth** (Chrome):
   - Quick testing from browser
   - JavaScript console for debugging

### Firmware Debug Flags
Add to firmware for verbose output:
```cpp
#define DEBUG_QUATERNION 1
#define DEBUG_BLE 1
#define DEBUG_BATTERY 1
```

## Getting Help

### Information to Provide
When reporting issues, include:
1. Firmware version
2. Device hardware revision
3. Mobile OS version
4. Error messages/logs
5. Steps to reproduce

### Support Channels
- GitHub Issues: Bug reports and feature requests
- Discord: Community support
- Email: support@eidon.ai for critical issues

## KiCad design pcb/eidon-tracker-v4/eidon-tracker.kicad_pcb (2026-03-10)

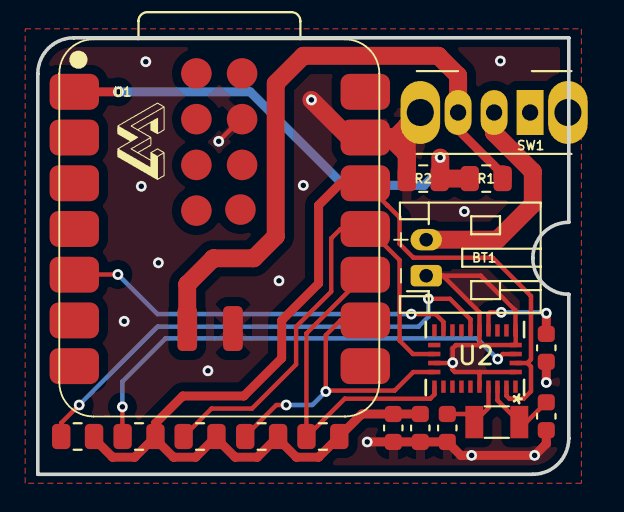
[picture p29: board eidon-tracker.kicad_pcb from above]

Board: 2 copper layers, 29.5 x 24.2 mm, 19 parts (1 on the bottom side), 14 nets.

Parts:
BT1: Battery; JST_PH_S2B-PH-K_1x02_P2.00mm_Horizontal_Inversed
C1, C2: 22pF; C_0603_1608Metric
C3, C4, C5: 100nF; C_0603_1608Metric
G1, G1#2: LOGO
R1, R2: 220kΩ; R_0805_2012Metric
R3, R4: 2.2kΩ; R_0805_2012Metric
R5, R6, R7: 10kΩ; R_0805_2012Metric
SW1: SW_SPDT; SW_Slide_SPDT_Angled_CK_OS102011MA1Q
U1: XIAO-ESP32-C6; XIAO-ESP32C6-SMD
U2: BNO085
X1: 32.768KHz; Crystal_SMD_3215-2Pin_3.2x1.5mm

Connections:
/BAT_EXT: BT1.1 (+), SW1.2 (B)
/BAT_INT: R1.2, SW1.3 (C), U1.15 (BAT)
/BAT_LVL: R1.1, R2.1, U1.1 (GPIO0_A0_D0)
/BOOTN: R5.1, U2.4 (BOOTN)
/CAP: C3.2, U2.9 (CAP)
/INT: U1.5 (GPIO22_D4_SDA), U2.14 (H_INTN)
/RST: R6.1, U2.11 (NRST)
/SCL: R3.1, U1.9 (GPIO19_D8_SCK), U2.19 (H_SCL/SCK/RX)
/SDA: R4.1, U1.10 (GPIO20_D9_MISO), U2.20 (H_SDA/H_MISO/TX)
/SDO: R7.1, U1.11 (GPIO18_D10_MOSI), U2.17 (SA0/H_MOSI)
/XIN: C1.2, U2.27 (XIN32), X1.1
/XOUT: C2.2, U2.26 (XOUT32/CLKSEL1), X1.2
GND: BT1.2 (-), C1.1, C2.1, C3.1, C4.1, C5.1, R2.2, SW1.4 (S), U1.13 (GND), U1.16 (GND), U1.20 (GND), U2.2 (GND), U2.5 (PS1), U2.6 (PS0/WAKE), U2.10 (CLKSEL0), U2.18 (H_CSN), U2.25 (GND)
VCC: C4.2, C5.2, R3.2, R4.2, R5.2, R6.2, R7.2, U1.12 (3V3), U2.3 (VDD), U2.28 (VDDIO)

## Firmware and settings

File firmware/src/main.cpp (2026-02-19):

#include <Arduino.h>
#include <string>
#include <NimBLEDevice.h>
#include <NimBLEServer.h>
#include <NimBLEUtils.h>
#include <NimBLECharacteristic.h>
#include <WiFi.h>
#include <esp_now.h>
#include "BNO085.h"
#include "BLE_Services/BLE_Callbacks.h"
#include "Role_Services/RoleConfig_Service.h"
#include "Role_Services/HubClient_Service.h"
#include "BLE_Services/BLE_Polling_Service.h" //TODO: Move this from BLE Services
#include "DeviceConfig.h"
#include "Role_Services/Hub_Structures.h"
#include "Version.h"

// Function declarations
void sendQuaternionReport();
void updateStatusLED();
void startIMUResetPattern();
bool isConnected();
void updateAdvertisingData();
float readBatteryVoltage();
uint8_t calculateBatteryPercentage(float voltage);
void updateBatteryLevel();

// ESP-NOW sender functions for child devices
bool initializeESPNowSender();
void sendESPNowQuaternionData();
void sendESPNowRawData(); // Add declaration for raw data sender
void updateESPNowHubMacAddress();
void restoreESPNowPeers();  // ESP-NOW peer recovery function

// Hub client functions are now in Role_Services/HubClient_Service.h

// Polling system functions (implemented in BLE_Polling_Service.cpp)
void setupPollingSystem();
void handleRoleChange(const std::string& value, bool success);

// Polling manager instance (defined in BLE_Polling_Service.h)
extern BLEPollingManager pollingManager;

// Static callback instances to prevent memory deallocation issues
static ServerCallbacks serverCallbacksInstance;
static QuaternionCharCallbacks quaternionCallbacksInstance;
// HubClientCallbacks moved to HubClient_Service.cpp
// RoleConfig callbacks removed - using polling instead

// BNO085 IMU instance
BNO085 imu;

// Custom GATT Service UUIDs
#define EIDON_SERVICE_UUID        "E1D00001-8B5A-3E5B-9E23-4F9B5C91BBDE"
#define QUATERNION_CHAR_UUID      "E1D00002-8B5A-3E5B-9E23-4F9B5C91BBDE"  // MAIN quaternion (device's own data)
#define CALIBRATION_CHAR_UUID     "E1D00003-8B5A-3E5B-9E23-4F9B5C91BBDE"
#define DEVICE_INFO_CHAR_UUID     "E1D00005-8B5A-3E5B-9E23-4F9B5C91BBDE"

// MAIN Raw Data Characteristic (device's own raw data - all devices use this)
#define HUB_RAW_DATA_CHAR_UUID      "E1D0000B-8B5A-3E5B-9E23-4F9B5C91BBDE"  // Also known as MAIN_RAW_DATA_CHAR_UUID

// Message type constants for ESP-NOW packets
#define MESSAGE_TYPE_QUAT 0x01    // Quaternion data
#define MESSAGE_TYPE_CMD  0x02    // Command

// Characteristic UUIDs for device data
// MAIN characteristics: Device's own data (all devices use these)
// Note: MAIN quaternion uses QUATERNION_CHAR_UUID (already defined above)
// Note: MAIN raw data uses HUB_RAW_DATA_CHAR_UUID (already defined above)

// LEFT characteristics: Left child data (right hubs only - receives ESP-NOW from left child)
#define LEFT_QUATERNION_CHAR_UUID  "E1D00008-8B5A-3E5B-9E23-4F9B5C91BBDE"  // Left child quaternion data
#define LEFT_RAW_DATA_CHAR_UUID    "E1D0000C-8B5A-3E5B-9E23-4F9B5C91BBDE"  // Left child raw data
#define LEFT_BATTERY_CHAR_UUID     "E1D0000D-8B5A-3E5B-9E23-4F9B5C91BBDE"  // Left child battery level

// QuaternionData structure is now defined in Role_Services/Hub_Structures.h
QuaternionData gattQuaternionData;
// RawMotionData gattRawData; // Removed redundant global variable - using local vars or member access

// Global quaternion variables (for backward compatibility)
float quaternion_x = 0;
float quaternion_y = 0;
float quaternion_z = 0;
float quaternion_w = 1;

// Update interval (milliseconds)
const unsigned long UPDATE_INTERVAL = 1;
unsigned long lastUpdate = 0;

// Add rate limiting for BLE notifications
const unsigned long BLE_NOTIFICATION_INTERVAL = 20; // Send every 20ms (50Hz) for stability instead of 10ms
unsigned long lastNotificationTime = 0;

// Add transmission rate limiting for main loop
const unsigned long TRANSMISSION_INTERVAL = 42; // 24Hz max (41.67ms interval) to match ESP-NOW
unsigned long lastTransmission = 0;

// Track subscription status
bool quaternionSubscribed = false;

// ESP-NOW sender variables for child devices
bool espNowInitialized = false;
uint8_t hubMacAddress[6];
bool hubMacAssigned = false;
unsigned long lastESPNowTransmission = 0;
const unsigned long ESP_NOW_INTERVAL = 21; // 48 Hz (20.83ms interval) - redundancy approach for packet loss

// ESP-NOW error handling and timeout
unsigned long lastESPNowError = 0;
const unsigned long ESP_NOW_ERROR_TIMEOUT = 5000; // 5 seconds between error logs
int espNowErrorCount = 0;

// Child device periodic logging system
const unsigned long CHILD_LOG_INTERVAL = 30000; // 30 seconds for periodic updates (optimized for battery)
unsigned long lastChildLogTime = 0;
unsigned long imuUpdateCount = 0;
unsigned long espNowSendCount = 0;
unsigned long lastHubStatusCheck = 0;
const unsigned long HUB_STATUS_CHECK_INTERVAL = 40000; // 40 seconds (5x the regular interval)

// Raw data logging interval for debugging
const unsigned long RAW_DATA_LOG_INTERVAL = 5000; // 5 seconds for raw data logs
unsigned long lastRawDataLogTime = 0;

// BLE advertising timeout for child devices
const unsigned long BLE_STARTUP_TIMEOUT = 45000; // 45 seconds for devices that start as children
const unsigned long BLE_DISCONNECT_TIMEOUT = 60000; // 60 seconds after role change to child
unsigned long startupTime = 0;
unsigned long disconnectTime = 0; // Time when device last disconnected
bool startupTimedOut = false;
bool disconnectTimedOut = false;

// IMU rate limiting for both child and hub devices
unsigned long lastIMUUpdate = 0;
const unsigned long IMU_UPDATE_INTERVAL = 21; // 48 Hz (20.83ms interval) - matches ESP-NOW rate for redundancy

// LED pin - Seeed XIAO ESP32-C6 onboard LED is on GPIO15
#define LED_PIN 15

// Status LED pin (second LED for simple status indication on GPIO1)
#define STATUS_LED_PIN A1

// User button (wired in parallel with boot button on GPIO9)
#define USER_BUTTON_PIN 9
unsigned long buttonLastPressed = 0;
const unsigned long BUTTON_DEBOUNCE_MS = 300;

// Status LED variables
const unsigned long STATUS_LED_BLINK_INTERVAL = 500; // Blink every 500ms when advertising

// Battery level monitoring (following Seeed XIAO ESP32 wiki)
#define BATTERY_ADC_PIN 0  // GPIO0 (A0)
const float VOLTAGE_DIVIDER_RATIO = 2.0;  // Voltage divider with two equal resistors (R1 = R2)
const float ADC_REFERENCE_VOLTAGE = 3.3;  // ESP32-C3 ADC reference voltage
const int ADC_RESOLUTION = 4095;  // 12-bit ADC (0-4095)
unsigned long lastBatteryRead = 0;
const unsigned long BATTERY_READ_INTERVAL = 5000; // Read battery every 5 seconds (for debugging)
float batteryVoltage = 0.0;
uint8_t batteryPercentage = 100;
bool batteryPresent = true;

// Battery detection thresholds
const float BATTERY_MIN_VALID_VOLTAGE = 2.5;  // Below this = no battery present
const float BATTERY_FLOATING_MIN = 3.8;       // Floating ADC typically reads in this range
const float BATTERY_FLOATING_MAX = 4.0;       // when USB powered but no battery

// LED status variables
unsigned long ledLastUpdate = 0;
// LED patterns
enum LEDPattern {
    LED_ADVERTISING,  // Strobing brightness when advertising
    LED_CONNECTED,    // Fast blinking when connected
    LED_IMU_RESET     // Solid LED when resetting IMU
};
LEDPattern currentLEDPattern = LED_ADVERTISING;
unsigned long imuResetStartTime = 0;
const unsigned long IMU_RESET_DURATION = 300; // Solid LED duration in ms
int ledBrightness = 0;
bool ledState = false;

// Simple timer for debugging LED

// LED brightness settings

// Add interrupt flag for faster sensor reading
volatile bool sensorDataReady = false;

// BLE connection state variables (moved up for LED functions)
bool deviceConnected = false;

// Interrupt service routine
void IRAM_ATTR sensorISR() {
    sensorDataReady = true;
}

// Function to trigger IMU reset LED pattern
void startIMUResetPattern() {
    currentLEDPattern = LED_IMU_RESET;
    imuResetStartTime = millis();
}

// Drives both LED_PIN (active-low) and STATUS_LED_PIN (active-high)
static void setLEDs(bool on) {
    digitalWrite(LED_PIN, on ? LOW : HIGH);
    digitalWrite(STATUS_LED_PIN, on ? HIGH : LOW);
}

// Unified LED update for both onboard and status LEDs
void updateStatusLED() {
    unsigned long currentTime = millis();

    // IMU reset pattern takes priority - solid ON
    if (currentLEDPattern == LED_IMU_RESET) {
        setLEDs(true);
        if (currentTime - imuResetStartTime >= IMU_RESET_DURATION) {
            currentLEDPattern = isConnected() ? LED_CONNECTED : LED_ADVERTISING;
            ledLastUpdate = currentTime;
        }
        return;
    }

    if (isConnected()) {
        // Solid ON when connected
        setLEDs(true);
    } else {
        // Blink when advertising
        if (currentTime - ledLastUpdate >= STATUS_LED_BLINK_INTERVAL) {
            ledLastUpdate = currentTime;
            ledState = !ledState;
            setLEDs(ledState);
        }
    }
}

// Function to read battery voltage from ADC
// Returns battery voltage in volts
// Following official Seeed XIAO ESP32C6 wiki example
float readBatteryVoltage() {
    // Read ADC value in millivolts (average of 16 samples as per Seeed wiki)
    uint32_t Vbatt = 0;
    const int numSamples = 16;

    for (int i = 0; i < numSamples; i++) {
        Vbatt += analogReadMilliVolts(A0); // Read and accumulate ADC voltage in mV
    }

    // Adjust for 1:2 voltage divider and convert to volts
    float Vbattf = 2.0 * Vbatt / numSamples / 1000.0;

    // Detect battery presence
    // When USB powered but no battery, ADC floats around 3.8-4.0V (giving false 80% reading)
    if (Vbattf < BATTERY_MIN_VALID_VOLTAGE) {
        batteryPresent = false;
    } else if (Vbattf >= BATTERY_FLOATING_MIN && Vbattf <= BATTERY_FLOATING_MAX) {
        // Likely floating ADC reading (USB powered, no battery)
        batteryPresent = false;
    } else {
        batteryPresent = true;
    }

    return Vbattf;
}

// Function to calculate battery percentage from voltage
// LiPo battery: 4.2V (100%) to 3.0V (0%)
uint8_t calculateBatteryPercentage(float voltage) {
    const float BATTERY_MAX_VOLTAGE = 4.2;  // Fully charged LiPo
    const float BATTERY_MIN_VOLTAGE = 3.0;  // Discharged LiPo (safe cutoff)

    uint8_t result;
    if (voltage >= BATTERY_MAX_VOLTAGE) {
        result = 100;
    } else if (voltage <= BATTERY_MIN_VOLTAGE) {
        result = 0;
    } else {
        // Linear interpolation
        float percentage = ((voltage - BATTERY_MIN_VOLTAGE) / (BATTERY_MAX_VOLTAGE - BATTERY_MIN_VOLTAGE)) * 100.0;
        result = (uint8_t)percentage;
    }


    return result;
}

// BLE objects
NimBLEServer* pServer = nullptr;

// Custom GATT Service
NimBLEService* eidonService = nullptr;
NimBLECharacteristic* quaternionChar = nullptr;  // MAIN quaternion (device's own data - all devices use this)
NimBLECharacteristic* calibrationChar = nullptr;
NimBLECharacteristic* deviceInfoChar = nullptr;

// MAIN characteristics (device's own data):
NimBLECharacteristic* hubRawDataChar = nullptr;  // MAIN raw data (device's own raw data - all devices use this)

// LEFT characteristics (left child data - right hubs only)
NimBLECharacteristic* leftQuaternionChar = nullptr;  // Left child quaternion data
NimBLECharacteristic* leftRawDataChar = nullptr;     // Left child raw data
NimBLECharacteristic* leftBatteryChar = nullptr;     // Left child battery level

// Function to get current BLE connection state (similar to Bluefruit.connected())
bool isConnected() {
    return deviceConnected; // Simple state tracking like reference code
}

// Function to update advertising data with current role information
void updateAdvertisingData() {
    NimBLEAdvertising* pAdvertising = NimBLEDevice::getAdvertising();
    if (pAdvertising == nullptr) return;
    
    // Stop current advertising
    pAdvertising->stop();
    
    // Update device name
    String deviceName = deviceConfig.generateDeviceName();
    NimBLEDevice::setDeviceName(deviceName.c_str());
    pAdvertising->setName(deviceName.c_str());
    
    // Update role information in manufacturer data
    // Format: [Company ID Low, Company ID High, Role Data]
    uint8_t manufacturerDataBytes[3];
    manufacturerDataBytes[0] = 0xD0;        // Company ID low byte (0xD0)
    manufacturerDataBytes[1] = 0xE1;        // Company ID high byte (0xE1)
    manufacturerDataBytes[2] = (uint8_t)deviceConfig.getRole(); // Role data
    
    NimBLEAdvertisementData manufacturerData;
    manufacturerData.setManufacturerData(manufacturerDataBytes, 3);
    pAdvertising->setAdvertisementData(manufacturerData);
    
    // Update scan response data
    NimBLEAdvertisementData scanResponse;
    scanResponse.setName(deviceName.c_str());
    pAdvertising->setScanResponseData(scanResponse);
    
    // Restart advertising with updated data
    pAdvertising->start();
    

}
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
void loop() {
    // Single millis() call for all timing operations
    unsigned long currentTime = millis();

    // Update both onboard and status LEDs
    updateStatusLED();

    // Check user button (active-low: LOW when pressed)
    if (digitalRead(USER_BUTTON_PIN) == LOW && (currentTime - buttonLastPressed >= BUTTON_DEBOUNCE_MS)) {
        buttonLastPressed = currentTime;
        // TODO: uncomment to trigger IMU reset on button press
        // imu.reset();
        // Serial.println("BUTTON: IMU reset triggered");
    }

    // Update battery level (periodic reading - updates device info characteristic silently)
    updateBatteryLevel();

    // Simplified connection state management for maximum performance (like reference code)
    bool actuallyConnected = (pServer->getConnectedCount() > 0);
    if (actuallyConnected != deviceConnected) {
        deviceConnected = actuallyConnected;
        // Minimal logging to avoid delays
        if (deviceConnected) {
            Serial.println("----- BLE Connected -----");
            
            // Re-initialize ESP-NOW after BLE connection to prevent conflicts
            if (deviceConfig.isHubMode()) {
                // Force WiFi channel back to ESP-NOW channel
                WiFi.setChannel(1);
                delay(100); // Give WiFi time to settle
                
                // Force complete ESP-NOW re-initialization
                esp_now_deinit();
                delay(100);
                
                if (esp_now_init() == ESP_OK) {
                    esp_now_set_pmk((uint8_t*)"pmk1234567890123");
                    esp_now_register_recv_cb(onESPNowDataRecv);
                    
                    // Restore ESP-NOW peer registrations after reinitialization
                    restoreESPNowPeers();
                }
            }
            
            // Force reset LED state and start fresh pattern
            digitalWrite(LED_PIN, LOW);  // Start with LED OFF
            ledState = false;
            ledLastUpdate = 0; // Force immediate update
            currentLEDPattern = LED_CONNECTED;
            
            // Reset polling disabled log flag for children
            if (deviceConfig.isNodeMode()) {
                // Reset the static flag by calling a function that can access it
                // This will be handled in the polling update section
            }
        } else {
            Serial.println("BLE: Disconnected");
            // Record disconnection time for child devices
            if (deviceConfig.isNodeMode()) {
                disconnectTime = currentTime;
                disconnectTimedOut = false; // Reset disconnect timeout flag
            }
            NimBLEDevice::startAdvertising();
            currentLEDPattern = LED_ADVERTISING; // Switch to advertising LED pattern
        }
    }
    
    // Rate-limited IMU updates for both child and hub devices (48Hz)
    if (currentTime - lastIMUUpdate >= IMU_UPDATE_INTERVAL) {
        imu.update();
        imuUpdateCount++; // Track IMU updates for periodic logging
        lastIMUUpdate = currentTime;
        
        // For child devices: Send ESP-NOW data immediately after every IMU update (48Hz redundancy approach)
        if (deviceConfig.isNodeMode() && (deviceConfig.getRole() == ROLE_LEFT_HAND || 
                                          deviceConfig.getRole() == ROLE_LEFT_FOREARM || 
                                          deviceConfig.getRole() == ROLE_LEFT_SHOULDER)) {
            sendESPNowQuaternionData();
            
            // Send raw data at half rate (24Hz) since sensor only updates at 25Hz
            static bool sendRawNext = true;
            if (sendRawNext) {
                sendESPNowRawData(); 
            }
            sendRawNext = !sendRawNext;
        }
    }
    
    // Update BLE polling system (skip when BLE timeout is up on children)
    if (!deviceConfig.isNodeMode() || deviceConnected || (!startupTimedOut && !disconnectTimedOut)) {
        // Reset polling disabled log flag when polling is active
        static bool pollingDisabledLogged = false;
        if (pollingDisabledLogged) {
            pollingDisabledLogged = false;
        }
        pollingManager.update();
    } else if (deviceConfig.isNodeMode() && !deviceConnected) {
        // Log once when polling is disabled for children
        static bool pollingDisabledLogged = false;
        if (!pollingDisabledLogged) {
            Serial.println("CHILD: BLE polling disabled - ESP-NOW only mode active");
            pollingDisabledLogged = true;
        }
    }
    
    // Update hub client service (only if we're a hub)
    if (deviceConfig.isHubMode()) {
        updateHubClientService(deviceConnected);
        
        // Check for child disconnections every second
        static unsigned long lastDisconnectCheck = 0;
        if (currentTime - lastDisconnectCheck >= 1000) {
            checkChildDisconnections();
            lastDisconnectCheck = currentTime;
        }
    }
    
    // Send data if connected
    if (deviceConnected) {
        // Rate limit data transmission to prevent overwhelming BLE connection
        static unsigned long lastTransmission = 0;
        const unsigned long TRANSMISSION_INTERVAL = 42; // 24Hz max (41.67ms interval) to match ESP-NOW
        
        if (currentTime - lastTransmission >= TRANSMISSION_INTERVAL) {
            lastTransmission = currentTime;
            // Send quaternion report if connected
            sendQuaternionReport();
            
            // Send raw data report if connected
            if (isConnected()) {
                // 1. Hub Raw Data (hub devices send their own raw data)
                if (deviceConfig.isHubMode() && hubRawDataChar != nullptr && imu.isAvailable()) {
                    RawMotionData hubRaw;
                    imu.getRawData(hubRaw);
                    hubRawDataChar->notify((uint8_t*)&hubRaw, sizeof(hubRaw));
                }
                
                // 2. Child Raw Data (child devices send their own raw data when connected to phone)
                if (deviceConfig.isNodeMode() && hubRawDataChar != nullptr && imu.isAvailable()) {
                    RawMotionData childRaw;
                    imu.getRawData(childRaw);
                    hubRawDataChar->notify((uint8_t*)&childRaw, sizeof(childRaw));
                }

                // 3. LEFT Child Raw Data from ESP-NOW (right hubs forward left child data received via ESP-NOW)
                // Note: Chest hub has no children, so this section will not send data for chest
                if (deviceConfig.isHubMode() && leftRawDataChar != nullptr) {
                    // Access child devices to get their latest raw data
                    // Each right hub has exactly one left child (hand, forearm, or shoulder)
                    ESPNowChildDevice* children = getChildDevices();
                    int childCount = MAX_CHILDREN;
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

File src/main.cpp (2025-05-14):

#include <Arduino.h>
#include <Adafruit_BNO08x.h>
#include <bluefruit.h>
#include <stdint.h>

// For the built-in LED
#define LED_PIN PIN_LED

// LSM6DS3TR-C I2C pins and Address (for XIAO nRF52840 Sense built-in IMU)
// #define LSM6DS_I2C_SDA 6  // SDA pin
// #define LSM6DS_I2C_SCL 7  // SCL pin
// #define LSM6DS_I2C_ADDR 0x6A // Address

// BNO085 I2C pins and Address (for external IMU)
#define BNO085_I2C_SDA 9
#define BNO085_I2C_SCL 10
#define BNO085_I2C_ADDR 0x4B // Address

// Vendor and Product IDs
#define VENDOR_ID  0xE1D0 // Eidon AI vendor ID
#define PRODUCT_ID 0x0002 // Eidon Tracker product ID

// HID Report Descriptor for a custom device with 4 quaternion values and switch states
uint8_t const hid_report_descriptor[] = {
  0x05, 0x20,                  //  UsagePage (Sensor)
  0x09, 0x80,                  //  Usage (Orientation)
  0xA1, 0x01,                  //  Collection (Application)

  0x85, 0x01,                  //  Report ID (1)

  // 4×16-bit quaternion components (i, j, k, real)
  0x0A, 0x83, 0x04,            //  Usage 0x0483 – Data Field: Quaternion
  0x75, 0x10,                  //  ReportSize 16
  0x95, 0x04,                  //  ReportCount 4
  0x17, 0x00, 0x00, 0x00, 0x00,// Logical Minimum  0      (32-bit form)
  0x27, 0xFF, 0xFF, 0x00, 0x00,// Logical Maximum  65535  (32-bit form)
  0x81, 0x02,                  //  Input (Data,Var,Abs)

  // Optional switch byte – put it on the Button page so hosts know it's a button
  0x05, 0x09,                  //  UsagePage (Button)
  0x19, 0x01,                  //  UsageMinimum (Button 1)
  0x29, 0x02,                  //  UsageMaximum (Button 2)  ← up to you
  0x95, 0x02,                  //  ReportCount 2
  0x75, 0x01,                  //  ReportSize 1
  0x15, 0x00, 0x25, 0x01,      //  LogicalMin 0, LogicalMax 1
  0x81, 0x02,                  //  Input (Data,Var,Abs)
  0x95, 0x06, 0x75, 0x01, 0x81, 0x03, // padding bits

  0xC0,                           // End Orientation Collection

  // ── Second top-level collection : vendor I/O ─────────────────────────
  0x06, 0x00, 0xFF,            //  UsagePage (Vendor-defined 0xFF00)
  0x09, 0x01,                  //  Usage (Vendor usage 1)
  0xA1, 0x01,                  //  Collection (Application)

  0x85, 0x01,                  //    Report ID (1) – command channel
  0x15, 0x00, 0x26, 0xFF, 0x00,//    Logical Min 0, Logical Max 255
  0x75, 0x08,                  //    Report Size 8 bits
  0x95, 0x01,                  //    Report Count 1
  0x09, 0x01,                  //    Usage (Vendor usage 1)
  0x91, 0x02,                  //    Output (Data,Var,Abs)

  0xC0                            //  End Vendor Collection
};

// HID report map - now 9 bytes total (8 bytes for quaternion + 1 byte for switch states)
uint8_t report_data[9] = {0};

// Add output report buffer
uint8_t output_report[1] = {0};

// BNO085 sensor
Adafruit_BNO08x bno08x;
sh2_SensorValue_t sensorValue;

// Orientation data
struct euler_t {
    float yaw;
    float pitch;
    float roll;
} ypr = {0, 0, 0};

float quaternion_x = 0;
float quaternion_y = 0;
float quaternion_z = 0;
float quaternion_w = 1;

// Bluetooth HID
BLEDis bledis;
BLEHidGeneric blehid(1, 2, 0);

// Battery Service
BLEBas blebas;

// Update interval (milliseconds)
const unsigned long UPDATE_INTERVAL = 1;
unsigned long lastUpdate = 0;

// -----------------------------------------------------------------------------
// Battery-monitoring constants and helpers
// Xiao nRF52840 Sense routes VBAT through a resistor divider ( ≈ 2.961 : 1 ) to
// pin P0.31 (alias PIN_VBAT).
// The nRF52 ADC is configured for a 0.6 V reference with gain ×6 → 3.6 V full-scale
// and 12-bit resolution (0–4095).  Use the same settings recommended by Seeed.
// -----------------------------------------------------------------------------
const float ADC_REF_VOLTAGE   = 3.6f;       // 0.6 V × 6 gain
const uint16_t ADC_MAX_COUNT  = 4095;       // 12-bit ADC
const float VBAT_DIVIDER_RATIO = 2.961f;    // Empirically measured divider ratio
const int   BAT_MONITOR_EN_PIN = 14;        // P0.14 controls divider (LOW = measure)

// Battery monitoring pins
#define PIN_VBAT        (32)  // D32 battery voltage
#define PIN_VBAT_ENABLE (14)  // D14 LOW:read anable
#define PIN_HICHG       (22)  // D22 charge current setting LOW:100mA HIGH:50mA
#define PIN_CHG         (23)  // D23 charge indicatore LOW:charge HIGH:no charge

// Switch pins
#define SWITCH_OUT_LEFT_RIGHT 5  // D5 output for left/right switch
#define SWITCH_IN_LEFT_RIGHT 6   // D6 input for left/right switch
#define SWITCH_OUT_UPPER_LOWER 0 // D0 output for upper/lower switch
#define SWITCH_IN_UPPER_LOWER 1  // D1 input for upper/lower switch

// Switch states
bool isLeft = false;
bool isUpper = false;

float readVBAT(void) {
  // Enable voltage divider (active LOW)
//   pinMode(BAT_MONITOR_EN_PIN, OUTPUT);
//   digitalWrite(BAT_MONITOR_EN_PIN, LOW);
//   delayMicroseconds(300);                 // allow voltage to settle

//   (void)analogRead(PIN_VBAT);             // dummy read to discard first sample
  uint16_t adcCount = analogRead(PIN_VBAT);

  // Disable divider to save power
  digitalWrite(BAT_MONITOR_EN_PIN, HIGH);

  // Convert to volts
  float vBat = ( (float)adcCount / ADC_MAX_COUNT ) * ADC_REF_VOLTAGE * VBAT_DIVIDER_RATIO;

  return vBat;
}

// Convert voltage to battery percentage with more accurate mapping
uint8_t mvToPercent(float voltage) {
  // Debug the input voltage
  Serial.print("Input voltage: ");
  Serial.print(voltage, 3);
  Serial.println("V");
  
  // For LiPo battery
  if (voltage >= 4.2) return 100;
  if (voltage <= 3.3) return 0;
  
  // Linear mapping between 3.3V and 4.2V
  // 3.3V = 0%, 3.6V = 20%, 3.7V = 40%, 3.8V = 60%, 3.9V = 80%, 4.2V = 100%
  uint8_t percentage;
  if (voltage < 3.6) {
    percentage = (voltage - 3.3) * 66.67;  // 20% over 0.3V
  } else if (voltage < 3.7) {
    percentage = 20 + (voltage - 3.6) * 200;  // 20% over 0.1V
  } else if (voltage < 3.8) {
    percentage = 40 + (voltage - 3.7) * 200;  // 20% over 0.1V
  } else if (voltage < 3.9) {
    percentage = 60 + (voltage - 3.8) * 200;  // 20% over 0.1V
  } else {
    percentage = 80 + (voltage - 3.9) * 66.67;  // 20% over 0.3V
  }
  
  // Debug the calculated percentage
  Serial.print("Calculated percentage: ");
  Serial.print(percentage);
  Serial.println("%");
  
  return percentage;
}

void enterDFU() {
    // Enter DFU mode
    #if defined(ARDUINO_NRF52_ADAFRUIT)
        enterOTADfu();
    #else
        NRF_POWER->GPREGRET = 0x01; // Set the GPREGRET register to indicate DFU mode
        NVIC_SystemReset();         // Perform a system reset
    #endif
}
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

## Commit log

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2025-04-30 adds CAD files for device shell
    [eidon-tracker-base.stl, eidon-tracker-top.stl, eidon-tracker.f3d]
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2025-04-30 attempts to fix battery level and vendor/product ID
    [eidon-tracker.ino]
2025-04-30 fixes battery level reported?
    [eidon-tracker.ino]
2025-04-30 adds support for sensor position switches and reports their state on the HID report
2025-04-30 adds gcode used to print on eidon bambu office printer
    [eidon-tracker.gcode.3mf]
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2025-05-06 uses game rotation vector to avoid mag issues
    [main.cpp]
2025-05-10 updates cad model to include a strap mount for the tracker
    [eidon-tracker-mount.stl, eidon-tracker.f3d]
2025-05-12 disables bunch of logs and implements double tap to soft restart the IMU
2025-05-12 corrects HID descriptor bounds defined
    [main.cpp]
2025-05-13 updates HID descriptor to use proper HID usage code for sensor quaternion values
2025-05-13 fix reporting of vendor/product id for ble hid device
    [main.cpp]
2025-05-13 fixes battery level reported.. maybe; implements output report to externally send command to trigger IMU reset
    [main.cpp]
2025-05-13 cleans up dead code and resolves intellisense lint errors
    [main.cpp]
2025-05-13 fix scan name advertised to show full 'Eidon Tracker' string; disabled tap to reset IMU for now
    [main.cpp]
2025-05-14 implements unique BLE advertised name to easily tell devices apart; updates to use a common vendor/product id for eidon devices
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2025-05-19 updates model so that Eidon logo's top is oriented towards trackers calculated forward vector which is reversed to match position of IMU within the eidon glove
    [eidon-tracker-base.stl, eidon-tracker-top.stl, eidon-tracker.f3d]
2025-05-28 fix: correctly oriented IMU quaternion so that yaw North is forward of the device mounted 180 degrees around Z based on datasheet
    [main.cpp]
2025-05-29 fix: try again.. corrects misorientation
    [main.cpp]
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2025-06-04 Major repository overhaul: README redesign, web app cleanup, and assembly images - Complete README.md rewrite with PlatformIO workflow, comprehensive BOM with Amazon links, general orientation tracki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
2025-06-04 updates 3d models with eidon logo in original orientation; updates readme images
    [eidon-tracker-top.stl, eidon-tracker.f3d]
2025-06-09 Add custom GATT service for iOS compatibility and comprehensive documentation
    Firmware Changes:
    - Add custom GATT service (UUID: E1D00001-8B5A-3E5B-9E23-4F9B5C91BBDE) alongside existing BLE HID
    - Implement GATT characteristics for iOS support:
    * Quaternion data (notify/read): Real-time IMU data with switch states
    * Calibration (write/read): Trigger IMU calibration remotely
    * Color (write/read): Set device RGB color persistently
    * Device info (read): Device ID, firmware version, battery level
    - Add forward declarations to fix compilation errors
    - Refactor sendQuaternionReport() to support dual-protocol transmission
    - Update battery monitoring to also update GATT device info c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
    [main.cpp]
2025-06-24 feat: updates model base to not include extra pos switches; adds dot indicator for multiple top shells to indicate hard coded pos
    [eidon-tracker-base.stl, eidon-tracker-top-1.stl, eidon-tracker-top-2.stl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]
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2025-06-30 Implementing lag reduction issue
    [main.cpp]
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2025-07-09 feat: updates tracker models and print files
    [eidon-tracker-base.stl, eidon-tracker-batch-arms.3mf, eidon-tracker-batch-chest.3mf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]
2025-07-14 Removing HID, adding child functionality, fixing naming, and adding services for hub communication
    [BLE_Polling_Service.cpp, DeviceConfig.cpp, HubClient_Service.cpp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]
2025-07-16 Fixing platform.io issue and hub quaternion update
    [HubClient_Service.cpp, main.cpp]
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2025-07-24 Fixing critical mistake with characteristic initialization
    [HubClient_Service.cpp, main.cpp]
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2025-07-28 Fixing ESP NOW initialization
    [HubClient_Service.cpp]
2025-07-29 Setting disconnect on child role resetting
    [HubClient_Service.cpp, main.cpp]
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2025-08-14 Fixing esp now callback issue to fix calibration
    [HubClient_Service.cpp, main.cpp]
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2025-08-28 feat: adds updated models and 3d print files for new tracker mount for arms and chest
    [eidon-tracker-mount-arm.3mf, eidon-tracker-mount-arm.stl, eidon-tracker-mount-chest.3mf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]
2025-09-10 feat(pcb): creates kicad project and custom xiao esp32-c6 footprint for easy soldering of battery pads
    [Seeed Studio XIAO ESP32-C6.step, eidon-tracker.kicad_pcb, eidon-tracker.kicad_sch]
2025-09-11 feat(pcb): creates footprint and symbol for GY-BNO085 module and creates base eidon-tracker schematic and pcb design
    [GY_BNO085.step, SS12D00.step, XIAO_ESP32C6.step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]
2025-09-11 feat(pcb): implements battery connector and power switch toggle
    [eidon-tracker.kicad_pcb, eidon-tracker.kicad_sch]
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2025-09-12 feat(pcb): implements battery charging circuit and optimizes esp32-c6 footprint for what is needed
    [eidon-tracker.kicad_pcb, eidon-tracker.kicad_sch]
2025-09-12 feat(pcb): further optimizations to PCB layout and implements boot/user button
    [eidon-tracker.kicad_pcb, eidon-tracker.kicad_sch]
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2025-09-19 feat(pcb): implements button and led circuit with smd componenets; chore(pcb): cleans up schematic and adds group labels to make the parts easier to understand
    [SKRKAH.step, eidon-tracker.kicad_pcb, eidon-tracker.kicad_sch]
2025-09-19 feat(pcb): adds vias to create better connected ground planes; rotates batery connector to make it easier to plug-in the battery
    [eidon-tracker.kicad_pcb]
2025-09-23 feat(pcb): generates gerber files for fabrication
    [eidon-tracker-B_Cu.gbl, eidon-tracker-B_Mask.gbs, eidon-tracker-B_Paste.gbp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]
2025-09-23 feat(pcb): adds BOM and pick-n-place pos files needed for PCBA
    [BOM.csv, eidon-tracker.kicad_pcb, eidon-tracker.kicad_sch]
2025-09-23 fix(pcb): updates BOM and PnP files with correct placement and part numbers for JLCPCB
    [BOM.csv, eidon-tracker.kicad_pcb]
2025-09-23 feat(cad): updates chest mount with extended mid-section to fit on alternate chest mount harness
    [eidon-tracker-mount-chest-B.3mf, eidon-tracker-mount-chest-B.stl, eidon-tracker.f3z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]
2025-10-01 adds some changes left hanging on pcb
    [eidon-tracker.step]
2025-10-06 feat(pcb): creates STEP model for v3 PCB and creates archive of Fusion of new v3 PCB shell
    [eidon-tracker-v3.f3d, eidon-tracker.step]
2025-10-07 feat(pcb): builds out most of the base enclosure shell model for updated pcb
    [eidon-tracker-v3.f3d, eidon-tracker-v3.stl]
2025-10-08 feat(pcb): further fleshes out the eidon shell and adds base lid
    [eidon-tracker-v3-lid.stl, eidon-tracker-v3.f3d, eidon-tracker-v3.stl]
2025-10-17 feat(pcb): adds updated shell models for snap-in lid with number markers; isolates button component; various other shell improvments to improve fitment
    [eidon-tracker-v3-btn.stl, eidon-tracker-v3-lid-1.stl, eidon-tracker-v3-lid-2.stl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]
2025-10-21 feat(pcb): adds updated enclosure with integrated mount and extra secure screwable lid
    [eidon-tracker-v3-body.stl, eidon-tracker-v3a-body.stl, eidon-tracker-v3a-btn.stl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]
2025-10-22 feat(pcb): adds updated models for integrated tracker mount
    [eidon-tracker-v3.f3d, eidon-tracker-v3b-body.stl, eidon-tracker-v3b-lid-0.stl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]
2025-10-24 feat(firmware/pcb): add status LED and battery monitoring
    - Add second status LED on GPIO1/A1 (blinks when scanning, solid when paired)
    - Onboard LED now correctly uses GPIO15 for Seeed XIAO ESP32C6
    - Implement battery voltage monitoring on GPIO0/A0 following official Seeed wiki
    * Uses analogReadMilliVolts() with 16-sample averaging
    * 1:2 voltage divider circuit (200k resistor)
    * Battery range: 4.2V (100%) to 3.0V (0%)
    - Add battery presence detection to handle floating ADC when USB-only powered
    * Detects when no battery connected (prevents false 80% reading)
    * Reports 0% when USB powered without battery
    - Battery readings every 5 seconds with detailed debug loggi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
    [eidon-tracker.kicad_sch]
2025-10-27 revert: remove PCB LED and resistor changes
    Revert PCB schematic changes from previous commit while keeping
    firmware changes intact. The LED circuit and resistor value updates
    will be applied in a future PCB revision.
    [eidon-tracker.kicad_sch]
2025-10-27 feat(pcb): updates pcb BOM to have correct resistor value for desired LED brightness
    [BOM.csv, eidon-tracker.kicad_sch]
2025-11-04 fix(pcb): adds corrected BOM for incorrect LED resistor value
    [BOM.csv, eidon-tracker.kicad_pcb, eidon-tracker.kicad_sch]
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2025-12-31 Fixing sampling rate for raw data
    [DeviceConfig.cpp, main.cpp]
2026-01-08 Fixing firmware version reporting
    [DeviceConfig.cpp, main.cpp]
2026-01-08 Fixing BLE raw data comms
    [main.cpp]
2026-01-09 Small fix to hubs trasmitting raw data
    [main.cpp]
2026-01-11 PATCH: Fixing calibration
2026-01-30 Remove legacy PCB v3 files
    [BOM.csv, GY_BNO085.step, SKRKAH.step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]
2026-01-30 Add PCB v3 design files
    [BOM.csv, GY_BNO085.step, SKRKAH.step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]
2026-01-30 Add PCB v4 design with onboard BNO085
    Fully fab-ready design with BNO085 integrated directly on the PCB.
    [BNO085.step, BOM.csv, GY_BNO085.step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]
2026-01-30 Add chest mount CAD files
    [EIDON_TRACKER_CHEST_MOUNT.3mf, EIDON_TRACKER_CHEST_MOUNT.stl]
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2026-01-30 Add user button support on GPIO9
    Reads boot/user button with debounce. Logs press events.
    IMU reset call stubbed out for future use.
    [main.cpp]
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2026-02-05 feat(pcb): further refining traces for bno085 chip layout
    [eidon-tracker.kicad_pcb]
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2026-02-18 fix(pcb): corrects component placement so not too close to edge per jlcpcb rejection feedback
    [eidon-tracker.kicad_pcb, eidon-tracker.kicad_sch]
2026-03-10 chore(pcb): commits hanging changes with final PCB design changes
    [BOM.csv, bom.csv, designators.csv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]
